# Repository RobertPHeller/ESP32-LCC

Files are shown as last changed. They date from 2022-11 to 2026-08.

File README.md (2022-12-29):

# ESP32-LCC

This is a collection of Model Railroad open hardware and open source projects,
using LCC /  OpenMRNIDF, for the ESP32 family of MCUs

These projects were created using Kicad 2013.06.11
(https://launchpad.net/kicad) under CentOS 6 and Kicad 4.0.7 under Ubuntu
18.04. Each subdirectory is one project, and contains a schematic and PCB
design or contains a program for one (or more) projects. There is also
software for the boards using OpenMRNIDF (C++ library for OpenLCB/LCC) for these
projects.

There is a README in each project dir.

1. [ESP32-16LedDriver](https://github.com/RobertPHeller/RPi-RRCircuits/tree/master/ESP32-16LedDriver)

    > 16 on/off LED Driver board using a MCP23017.

1. [ESP32-16PWMLedDriver](https://github.com/RobertPHeller/RPi-RRCircuits/tree/master/ESP32-16PWMLedDriver)

    > 16 LED PWM driver board using a PCA9685.

1. [ESP32-16xDCCOD](https://github.com/RobertPHeller/RPi-RRCircuits/tree/master/ESP32-16xDCCOD)

    > Backplane for up to 16 DCCOD_SMD's using a ESP32 MCU.  Meant as a thought 
    > experiment to see what this would cost, etc.

1. [ESP32-D0WD-V3-MultiFunctionOpenMRNIDF](https://github.com/RobertPHeller/RPi-RRCircuits/tree/master/ESP32-D0WD-V3-MultiFunctionOpenMRNIDF)

    > 

1. [ESP32-HalfSiding](https://github.com/RobertPHeller/RPi-RRCircuits/tree/master/ESP32-HalfSiding)

    > First draft of a ESP32 HalfSiding node using a MCP23017 on/off signal lamps.

1. [ESP32-MultiFunction](https://github.com/RobertPHeller/RPi-RRCircuits/tree/master/ESP32-MultiFunction)

    > This is a circuit board that supports an ESP32 Dev Kit board or TTGO-T1 board
    > to manage a range of possible interlocking plants or other model railroad
    > situations. It contains four stall motor drivers with point sense, four CT
    > Coil type occupancy detectors, four Schmitt-Trigger inputs (for push buttons),
    > four driver outputs, and 16 PWM LED drivers.

1. [ESP32-PWMHalfSiding](https://github.com/RobertPHeller/RPi-RRCircuits/tree/master/ESP32-PWMHalfSiding)

    > This is a circuit board that supports an ESP32 Dev Kit board or TTGO-T1 board 
    > to manage one half (one end) of a siding.  This board can also be used to 
    > manage two bi-directional single track ABS blocks or one bi-directional dual 
    > track ABS block.  There are other trackwork cases this board can handle as 
    > well.  

1. [ESP32-PWMHalfSidingSMD](https://github.com/RobertPHeller/RPi-RRCircuits/tree/master/ESP32-PWMHalfSidingSMD)

    > This is a circuit board that supports an ESP32 Dev Kit board or TTGO-T1 board 
    > to manage one half (one end) of a siding.  This board can also be used to 
    > manage two bi-directional single track ABS blocks or one bi-directional dual 
    > track ABS block.  There are other trackwork cases this board can handle as 
    > well.  

1. [ESP32-S3-MultiFunction](https://github.com/RobertPHeller/RPi-RRCircuits/tree/master/ESP32-S3-MultiFunction)

    > This is a LCC node circuit board that is based around an Espressif ESP32-S3FN8
    > MCU to manage and operate a collection of model railroad sensors and
    > actuators. 

1. [ESP32-S3-MultiFunctionOpenMRNIDF](https://github.com/RobertPHeller/RPi-RRCircuits/tree/master/ESP32-S3-MultiFunctionOpenMRNIDF)

    > 

1. [ESP32_mini_KiCad_Library](https://github.com/RobertPHeller/RPi-RRCircuits/tree/master/ESP32_mini_KiCad_Library)

    > KiCad symbol and footprint for the ESP32 Mini, the ESP32 clone of the Wemos D1 mini with more pins and more power!
    > There is some info on the boards [here](https://www.reddit.com/r/esp8266/comments/a93raj/wemos_ttgo_mini_d1_esp32/). It seems to be a Wemos clone, but is def. not made by them. I really like the boards for the small size and cheap price while giving me the power of an ESP32 and much more IO compared to the Wemos D1 mini.

1. [ESP32ABSBoard](https://github.com/RobertPHeller/RPi-RRCircuits/tree/master/ESP32ABSBoard)

    > ESP32 ABS (Automatic Block Signal) board.  Very simple board: one block 
    > detector, 8 LED drivers.

1. [ESP32BaseBoard](https://github.com/RobertPHeller/RPi-RRCircuits/tree/master/ESP32BaseBoard)

    > ESP32 Base board.  Base starting point for a ESP32 node.

1. [ESP32MRNSketches](https://github.com/RobertPHeller/RPi-RRCircuits/tree/master/ESP32MRNSketches)

    > ESP32 Arduino / OpenMRNLite sketches for the ESP32 boards.

1. [ESP32QuadOCDect](https://github.com/RobertPHeller/RPi-RRCircuits/tree/master/ESP32QuadOCDect)

    > ESP32 Quad Occupancy Detector node.

1. [ESP32QuadSMCSense](https://github.com/RobertPHeller/RPi-RRCircuits/tree/master/ESP32QuadSMCSense)

    > ESP32 Quad Stall Motor w/ sense node.

1. [OpenMRNIDF](https://github.com/RobertPHeller/RPi-RRCircuits/tree/master/OpenMRNIDF)

    > This is an exported version of the OpenMRN library for the ESP32 which is
    > usable as an ESP-IDF component.

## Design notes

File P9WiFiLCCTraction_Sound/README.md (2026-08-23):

# JST 9-Pin WiFi LCC Traction Node 

This is a WiFi LCC Traction Node that has a DCC standard JST 9-pin connecter.

It has support for 4 function outputs.

Schematic

Board 3D View

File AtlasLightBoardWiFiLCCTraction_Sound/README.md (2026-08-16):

# Atlas Light Board WiFi LCC Traction Node

This is a WiFi LCC Traction Node that is a drop in replacement for any HO 
diesel loco that has mounting for a DCC decoder like the NCE DA-SR or TCS A4X,
that is the Atlas Light Board DCC decoders.

It has support for 6 function outputs.

Schematic

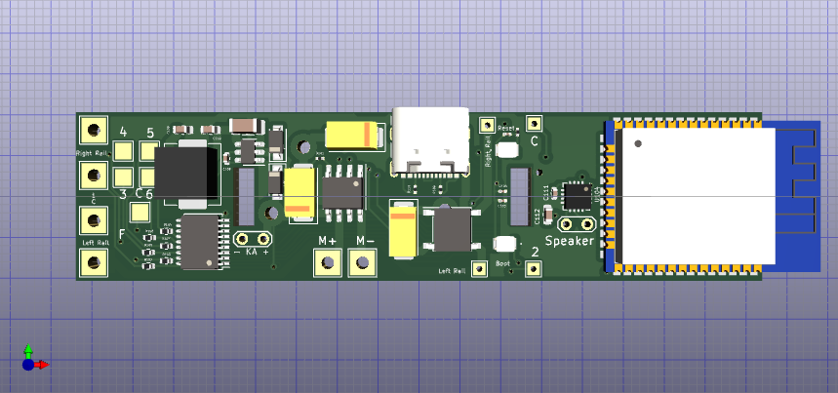
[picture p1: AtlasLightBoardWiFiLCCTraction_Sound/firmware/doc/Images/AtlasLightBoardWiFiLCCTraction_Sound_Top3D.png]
Board 3D View


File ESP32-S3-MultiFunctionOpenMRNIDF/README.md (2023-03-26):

# ESP32-S3-MultiFunctionOpenMRNIDF

This is the firmware for various ESP32S3-based "MultiFunction" LCC Node 
boards.
Boards this software will work for include:

- [ESP32-S3-MultiFunction](https://github.com/RobertPHeller/ESP32-LCC/tree/master/ESP32-S3-MultiFunction) The original S3-MultiFunction board using a "bare"
  ESP32-S3FN8 chip.
- [ESP32-T7S3-MultiFunction](https://github.com/RobertPHeller/ESP32-LCC/tree/master/ESP32-T7S3-MultiFunction) A version of the original S3-MultiFunction board
  using a TTGO-T7S3 module.
- [ESP32-T7S3-MultiFunctionUniversalTurnout](https://github.com/RobertPHeller/ESP32-LCC/tree/master/ESP32-T7S3-MultiFunctionUniversalTurnout) A version of the 
  T7S3-MultiFunction board using a daughter board for the turnout driver
  allowing four different turnout types (Stall Motor, Single Coil, 
  Twin Coil, and Servo).
- This code will also work on a breadboard version using a ESP32S3 DevKit 
  board.

There are configuration options to adjust how the code is compiled for 
different hardware options.

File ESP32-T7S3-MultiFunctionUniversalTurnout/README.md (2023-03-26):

# ESP32-T7S3-MultiFunctionUniversalTurnout

This is a LCC node circuit board that is based around an Lily Go TTGO-T7S3
(Mini32) board to manage and operate a collection of model railroad sensors and
actuators. 

The board contains these I/O sections:

- Four occupancy detectors. CT Coil type sensors, so they won't work with DC
systems without an AC bias.
- Four turnout drivers with point sense.  These are on a daughter board.  There
are four daughter board types: one for stall motors (Tortoise and the like),
one for single-coil motors (Kato), one for twin-coil motors (Atlas, Peco), and
one for servos.
- Four Schmitt Trigger inputs, meant for push buttons.
- Four Buffered outputs, by default for Panel LEDS, but with drop in
resistors, can also drive relays or other loads.
- Sixteen PWM Led drivers. These are meant to light (LED) lamps in signal
heads.

The board connects to a LCC network and utilizes the Event Transport Protocol
in its operation. It also uses a CDI to describe its configuration. It can be
configured with JMRI or other available LCC configuration tools.

The board draws about 100ma, plus load. There are 16 signal lamp outputs that
have 1.5K Ohm load resistors, this means about 8ma per LED. If all lamps are
on at full brightness, this comes to 128ma, although turning all 16 signal
lamps on full at a time is not likely to be prototypical, since most signal
aspects only light one lamp per head. There is a terminal block to optionally
supply external power for the signal lamps, as a way to reduce the load on the
LCC power bus. The buffered output section uses an external power source, so
does not add any load to the LCC power bus.

This board is a multi-purpose board that can be used in a number of
situations, including (but not limited to): one end of a siding, a yard or
terminal throat, ABS, and interlocking plants.</p>

## Firmware

The firmware for this board is [ESP32-S3-MultiFunctionOpenMRNIDF](https://github.com/RobertPHeller/ESP32-LCC/tree/master/ESP32-S3-MultiFunctionOpenMRNIDF).

## Kit booket

There is LaTeX source for the kit booklet in [KitBooklet](https://github.com/RobertPHeller/ESP32-LCC/tree/master/ESP32-T7S3-MultiFunctionUniversalTurnout/KitBooklet).

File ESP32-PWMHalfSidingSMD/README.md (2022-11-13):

# ESP32-PWMHalfSidingSMD

This is a circuit board that supports an ESP32 Dev Kit board or TTGO-T1 board 
to manage one half (one end) of a siding.  This board can also be used to 
manage two bi-directional single track ABS blocks or one bi-directional dual 
track ABS block.  There are other trackwork cases this board can handle as 
well.  

[Order this board as a kit from The Country Robot](https://www.thecountryrobot.com/product/esp32-pwm-half-siding-node-kit/)

The board contains these I/O sections:

- Two occupancy detectors.  These are optoisolator based, so they will 
  work for both DC and DCC systems.
- Two stall-motor with point sense.
- Sixteen PWM Led drivers.  These are meant to light lamps in signal 
  heads.

This board uses six GPIO pins and one I2C channel:

- **GPIO0** Motor Select 1: select the position of stall motor 1.
- **GPIO12** Motor Select 2: select the position of stall motor 2.
- **GPIO34** Point Sense 1: return the state of the points for 
  stall motor 1. 
- **GPIO35** Point Sense 2: return the state of the points for 
  stall motor 2. 
- **GPIO26** Occupancy Detector 1.
- **GPIO27** Occupancy Detector 2.
- **GPIO16** (Optional) Output enable for the PWM LED Controller.
- **I2C Address 0x40** A PCA9685 16-channel, 12-bit PWM LED Controller.

Each of the motor drive circuits is through a TC4428, which can drive up to
1.5A, which is way more needed to drive a typical stall motor. It is enough to
drive a pair of stall motors, wired in parallel as would be the case for a
cross over. 

## Circuit Description

[ESP32-PWMHalfSidingSMD.pdf](https://github.com/RobertPHeller/RPi-RRCircuits/blob/master/ESP32-PWMHalfSidingSMD/ESP32-PWMHalfSidingSMD.pdf
)

### Turnout Control

The turnout control has two parts. There is an output section that contains
two TC4428 chips. Each chip has a non-inverting and an inverting driver. The
inputs of both drivers are connected to one of the motor GPIO pins. The output
are wired to the terminal block for a one of the motors. For any given logic
state of the motor control output, one of the drivers is ``on'' and the other
is ``off'', thus one motor terminal is ground and one is raised to the 12V
supply. This means alternative states of the logic line will drive the stall
motor in alternative directions. 

The other section is a pair of flip-flop debounce circuits, one for each of
two SPDT switch contacts that report the position of the turnout points. The
output of these flip-flops goes to a pair of GPIO input pins.

### CAN Transceiver

This section contains the CAN Transceiver, along with a termination jumper 
block. Power insertion and pick off and the RJ45 Jacks.

### Power Supply

This section contains a 5V power supply that takes the nominal 12V on the CAN 
power bus and regulates it down to 5V to supply the ESP32 MCU board.

### Occupancy Detectors

The occupancy detectors use optoisolators in series with the track power 
supply.  There is a heavy duty bridge rectifier in parallel with the 
optoisolators to carry the bulk of the current to the track.  They will work 
with either DC or DCC track power.

### PWM LED Driver

The PWM LED Driver uses a PCA9685 which is a 16 channel, 12 bit PWD LED 
driver.  A pair of octal MOSFET drivers and series load resistors are also 
included on the board.  The MOSFET drivers come in both inverting (low-side 
drive) and non-inverting (high-side drive), so it is possible to support both 
common anode and common cathode LED signals.  

## User Installed Parts

|Index|Qty|Refs|Mouser Part Number|Description| 
|---|----|---|---|---|
1|2|J1, J2|710-615008144221|RJ45 Jacks|
2|1|JP1|649-67997-404HLF|Termination Jumper|
3|2|P601, P602|651-1725724|Signal Lamp Terminals|
4|3|T1, T2, T601|651-1725656|LCC and Signal power|
5|2|T3, T6|490-TB007-508-02BE|Occupancy Terminals|
6|2|T4, T5|651-1725685|Turnout terminals|
7|2|U0|517-929974-01-19-RK|MCU Headers|
8|1|U0|517-929850-01-18-10|MCU Headers|

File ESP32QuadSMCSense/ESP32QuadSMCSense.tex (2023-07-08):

%%%%%%%%%%%%%%%%%%%%%%%%%%%%%%%%%%%%%%%%%%%%%%%%%%%%%%%%%%%%%%%%%%%%%%%%%%%%%
%
%  System        : 
%  Module        : 
%  Object Name   : $RCSfile$
%  Revision      : $Revision$
%  Date          : $Date$
%  Author        : $Author$
%  Created By    : Robert Heller
%  Created       : Mon Nov 25 10:02:10 2019
%  Last Modified : <230701.1407>
%
%  Description 
%
%  Notes
%
%  History
% 
%%%%%%%%%%%%%%%%%%%%%%%%%%%%%%%%%%%%%%%%%%%%%%%%%%%%%%%%%%%%%%%%%%%%%%%%%%%%%
%
%    Copyright (C) 2019  Robert Heller D/B/A Deepwoods Software
%			51 Locke Hill Road
%			Wendell, MA 01379-9728
%
%    This program is free software; you can redistribute it and/or modify
%    it under the terms of the GNU General Public License as published by
%    the Free Software Foundation; either version 2 of the License, or
%    (at your option) any later version.
%
%    This program is distributed in the hope that it will be useful,
%    but WITHOUT ANY WARRANTY; without even the implied warranty of
%    MERCHANTABILITY or FITNESS FOR A PARTICULAR PURPOSE.  See the
%    GNU General Public License for more details.
%
%    You should have received a copy of the GNU General Public License
%    along with this program; if not, write to the Free Software
%    Foundation, Inc., 675 Mass Ave, Cambridge, MA 02139, USA.
%
% 
%
%%%%%%%%%%%%%%%%%%%%%%%%%%%%%%%%%%%%%%%%%%%%%%%%%%%%%%%%%%%%%%%%%%%%%%%%%%%%%

\chapter{ESP32QuadSMCSense: Quad Motor Control and Sense base board for an ESP32 Dev Kit MCU board}

This is a circuit board that supports an ESP32 Dev Kit board or TTGO-T1 board
controlling four stall-motor turnout motors for a model railroad. It also has
sense logic to return the state of the turnouts, using one pole of the DPDT
contacts in the stall-motor (typical of Tortoise stall-motors). This circuit
board provides connections to a LCC CAN network via RJ45 connectors, the
ability to inject and extract 12V power from the LCC CAN network, and a 5V
power supply from the LCC CAN network 12V power bus.

\section{GPIO Pins Used.}

This board uses eight GPIO pins:

\begin{description}
\item[GPIO0] Motor Select 1: select the position of stall motor 
1. 
\item[GPIO12] Motor Select 2: select the position of stall motor 
2. 
\item[GPIO34] Point Sense 1: return the state of the points for 
stall motor 1. 
\item[GPIO35] Point Sense 2: return the state of the points for 
stall motor 2. 
\item[GPIO15] Motor Select 3: select the position of stall motor 
3. 
\item[GPIO25] Motor Select 4: select the position of stall motor 
4. 
\item[GPIO32] Point Sense 3: return the state of the points for 
stall motor 3. 
\item[GPIO33] Point Sense 4: return the state of the points for 
stall motor 4. 
\end{description}

Each of the motor drive circuits is through a TC4428, which can drive up to
1.5A, which is way more needed to drive typical stall motor. It is enough to
drive a pair of stall motors, wired in parallel as would be the case for a
cross over. 

\section{Circuit Description}

\begin{figure}[hbpt]\begin{centering}%

\caption{Circuit Diagram of the ESP32QuadSMCSense, page 1 (ESP32 MCU and Driver and Sense)}
\end{centering}\end{figure}
\begin{figure}[hbpt]\begin{centering}%

\caption{Circuit Diagram of the ESP32QuadSMCSense, page 2 (CAN Transceiver)}
\end{centering}\end{figure}
\begin{figure}[hbpt]\begin{centering}%

\caption{Circuit Diagram of the ESP32QuadSMCSense, page 3 (Power Supply)}
\end{centering}\end{figure}
This circuit contains two sections.  There is an output section that contains 
four TC4428 chips.  Each chip has a non-inverting and an inverting driver. The 
inputs of both drivers are connected to one of the motor GPIO pins.  The 
output are wired to the terminal block for a one of the motors. For any given 
logic state of the motor control output, one of the drivers is ``on'' and the 
other is ``off'', thus one motor terminal is ground and one is raised to the 
12V supply.  This means alternative states of the logic line will drive the 
stall motor in alternative directions.

The other section is a quartet of flip-flop debounce circuits, one for each
of two SPDT switch contacts that report the position of the turnout points.
The output of these flip-flops goes to a quartet of GPIO input pins.

Also on the board is a CAN Transceiver and power supply for the Pocket Beagle.

\section{Parts List}

\begin{table}[htp]
\begin{centering}\begin{tabular}{|l|l|p{1in}|l|p{.5in}|}
\hline
Value&Quantity&References&Mouser Part Number \\
\hline
.1 uf&2&C1 C2&581-SR201C104KARTR1 \\
\hline
10 uf 35V&1&C3&667-ECA-1HM100I \\
\hline
RPi\_GPIO&1&J0&855-M20-6102045 \\
\hline
10K Ohms&1&RR1&652-4609X-1LF-10K \\
\hline
Motor 1;Motor 2;Motor 3;Motor 4&4&T1 T2 T3 T4&651-1725685 \\
\hline
+ 12V -&1&T5&651-1725656 \\
\hline
TC4428&4&U1 U2 U3 U4&579-TC4428VPA \\
\hline
74HCT00&2&U5 U6&595-SN74AHC00N \\
\hline
.1 uf&1&C1&21RZ310-RC\\
\hline
15 uf 63V&1&C2&710-860080773002\\
\hline
47 nf&1&C3&75-1C10Z5U473M050B\\
\hline
SB240E&2&D1 D2&625-SB240-E3\\
\hline
RJ45&2&J1 J2&710-615008144221\\
\hline
Termination&1&JP1&649-67997-404HLF\\
\hline
60 Ohms&2&R1 R2&71-RN60C60R0B/R\\
\hline
+ 15 in -;+ 15 out -&2&T1 T2&651-1725656\\
\hline
TCAN332DR&1&U1&595-TCAN332DR\\
\hline
SN65HVD233-HT&1&U2&595-SN65HVD233SJD\\
\hline
220 uf 25V&1&C4&140-REA221M1EBK0811P\\
\hline
22 uf 100V&1&C5&140-REA220M2ABK0811P\\
\hline
SB160-E3/54&1&D3&625-SB160-E3\\
\hline
330 uh&1&L1&PE-52627NL\\
\hline
LM2574N-5.0&1&U3&926-LM2574N-5.0/NOPB\\
\hline
\end{tabular}
\caption{Parts list for ESP32QuadSMCSense board.}
\end{centering}\end{table}\footnote{Mouser Project link: 
\url{http://www.mouser.com/ProjectManager/ProjectDetail.aspx?AccessID=330542c522},
\url{http://www.mouser.com/ProjectManager/ProjectDetail.aspx?AccessID=82b1e6b259}, and
\url{http://www.mouser.com/ProjectManager/ProjectDetail.aspx?AccessID=ae58a2d985}.}

The only parts that might be substituted are T1 though T4 (the Motor
terminals) and T5 (the 12 to 16 Volts terminals). The parts listed are for
screw terminals for the Motor terminals and the motor power terminals. Feel
free to select either pin arrays or spring terminals for the T1, T2, T3, T4
and T5. You only need one CAN transciever. One of the parts is a through hole
version (which is much more expensive) and the other is SMD. The SMD part can
be hand soldered. The board supports using either a pair a 18-pin headers for
a TTGO-T1 MCU board or a pair a 19-pin headers for a ESP32 Dev Kit Board.

\section{Circuit Board Layout}

\begin{figure}[hbpt]\begin{centering}%

\caption{3D rendering of the ESP32QuadSMCSense board}
\end{centering}\end{figure}
\begin{figure}[hbpt]\begin{centering}%

\caption{Fabrication image of the ESP32QuadSMCSense board}
\end{centering}\end{figure}
Board assembly is straight forward. You need to be careful orienting the ICs
and the electrolytic capacitor.

Bare circuit boards can be ordered from PCBWay here: 
\url{https://www.pcbway.com/project/shareproject/ESP32QuadSMCSense.html}.

\section{Downloadables and Software Support}

Full design information is available on GitHub here:
\url{https://github.com/RobertPHeller/RPi-ESP32-LCC/tree/master/ESP32QuadSMCSense}.

An OpenMRN Lite program that supports this board is available here:
\url{https://github.com/RobertPHeller/RPi-ESP32-LCC/tree/master/ESP32MRNSketches/ESP32QuadSMCSense}
\footnote{Building OpenMRN Lite programs with the Arduino IDE is presently 
broken, but the source code could be ported to build with Mike Dunston's 
OpenMRNIDF and Esspressif's IDF.}.

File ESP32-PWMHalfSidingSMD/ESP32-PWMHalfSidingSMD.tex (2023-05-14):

%%%%%%%%%%%%%%%%%%%%%%%%%%%%%%%%%%%%%%%%%%%%%%%%%%%%%%%%%%%%%%%%%%%%%%%%%%%%%
%
%  System        : 
%  Module        : 
%  Object Name   : $RCSfile$
%  Revision      : $Revision$
%  Date          : $Date$
%  Author        : $Author$
%  Created By    : Robert Heller
%  Created       : Thu May 20 07:35:55 2021
%  Last Modified : <230514.0938>
%
%  Description 
%
%  Notes
%
%  History
% 
%%%%%%%%%%%%%%%%%%%%%%%%%%%%%%%%%%%%%%%%%%%%%%%%%%%%%%%%%%%%%%%%%%%%%%%%%%%%%
%
%    Copyright (C) 2021  Robert Heller D/B/A Deepwoods Software
%			51 Locke Hill Road
%			Wendell, MA 01379-9728
%
%    This program is free software; you can redistribute it and/or modify
%    it under the terms of the GNU General Public License as published by
%    the Free Software Foundation; either version 2 of the License, or
%    (at your option) any later version.
%
%    This program is distributed in the hope that it will be useful,
%    but WITHOUT ANY WARRANTY; without even the implied warranty of
%    MERCHANTABILITY or FITNESS FOR A PARTICULAR PURPOSE.  See the
%    GNU General Public License for more details.
%
%    You should have received a copy of the GNU General Public License
%    along with this program; if not, write to the Free Software
%    Foundation, Inc., 675 Mass Ave, Cambridge, MA 02139, USA.
%
% 
%
%%%%%%%%%%%%%%%%%%%%%%%%%%%%%%%%%%%%%%%%%%%%%%%%%%%%%%%%%%%%%%%%%%%%%%%%%%%%%

\chapter{ESP32-PWMHalfSidingSMD: Half Siding board base board for an ESP32 Dev Kit MCU board}

This is a circuit board that supports an ESP32 Dev Kit board or TTGO-T1 board 
to manage one half (one end) of a siding.  This board can also be used to 
manage two bi-directional single track ABS blocks or one bi-directional dual 
track ABS block.  There are other trackwork cases this board can handle as 
well.  The board contains these I/O sections:

\begin{itemize}
\item Two occupancy detectors.  These are opto-isolator based, so they will 
work for both DC and DCC systems.
\item Two stall-motor with point sense.
\item Sixteen PWM Led drivers.  These are meant to light lamps in signal 
heads.
\end{itemize}

This board uses six GPIO pins and one I2C channel:

\begin{description}
\item[GPIO0] Motor Select 1: select the position of stall motor 1.
\item[GPIO12] Motor Select 2: select the position of stall motor 2.
\item[GPIO34] Point Sense 1: return the state of the points for 
stall motor 1. 
\item[GPIO35] Point Sense 2: return the state of the points for 
stall motor 2. 
\item[GPIO26] Occupancy Detector 1.
\item[GPIO27] Occupancy Detector 2.
\item[GPIO16] (Optional) Output enable for the PWM LED Controller.
\item[I2C Address 0x40] A PCA9685 16-channel, 12-bit PWM LED Controller.
\end{description}

Each of the motor drive circuits is through a TC4428, which can drive up to
1.5A, which is way more needed to drive a typical stall motor. It is enough to
drive a pair of stall motors, wired in parallel as would be the case for a
cross over. 

\section{Circuit Description}

\subsection{Turnout Control}
\begin{figure}[hbpt]\begin{centering}%

\caption{Circuit Diagram of the ESP32-PWMHalfSidingSMD, page 1 (ESP32 MCU and 
Turnout Driver and Sense)}
\end{centering}\end{figure}

The turnout control has two parts. There is an output section that contains
two TC4428 chips. Each chip has a non-inverting and an inverting driver. The
inputs of both drivers are connected to one of the motor GPIO pins. The output
are wired to the terminal block for a one of the motors. For any given logic
state of the motor control output, one of the drivers is ``on'' and the other
is ``off'', thus one motor terminal is ground and one is raised to the 12V
supply. This means alternative states of the logic line will drive the stall
motor in alternative directions. 

The other section is a pair of flip-flop debounce circuits, one for each of
two SPDT switch contacts that report the position of the turnout points. The
output of these flip-flops goes to a pair of GPIO input pins.

\clearpage
\subsection{CAN Transceiver}
\begin{figure}[hbpt]\begin{centering}%

\caption{Circuit Diagram of the ESP32-PWMHalfSidingSMD, page 2 (CAN Transceiver)}
\end{centering}\end{figure}

This section contains the CAN Transceiver, along with a termination jumper 
block. Power insertion and pick off and the RJ45 Jacks.

\clearpage
\subsection{Power Supply}
\begin{figure}[hbpt]\begin{centering}%

\caption{Circuit Diagram of the ESP32-PWMHalfSidingSMD, page 3 (Power Supply)}
\end{centering}\end{figure}

This section contains a 5V power supply that takes the nominal 12V on the CAN 
power bus and regulates it down to 5V to supply the ESP32 MCU board.

\clearpage
\subsection{Occupancy Detectors}
\begin{figure}[hbpt]\begin{centering}%

\caption{Circuit Diagram of the ESP32-PWMHalfSidingSMD, page 4 (Occupancy 
Detector 1)}
\end{centering}\end{figure}
\begin{figure}[hbpt]\begin{centering}%

\caption{Circuit Diagram of the ESP32-PWMHalfSidingSMD, page 5 (Occupancy 
Detector 2)}
\end{centering}\end{figure}

The occupancy detectors use optoisolators in series with the track power 
supply.  There is a heavy duty bridge rectifier in parallel with the 
optoisolators to carry the bulk of the current to the track.  They will work 
with either DC or DCC track power.

\clearpage
\subsection{PWM LED Driver}
\begin{figure}[hbpt]\begin{centering}%

\caption{Circuit Diagram of the ESP32-PWMHalfSidingSMD, page 6 (PWM LED Driver)}
\end{centering}\end{figure}

The PWM LED Driver uses a PCA9685 which is a 16 channel, 12 bit PWD LED 
driver.  A pair of octal MOSFET drivers and series load resistors are also 
included on the board.  The MOSFET drivers come in both inverting (low-side 
drive) and non-inverting (high-side drive), so it is possible to support both 
common anode and common cathode LED signals.

\clearpage
\section{User Installed Parts}

\begin{centering}\begin{tabular}{|r|l|l|p{1.5in}|p{1.5in}|}
\hline
Index&Qty&Refs&Mouser Part Number&Description\\   
\hline
1&2&J1, J2&710-615008144221&RJ45 Jacks\\
\hline
2&1&JP1&649-67997-404HLF&Termination Jumper -- 2x2 pin header\\
\hline
3&1&J3&649-1012937890304BLF&I2C SCL Select Jumper -- 3-pos 2.54 pitch pin header\\
\hline
4&2&P601, P602&651-1725724&Signal Lamp Terminals -- 9-pos 2.54 pitch screw terminals\\
\hline
5&3&T1, T2, T601&651-1725656&LCC and Signal power -- 2-pos 2.54 pitch screw terminals\\
\hline
6&2&T3, T6&490-TB007-508-02BE&Occupancy Terminals -- 2-pos 5.08 pitch screw terminals\\
\hline
7&2&T4, T5&651-1725685&Turnout terminals -- 5-pos 2.54 pitch screw terminals\\
\hline
8&2&U0&517-929974-01-19-RK&MCU Headers -- 19x1 pin socket headers\\
\hline
9&1&U0&517-929850-01-18-10&MCU Headers -- 18x1 pin socket headers\\
\hline
\end{tabular}\end{centering}

\section{Circuit Board Layout}
\begin{figure}[hbpt]\begin{centering}%

\caption{Fabrication image of the ESP32-PWMHalfSiding board}
\end{centering}\end{figure}
\begin{figure}[hbpt]\begin{centering}%

\caption{3D image of the ESP32-PWMHalfSiding board}
\end{centering}\end{figure}

\subsection{Notes on Building the board}
\begin{figure}[hbpt]\begin{centering}%

\caption{Placement of terminal blocks, connectors, and jumper blocks.}
\end{centering}\end{figure}

The board comes with all the surface mount devices soldered to the board.  All 
you need to do is solder the through-hole parts, which consists of:

\begin{description}
\item[Screw Terminals] 3 2-position 2.54 pitch terminals (LCC power in and
out, lamp power in), 2 5-position 2.54 pitch terminals (motor 1 and motor
2), 2 9-position 2.54 pitch terminals (signal lamp outputs), and 2 2-position
5.08 pitch terminals (Occ. Det. 1 and Occ. Det. 2). 
\item[Pin Headers] 1 2x2 pin header (termination jumpers) and 1 1x3 pin header
(I2C SCL GPIO selection).
\item[Connectors] 2 RJ45 connectors (LCC Network).
\item[Pin Socket Headers] 2 19x1 and 1 18x1, for the MCU module.
\end{description}

For most of these parts you should solder one pin and then while pressing the
part against the board, reflow the solder to make sure the part is tight and
square to the board before letting the solder cool while holding the part
tight to the board. Before soldering the rest of the pins, check that the part
is fully tight and flush to the board. Also for the screw terminals, make sure
the wire openings are facing out from the board. The install ordering is from
shortest to tallest parts.

\clearpage
\section{Downloadables and Software Support}

As shipped, the TTGO-T1 has already had the ESP32-PWMHalfSiding firmware
installed, but if you want to rebuild the code (possibly with customizations)
the code is on GitHub in my ESP32-LCC repo:
\url{https://github.com/RobertPHeller/ESP32-LCC}, in the
ESP32-PWMHalfSidingOpenMRNIDF sub-folder. You will need the Espressif's IoT
Development Framework, version 5.0.1 or later, available from
\url{https://github.com/espressif/esp-idf}. The ESP32-PWMHalfSidingOpenMRNIDF
also uses Mike Dunston's OpenMRNIDF module.

\subsection{Building and installing the software}

Once you have installed Espressif's IoT Development Framework and cloned the 
ESP32-LCC repo, you can build the software by cd'ing to the 
ESP32-PWMHalfSidingOpenMRNIDF and in bash running these commands:

\begin{verbatim}
. path-to-Espressifs-IDF/export.sh
idf.py build
\end{verbatim}

You can then use the idf.py's flash command to flash the TTGO-T1.

\subsubsection{WiFi notes}

The default configuration is with WiFi disabled. Using both the CAN interface
\textbf{and} WiFi at the same time on the ESP32 is not recomended. The
processor cannot handle both well. 

\subsection{Program Description}

The program consists of a main sketch file, and several support files and
``components'' (libraries).

\subsection{Program Startup notes}

While most of the common node configuration is accessable using the available
CDI configuruation tools (JMRI's PanelPro program or MRR SYS OpenLCB program), 
some of the node's configuration is in separate non-volitle (flash) memory.  
This includes the node's ID number and some boot options.  As installed the 
node ID is initialized to 05:01:01:01:22:00.  \textbf{You don't really want to 
leave this as the node id!}  There are two ways to set the node id.  One way 
is to use a CDI configuruation tool -- the node ID is exposed as a 
configuration option.  Changing the node id forces a ``factory reset'' on the 
next boot (and when you update the configuration with a CDI configuruation 
tool, the node will reboot).  The other way is during the boot up process.  
When the node boots, it waits on the USB serial connection for 10 seconds for 
any ``keyboard'' response and if it gets a ``keyboard'' response, it enters a 
simple command line loop accepting simple commands (mostly single letters). 
To use this feature you need to connect a a USB cable between the TTGO-T1 and 
a computer (eg a PC or Mac) and then connect to the USB Com port with a 
terminal program (the Arduino IDE Serial Monitor should work).  The commands 
that the boot startup command line loop supports are:

\begin{itemize}
\item \textbf{N} Set the node id.  Follow the ``N'' with a 12 digit hex 
number, with optional periods or colons.  Causes a Factory Reset.
\item \textbf{E} Reset events on boot up.
\item \textbf{F} Force a Factory Reset.
\item \textbf{S} WiFi ssid\footnote{Only useful if WiFi is 
enabled.\label{fn:wifi}}. Enter the ssid after the ``S'', leading and trailing 
spaces are stripped off.
\item \textbf{P} WiFi password\footref{fn:wifi}. Enter the password after the 
``P'', leading and trailing spaces are stripped off.
\item \textbf{H} Hostname prefix\footref{fn:wifi}. Enter the hostname prefix 
after the ``H'', leading and trailing spaces are stripped off. The NODE ID in 
hex is appended.  Hostnames are limited to 32 characters.
\item \textbf{W} Enable WiFi\footref{fn:wifi}. Enter ``YES'', ``NO'', 
``ON'', or ``OFF'' after the ``W''.
\item \textbf{T} Test signal lamps\footnote{Each of the signal lamps is 
flashed for 1 second during boot up.}.
\item \textbf{R} Resume.
\end{itemize}

\section{General Wiring Notes}

There are various terminal blocks, connectors, and jumper blocks on this
board. At the top right corner of the board are a pair of two position
terminal blocks, one for injecting power into the LCC bus and one for
extracting power from the LCC bus. Between these terminal blocks is the
termination jumper block for the LCC bus. Below the LCC power terminal blocks
is a pair of RJ45 connectors. These are for connecting the board to the LCC
bus. These connectors are wired in parallel. Down along the left side are the
two stall motor terminal blocks (small 5 position terminal blocks) and the
occupancy detector terminal blocks (large 2 position terminal blocks). On the
right side are two 9 position terminal blocks for the signal lamp LEDs.
Finally, between the terminal blocks for the signal lamp LEDs is a two
position terminal block to (optionally) provide power for the signal lamp
LEDs.

\subsection{LCC Power}

Power can be optionally injected into the LCC bus or extracted from the LCC 
bus. Power can be injected to into the LCC bus to power this and other boards. 
Power can also be extracted to power local devices.

\subsection{I2C SCL GPIO Selection}

\begin{figure}[hbpt]\begin{centering}%

\caption{I2C SCL Jumper Options}
\label{fig:ESP32-PWMHalfSidingI2CSCLJumper}
\end{centering}\end{figure}
There is a jumper to selecting the GPIO pin to use for I2C SCL line.  If you 
are using an ESP32 DevKit you would use GPIO 22.  If you are using a Lily Go 
TTGO-T1, you might want to use GPIO 23 since GPIO 22 on the TTGO-T1 is wired 
to its on-board LED and this has been known to cause issues with the I2C 
interface.  If you select Arduino IDE's board type ``TTGO-T1'', SCL is mapped 
to GPIO 23 -- it is possible to select the generic ESP32 DevKit as the board 
type to compile for the ``TTGO-T1'', in which case SCL is mapped to GPIO 22.  
You should install a shunt jumper that matches how you compiled the firmware.

\subsection{LCC Bus connections and termination}

\begin{figure}[hbpt]\begin{centering}%

\caption{Termination Jumper Options}
\label{fig:ESP32-PWMHalfSidingTermination}
\end{centering}\end{figure}
The two RJ45 connections connect to the LCC bus.  If this board is at the end 
of bus, you will need to terminate the bus.  There are two possible 
termination options as shown in 
Figure~\ref{fig:ESP32-PWMHalfSidingTermination}.

\subsection{Stall Motor connections}

\begin{figure}[hbpt]\begin{centering}%

\caption{Stall Motor terminal block connections}
\label{fig:ESP32-PWMHalfSidingTurnoutMotorsFig}
\end{centering}\end{figure}
\begin{figure}[hbpt]\begin{centering}%

\caption{Wiring a Tortoise to the ESP32-PWMHalfSiding Turnout Motors terminals}
\label{fig:ESP32-PWMHalfSidingTotoiseWiring}
\end{centering}\end{figure}
The five position Stall Motor terminal blocks, shown in 
Figure~\ref{fig:ESP32-PWMHalfSidingTurnoutMotorsFig}, connect to the turnout 
stall motors, the Motor A and Motor B connections go to the motor (pins 1 and 
8 of a tortoise), the other three connections go to a single pole double 
through switch contacts to sense the position of the stall motor / points. 
There are contacts available on tortoise stall motor that can be used for this 
purpose, as shown in Figure~\ref{fig:ESP32-PWMHalfSidingTotoiseWiring}.

\clearpage
\subsection{Occupancy Detector connections}

\begin{figure}[hbpt]\begin{centering}%

\caption{Occupancy Detector Wiring}
\label{fig:ESP32-PWMHalfSidingOccupancyDetectors}
\end{centering}\end{figure}
The larger two position Occupancy Detector terminal blocks are connected to 
the track power feeds as shown in 
Figure~\ref{fig:ESP32-PWMHalfSidingOccupancyDetectors}.

\clearpage
\subsection{Signal Lamp (LED) connections}

\begin{figure}[hbpt]\begin{centering}%

\caption{Typical Signal Lamp Diver Wiring}
\label{fig:ESP32-PWMHalfSidingLampDivers}
\end{centering}\end{figure}
Signal lamp diver wiring assumes common cathode or common anode signals as 
shown Figure~\ref{fig:ESP32-PWMHalfSidingLampDivers}.  

\clearpage
\section{Application Notes}

Two applications will presented, a typical siding using two boards and an
implementation of a section of Automatic Block Signals. Other trackwork
arrangements are possible as well.

\subsection{Typical Siding}

\begin{figure}[hbpt]\begin{centering}%

\caption{A Typical Siding}
\label{fig:ExampleSiding}
\end{centering}\end{figure}
\begin{figure}[hbpt]\begin{centering}%

\caption{Wiring the ESP32HalfSiding board to the control elements of CP1 (West 
end of the siding)}
\label{fig:ESP32HalfSiding-CP1Wiring}
\end{centering}\end{figure}
A typical siding is shown in Figure~\ref{fig:ExampleSiding}. And the wiring of 
the west end, CP1, is shown in Figure~\ref{fig:ESP32HalfSiding-CP1Wiring}. The 
other end is wired similarly (except that the second occupancy detector is 
wired to the main line block between the turnouts).

\subsubsection{Configuring the CP1 node (west end)}

\paragraph{Node identification configuration}
\begin{figure}[hbpt]\begin{centering}%

\caption{CP1 Node ID configuration}
\label{fig:CP1-ID-Config}
\end{centering}\end{figure}
First the node's user name and description is configured.  This makes it easier 
to find the node in the node listing.

\clearpage
\paragraph{Occupancy Detector configuration}
\begin{figure}[hbpt]\begin{centering}%

\caption{CP1 Occupancy Detectors configuration}
\label{fig:CP1-OC-Config}
\end{centering}\end{figure}
Next we configure the Occupancy Detectors.  All we do at this point is fill in 
the names of the blocks.  This helps us when we grab the event ids later.
 
\clearpage
\paragraph{Turnout and Points configuration}
\begin{figure}[hbpt]\begin{centering}%

\caption{CP1 Turnout and Points configuration}
\label{fig:CP1-Turnout-Config}
\end{centering}\end{figure}
Next we configure the Turnout and Points.  All we do at this point is fill in 
the name of the turnout.  We fill in the name for both the turnout and the 
points.  Only turnout 1 and points 1 are configured, since we are only using 
motor 1.

\clearpage
\paragraph{Signal mast configuration}
\begin{figure}[hbpt]\begin{centering}%

\caption{CP1, Mast1 configuration}
\label{fig:CP1-Mast1-Config}
\end{centering}\end{figure}
Now we skip down to the masts. Mast 1 is the two head signal at the points
entrance, named CP1ME (Control Point 1, main, eastbound). We set its Mast ID
and copy and past its Track Circuit Link Address to Circuit 1. This is a 3
(green-yellow-red) over 2 (yellow-red) signal. It has 4 rules:
\begin{table}[htbp]\begin{centering}\begin{tabular}{|l|l|l|l|}
\hline
Tab&Rule Name&Track Speed&Appearance\\
\hline
Rule 1&0-Stop&Stop&Red over Red\\
Rule 2&21-Approach&Approach&Yellow over Red\\
Rule 3&29-Clear&Clear/Proceed&Green over Red\\
Rule 4&1-Take Siding&Slow&Red over Yellow\\
\hline
\end{tabular}
\caption{CP1ME's Rules}
\label{tab:CP1MERules}
\end{centering}\end{table}
The LEDs are wired to lamp group A as follows (see Figure~\ref{fig:ESP32HalfSiding-CP1Wiring}: 
\begin{description}
\item[A0] Upper Green
\item[A1] Upper Yellow
\item[A2] Upper Red
\item[A3] Lower Yellow
\item[A4] Lower Red
\end{description}
Lamp 1 will be the upper head and Lamp 2 will be for the lower head:
\begin{description}
\item[Rule 1: 0-Stop] Red over Red -- Lamp 1 will be A2 (upper red) and Lamp 2 
will be A4 (lower red).
\item[Rule 2: 21-Approach] Yellow over Red -- Lamp 1 will be A1 (upper yellow) 
and Lamp 2 will be A4 (lower red).
\item[Rule 3: 29-Clear] Green over Red -- Lamp 1 will be A0 (upper green) and 
Lamp 2 will be A4 (lower red).
\item[Rule 4: 1-Take Siding] Red over Yellow -- Lamp 1 will be A2 (upper red) 
and Lamp 2 will be A3 (lower yellow).
\end{description}

\clearpage
\paragraph{Logic block configuration}

\subparagraph{Logic for interlocking}
\begin{figure}[hbpt]\begin{centering}%                                         

\caption{CP1 OS Veto, part 1 (description, group function, variable 1)}
\label{fig:CP1-OSVeto-Normal1}
\end{centering}\end{figure}                                                    
\begin{figure}[hbpt]\begin{centering}%                                         

\caption{CP1 OS Veto, part 2 (variable 2)}
\label{fig:CP1-OSVeto-Normal2}
\end{centering}\end{figure}                                                    
\begin{figure}[hbpt]\begin{centering}%                                         

\caption{CP1 OS Veto, part 3 (Action 1)}
\label{fig:CP1-OSVeto-Normal3}
\end{centering}\end{figure}                                                    
Next we use the CP1 OS occupancy detector as a veto to prevent moving the 
points while a train is occupying the turnout.  This is done with two logic 
elements.  One logic handles the normal request and the other handles the 
reverse request.  The second variable consumer events for these logics become 
the external events consumed for throwing the turnout and the variable 2 
events for the first logic are cross copied to the second logic.

\clearpage
\subparagraph{Logic for signal CP1ME}
This signal uses a chain of four logic blocks to implement this logic:
\begin{verbatim}
if OS is occupied then
    show Stop
else if CP1 points aligned for the siding then
    show Take Siding
else if Main line beyond the turnout is occupied then
    show Approach
else
    show Clear
\end{verbatim}

\begin{figure}[hbpt]\begin{centering}%

\caption{Configuring the logic element for CP1ME Stop aspect, part 1}
\label{fig:CP1ME-Stop-Logic-Config1}
\end{centering}\end{figure}
\begin{figure}[hbpt]\begin{centering}%

\caption{Configuring the logic element for CP1ME Stop aspect, part 2}
\label{fig:CP1ME-Stop-Logic-Config2}
\end{centering}\end{figure}
\begin{figure}[hbpt]\begin{centering}%

\caption{Configuring the logic element for CP1ME Stop aspect, part 3}
\label{fig:CP1ME-Stop-Logic-Config3}
\end{centering}\end{figure}
First we configure the logic element for the Stop aspect (the most restrictive 
aspect) of signal CP1ME, as shown in Figures 
\ref{fig:CP1ME-Stop-Logic-Config1}, \ref{fig:CP1ME-Stop-Logic-Config2}, and 
\ref{fig:CP1ME-Stop-Logic-Config3}.

\clearpage
\begin{figure}[hbpt]\begin{centering}%

\caption{Configuring the logic element for CP1ME Take Siding aspect, part 1}
\label{fig:CP1ME-TakeSiding-Logic-Config1}
\end{centering}\end{figure}
\begin{figure}[hbpt]\begin{centering}%

\caption{Configuring the logic element for CP1ME Take Siding aspect, part 2}
\label{fig:CP1ME-TakeSiding-Logic-Config2}
\end{centering}\end{figure}
Next we configure the logic element for the Take Siding aspect (the next 
restrictive aspect) of signal CP1ME, as shown in Figures 
\ref{fig:CP1ME-TakeSiding-Logic-Config1} and 
\ref{fig:CP1ME-TakeSiding-Logic-Config2}.
 
\clearpage
\begin{figure}[hbpt]\begin{centering}%

\caption{Configuring the logic element for CP1ME Approach aspect, part 1}
\label{fig:CP1ME-Approach-Logic-Config1}
\end{centering}\end{figure}
\begin{figure}[hbpt]\begin{centering}%

\caption{Configuring the logic element for CP1ME Approach aspect, part 2}
\label{fig:CP1ME-Approach-Logic-Config2}
\end{centering}\end{figure}
Next we configure the logic element for the Approach aspect (the next 
restrictive aspect) of signal CP1ME, as shown in Figures 
\ref{fig:CP1ME-Approach-Logic-Config1} and 
\ref{fig:CP1ME-Approach-Logic-Config2}. We have not set up the events for the 
variable yet, since these events will come from the other ESP32-PWMHalfSiding 
board's second occupancy detector, which is for the main line between the 
sidings.

\clearpage
\begin{figure}[hbpt]\begin{centering}%

\caption{Configuring the logic element for CP1ME Clear aspect, part 1}
\label{fig:CP1ME-Clear-Logic-Config1}
\end{centering}\end{figure}
\begin{figure}[hbpt]\begin{centering}%

\caption{Configuring the logic element for CP1ME Clear aspect, part 2}
\label{fig:CP1ME-Clear-Logic-Config2}
\end{centering}\end{figure}
Lastly we configure the logic element for the Clear aspect (the least 
restrictive aspect) of signal CP1ME, as shown in Figures 
\ref{fig:CP1ME-Clear-Logic-Config1} and 
\ref{fig:CP1ME-Clear-Logic-Config2}. This is an unconditional logic and is the 
last in this chain.

The other two signal masts are similarly configured.  There are three rules 
(stop, approach, and clear) and three logic cells for each mast.  The logic 
cell for stop is the OR of the OS section (variable 1) being occupied and the 
point state (variable 2).  The approach logic depends on the track circuit for 
the block in front of the points (a dummy mast can be set up for this, using 
an off node occupancy detector).

\clearpage
\subsection{Implementing Automatic Block Signals}

\begin{figure}[hbpt]\begin{centering}%

\caption{A Bi-directional track with ABS}
\label{fig:ABSTrack}
\end{centering}\end{figure}
\begin{figure}[hbpt]\begin{centering}%

\caption{Wiring two Bi-directional ABS blocks}
\label{fig:ABSTrack_Wiring}
\end{centering}\end{figure}
A stretch of Bi-directional track with ABS is shown in 
Figure~\ref{fig:ABSTrack} and Figure~\ref{fig:ABSTrack_Wiring} shows how two 
of the blocks would be wired to a ESP32 HalfSiding board. Additional boards 
would be used for additional pairs of blocks.

Configuring the masts and logic cells is similar to the masts and logic cells: 
the stop logic uses the occupancy detector, the approach logic uses the track 
circuit for the block beyond the current, and the clear logic is the null/true 
logic mode.

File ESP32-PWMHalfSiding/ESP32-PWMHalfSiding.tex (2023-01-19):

%%%%%%%%%%%%%%%%%%%%%%%%%%%%%%%%%%%%%%%%%%%%%%%%%%%%%%%%%%%%%%%%%%%%%%%%%%%%%
%
%  System        : 
%  Module        : 
%  Object Name   : $RCSfile$
%  Revision      : $Revision$
%  Date          : $Date$
%  Author        : $Author$
%  Created By    : Robert Heller
%  Created       : Mon Feb 10 14:21:24 2020
%  Last Modified : <230119.1546>
%
%  Description 
%
%  Notes
%
%  History
% 
%%%%%%%%%%%%%%%%%%%%%%%%%%%%%%%%%%%%%%%%%%%%%%%%%%%%%%%%%%%%%%%%%%%%%%%%%%%%%
%
%    Copyright (C) 2020  Robert Heller D/B/A Deepwoods Software
%			51 Locke Hill Road
%			Wendell, MA 01379-9728
%
%    This program is free software; you can redistribute it and/or modify
%    it under the terms of the GNU General Public License as published by
%    the Free Software Foundation; either version 2 of the License, or
%    (at your option) any later version.
%
%    This program is distributed in the hope that it will be useful,
%    but WITHOUT ANY WARRANTY; without even the implied warranty of
%    MERCHANTABILITY or FITNESS FOR A PARTICULAR PURPOSE.  See the
%    GNU General Public License for more details.
%
%    You should have received a copy of the GNU General Public License
%    along with this program; if not, write to the Free Software
%    Foundation, Inc., 675 Mass Ave, Cambridge, MA 02139, USA.
%
% 
%
%%%%%%%%%%%%%%%%%%%%%%%%%%%%%%%%%%%%%%%%%%%%%%%%%%%%%%%%%%%%%%%%%%%%%%%%%%%%%

\chapter{ESP32-PWMHalfSiding: Half Siding board base board for an ESP32 Dev Kit MCU board}

This is a circuit board that supports an ESP32 Dev Kit board or TTGO-T1 board 
to manage one half (one end) of a siding.  This board can also be used to 
manage two bi-directional single track ABS blocks or one bi-directional dual 
track ABS block.  There are other trackwork cases this board can handle as 
well.  The board contains these I/O sections:

\begin{itemize}
\item Two occupancy detectors.  These are optoisolator based, so they will 
work for both DC and DCC systems.
\item Two stall-motor with point sense.
\item Sixteen PWM Led drivers.  These are meant to light lamps in signal 
heads.
\end{itemize}

This board uses six GPIO pins and one I2C channel:

\begin{description}
\item[GPIO0] Motor Select 1: select the position of stall motor 1.
\item[GPIO12] Motor Select 2: select the position of stall motor 2.
\item[GPIO34] Point Sense 1: return the state of the points for 
stall motor 1. 
\item[GPIO35] Point Sense 2: return the state of the points for 
stall motor 2. 
\item[GPIO26] Occupancy Detector 1.
\item[GPIO27] Occupancy Detector 2.
\item[GPIO16] (Optional) Output enable for the PWM LED Controller.
\item[I2C Address 0x40] A PCA9685 16-channel, 12-bit PWM LED Controller.
\end{description}

Each of the motor drive circuits is through a TC4428, which can drive up to
1.5A, which is way more needed to drive a typical stall motor. It is enough to
drive a pair of stall motors, wired in parallel as would be the case for a
cross over. 

\section{Circuit Description}

\subsection{Turnout Control}
\begin{figure}[hbpt]\begin{centering}%

\caption{Circuit Diagram of the ESP32-PWMHalfSiding, page 1 (ESP32 MCU and 
Turnout Driver and Sense)}
\end{centering}\end{figure}

The turnout control has two parts. There is an output section that contains
two TC4428 chips. Each chip has a non-inverting and an inverting driver. The
inputs of both drivers are connected to one of the motor GPIO pins. The output
are wired to the terminal block for a one of the motors. For any given logic
state of the motor control output, one of the drivers is ``on'' and the other
is ``off'', thus one motor terminal is ground and one is raised to the 12V
supply. This means alternative states of the logic line will drive the stall
motor in alternative directions. 

The other section is a pair of flip-flop debounce circuits, one for each of
two SPDT switch contacts that report the position of the turnout points. The
output of these flip-flops goes to a pair of GPIO input pins.

\clearpage
\subsection{CAN Transceiver}
\begin{figure}[hbpt]\begin{centering}%

\caption{Circuit Diagram of the ESP32-PWMHalfSiding, page 2 (CAN Transceiver)}
\end{centering}\end{figure}

This section contains the CAN Transceiver, along with a termination jumper 
block. Power insertion and pick off and the RJ45 Jacks.

\clearpage
\subsection{Power Supply}
\begin{figure}[hbpt]\begin{centering}%

\caption{Circuit Diagram of the ESP32-PWMHalfSiding, page 3 (Power Supply)}
\end{centering}\end{figure}

This section contains a 5V power supply that takes the nominal 12V on the CAN 
power bus and regulates it down to 5V to supply the ESP32 MCU board.

\clearpage
\subsection{Occupancy Detectors}
\begin{figure}[hbpt]\begin{centering}%

\caption{Circuit Diagram of the ESP32-PWMHalfSiding, page 4 (Occupancy 
Detector 1)}
\end{centering}\end{figure}
\begin{figure}[hbpt]\begin{centering}%

\caption{Circuit Diagram of the ESP32-PWMHalfSiding, page 5 (Occupancy 
Detector 2)}
\end{centering}\end{figure}

The occupancy detectors use optoisolators in series with the track power 
supply.  There is a heavy duty bridge rectifier in parallel with the 
optoisolators to carry the bulk of the current to the track.  They will work 
with either DC or DCC track power.

\clearpage
\subsection{PWM LED Driver}
\begin{figure}[hbpt]\begin{centering}%

\caption{Circuit Diagram of the ESP32-PWMHalfSiding, page 6 (PWM LED Driver)}
\end{centering}\end{figure}

The PWM LED Driver uses a PCA9685 which is a 16 channel, 12 bit PWD LED 
driver.  A pair of octal MOSFET drivers and series load resistors are also 
included on the board.  The MOSFET drivers come in both inverting (low-side 
drive) and non-inverting (high-side drive), so it is possible to support both 
common anode and common cathode LED signals.  There are also (solder) jumpers 
on the board to support selecting the proper common wiring.

\clearpage
\section{Parts List}

%\begin{table}[htp]
\begin{centering}\begin{tabular}{|p{1.75in}|l|l|p{2.75in}|}
\hline  
Value&Qty&Refs&Mouser Part Number\\
\hline  
.1 uf&3&C1 C7 C601&21RZ310-RC\\
\hline  
15 uf 15V&1&C2&710-860080773002\\
\hline  
47 nf&1&C3&75-1C10Z5U473M050B\\
\hline  
220 uf 25V&1&C4&140-REA221M1EBK0811P\\
\hline  
22 uf 100V&1&C5&140-REA220M2ABK0811P\\
\hline  
SB240E&3&D1 D2 D601&625-SB240-E3\\
\hline  
SB160-E3/54&1&D3&625-SB160-E3\\
\hline  
BRIDGEX&2&D4 D5&750-KBL401-G\\
\hline  
MCT6H&2&IC1 IC2&782-MCT6H\\
\hline  
RJ45&2&J1 J2&710-615008144221\\
\hline  
Termination&1&JP1&649-67997-404HLF\\
\hline  
330 uh&1&L1&673-PE-52627NL\\
\hline  
Signal Terminals&2&P601 P602&651-1725724\\
\hline  
60 Ohms&2&R1 R2&71-RN60C60R0B/R\\
\hline  
10 Ohms&2&R3 R5&603-CFR-25JR-5210R\\
\hline  
10K Ohms&2&R4 R6&603-CFR25SJT-52-10K\\
\hline  
1.5K Ohms&2&RP601 RP602&652-4116R-1LF-1.5K\\
\hline  
10K Ohms&1&RR2&652-4605X-AP1-103LF\\
\hline  
Power Terminals&3&T1 T2 T601&651-1725656\\
\hline  
Track Terminals&2&T3 T6&490-TB007-508-02BE\\
\hline  
Turnout Terminals&2&T4 T5&651-1725685\\
\hline  
ESP32\_DEVKIT\_C or TTGO-T1&1&U0&2x517-929974-01-19-RK (ESP32\_DEVKIT\_C) or 2x517-929850-01-18-10 (TTGO-T1)\\
\hline  
TCAN332DR&1&U1&595-TCAN332DR\\
\hline  
LM2574N-5.0&1&U3&926-LM2574N-5.0/NOPB\\
\hline  
PCA9685&1&U601&771-PCA9685PW\\
\hline  
TBD62X83A&2&U602 U603&757-TBD62083APG or 757-TBD62783APG\\
\hline  
TC4428&2&U7 U8&579-TC4428VPA\\
\hline  
74HCT00&1&U9&595-SN74AHC00N\\
\hline  
\end{tabular}
%\caption{Parts list for ESP32-PWMHalfSiding board.}
\end{centering}
%\end{table}

%\clearpage
\section{Circuit Board Layout}

\begin{figure}[hbpt]\begin{centering}%

\caption{3D rendering of the ESP32-PWMHalfSiding board}
\end{centering}\end{figure}
\begin{figure}[hbpt]\begin{centering}%

\caption{Fabrication image of the ESP32-PWMHalfSiding board}
\end{centering}\end{figure}

\subsection{Notes on Building the board}

\begin{figure}[hbpt]\begin{centering}%

\caption{OE Jumper modifications.}
\label{fig:ESP32-PWMHalfSidingOEEnableMods}
\end{centering}\end{figure}
\begin{figure}[hbpt]\begin{centering}%

\caption{Building for Common Anode Signals}
\label{fig:ESP32-PWMHalfSidingCommonAnodeLamps}
\end{centering}\end{figure} 
\begin{figure}[hbpt]\begin{centering}%

\caption{Building for Common Cathode Signals}
\label{fig:ESP32-PWMHalfSidingCommonCathodeLamps}
\end{centering}\end{figure} 
Board assembly is straight forward. You need to be careful orienting the ICs
and the electrolytic capacitor. You should start with the parts lowest to the
board (the SMD chips). Hand soldering SMD is not terribly hard. There is are
excellent videos on YouTube, particularly this one
\url{https://www.youtube.com/watch?v=QzoPxvIM2qE} from Collin's lab which can
be very helpful. Once you have soldered the SMD chips, proceed with
successively taller components. You have some choices to make about some
components. For the MCU board you can use just two 19 pin headers if you will
be using a ESP32\_DEVKIT\_C MCU board or two 18 pin headers if you will be
using a TTGO-T1 or two 19 pin headers and one 18 pin header, if you want to
use either MCU board\footnote{The kit includes two 19 pin headers and one 18
pin header.}. Then for the LED output drivers you can chose 757-TBD62083APGs
for common cathode or 757-TBD62783APGs for common anode signals. Don't forget
to insert and solder jumpers for the commons.\footnote{The kit comes with
pairs of both driver chips.}  See Figures 
\ref{fig:ESP32-PWMHalfSidingCommonAnodeLamps} and 
\ref{fig:ESP32-PWMHalfSidingCommonCathodeLamps}. Also, the software at present does not use the 
output enable, so the trace at OE GPIO needs to be cut and the contacts at OE 
Bypass need to be bridged, as shown in 
Figure~\ref{fig:ESP32-PWMHalfSidingOEEnableMods}.

\clearpage
\section{Downloadables and Software Support}

As shipped, the TTGO-T1 has already had the ESP32-PWMHalfSiding firmware
installed, but if you want to rebuild the code (possibly with customizations)
the code is on GitHub in my ESP32-LCC repo:
\url{https://github.com/RobertPHeller/ESP32-LCC}, in the
ESP32-PWMHalfSidingOpenMRNIDF sub-folder. You will need the Espressif's IoT
Development Framework, version 4.2 or later, available from
\url{https://github.com/espressif/esp-idf}. The ESP32-PWMHalfSidingOpenMRNIDF
also uses Mike Dunston's OpenMRNID module -- be sure to do ``git submodule
update --init'' after cloning https://github.com/RobertPHeller/ESP32-LCC.

\subsection{Building and installing the software}

Once you have installed Espressif's IoT Development Framework and cloned the 
ESP32-LCC repo, you can build the software by cd'ing to the 
ESP32-PWMHalfSidingOpenMRNIDF and in bash running these commands:

\begin{verbatim}
. path-to-Espressifs-IDF/export.sh
idf.py build
\end{verbatim}

You can then use the idf.py's flash command to flash the TTGO-T1.

\subsubsection{WiFi notes}

The default configuration is with WiFi disabled. Using both the CAN interface
\textbf{and} WiFi at the same time on the ESP32 is not recomended. The
processor cannot handle both well. 

\subsection{Program Description}

The program consists of a main sketch file, and several support files and
``components'' (libraries).

\subsection{Program Startup notes}

While most of the common node configuration is accessable using the available
CDI configuruation tools (JMRI's PanelPro program or MRR SYS OpenLCB program), 
some of the nodes configuration is in separate non-volitle (flash) memory.  
This includes the node's ID number and some boot options.  As installed the 
node ID is initialized to 05:01:01:01:22:00.  \textbf{You don't really want to 
leave this as the node id!}  There are two ways to set the node id.  One way 
is to use a CDI configuruation tool -- the node ID is exposed as a 
configuration option.  Changes the node id forces a ``factory reset'' on the 
next boot (and when you update the configuration with a CDI configuruation 
tool, the node will reboot).  The other way is during the boot up process.  
When the node boots, it waits on the USB serial connection for 10 seconds for 
any ``keyboard'' response and if it gets a ``keyboard'' response, it enters a 
simple command line loop accepting simple commands (mostly single letters). 
To use this feature you need to connect a a USB cable between the TTGO-T1 and 
a computer (eg a PC or Mac) and then connect to the USB Com port with a 
terminal program (the Arduino IDE Serial Monitor should work).  The commands 
that the boot startup command line loop supports are:

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

\section{General Wiring Notes}

\begin{figure}[hbpt]\begin{centering}%

\caption{Placement of terminal blocks, connectors, and jumper blocks.}
\end{centering}\end{figure}
There are various terminal blocks, connectors, and jumper blocks on this
board. At the top end of the board are a pair of two position terminal blocks, 
one for injecting power into the LCC bus and one for extracting power from the 
LCC bus.  Between these terminal blocks is the termination jumper block for 
the LCC bus.  Below the LCC  power terminal blocks is a pair of RJ45 
connectors. These are for connecting the board to the LCC bus.  These 
connectors are wired in parallel.  Down along the left side are the two stall 
motor terminal blocks (small 5 position terminal blocks) and the occupancy 
detector terminal blocks (large 2 position terminal blocks).  On the right 
side are two 9 position terminal blocks for the signal lamp LEDs.  Finally, at 
the bottom right is a two position terminal block to (optionally) provide 
power for the signal lamp LEDs.

\subsection{LCC Power}

Power can be optionally injected into the LCC bus or extracted from the LCC 
bus. Power can be injected to into the LCC bus to power this and other boards. 
Power can also be extracted to power local devices.

\subsection{LCC Bus connections and termination}

\begin{figure}[hbpt]\begin{centering}%

\caption{Termination Jumper Options}
\label{fig:ESP32-PWMHalfSidingTermination}
\end{centering}\end{figure}
The two RJ45 connections connect to the LCC bus.  If this board is at the end 
of bus, you will need to terminate the bus.  There are two possible 
termination options as shown in 
Figure~\ref{fig:ESP32-PWMHalfSidingTermination}.

\subsection{Stall Motor connections}

\begin{figure}[hbpt]\begin{centering}%

\caption{Stall Motor terminal block connections}
\label{fig:ESP32-PWMHalfSidingTurnoutMotorsFig}
\end{centering}\end{figure}
\begin{figure}[hbpt]\begin{centering}%

\caption{Wiring a Tortoise to the ESP32-PWMHalfSiding Turnout Motors terminals}
\label{fig:ESP32-PWMHalfSidingTotoiseWiring}
\end{centering}\end{figure}
The five position Stall Motor terminal blocks, shown in 
Figure~\ref{fig:ESP32-PWMHalfSidingTurnoutMotorsFig}, connect to the turnout 
stall motors, the Motor A and Motor B connections go to the motor (pins 1 and 
8 of a tortoise), the other three connections go to a single pole double 
through switch contacts to sense the position of the stall motor / points. 
There are contacts available on tortoise stall motor that can be used for this 
purpose, as shown in Figure~\ref{fig:ESP32-PWMHalfSidingTotoiseWiring}.

\clearpage
\subsection{Occupancy Detector connections}

\begin{figure}[hbpt]\begin{centering}%

\caption{Occupancy Detector Wiring}
\label{fig:ESP32-PWMHalfSidingOccupancyDetectors}
\end{centering}\end{figure}
The larger two position Occupancy Detector terminal blocks are connected to 
the track power feeds as shown in 
Figure~\ref{fig:ESP32-PWMHalfSidingOccupancyDetectors}.

\clearpage
\subsection{Signal Lamp (LED) connections}

\begin{figure}[hbpt]\begin{centering}%

\caption{Typical Signal Lamp Diver Wiring}
\label{fig:ESP32-PWMHalfSidingLampDivers}
\end{centering}\end{figure}
Signal lamp diver wiring assumes common cathode or common anode signals as 
shown Figure~\ref{fig:ESP32-PWMHalfSidingLampDivers}.  

\clearpage
\section{Application Notes}

Three applications will presented, a typical siding using two boards, an 
implementation of a section of Automatic Block Signals, and Crossing with 
Interchange.  Other trackwork arrangements are possible as well.

\subsection{Typical Siding}

\begin{figure}[hbpt]\begin{centering}%

\caption{A Typical Siding}
\label{fig:ExampleSiding}
\end{centering}\end{figure}
\begin{figure}[hbpt]\begin{centering}%

\caption{Wiring the ESP32HalfSiding board to the control elements of CP1 (West 
end of the siding)}
\label{fig:ESP32HalfSiding-CP1Wiring}
\end{centering}\end{figure}
A typical siding is shown in Figure~\ref{fig:ExampleSiding}. And the wiring of 
the west end, CP1, is shown in Figure~\ref{fig:ESP32HalfSiding-CP1Wiring}. The 
other end is wired similarly (except that the second occupancy detector is 
wired to the main line block between the turnouts).

\subsubsection{Configuring the CP1 node (west end)}

\paragraph{Node identification configuration}
\begin{figure}[hbpt]\begin{centering}%

\caption{CP1 Node ID configuration}
\label{fig:CP1-ID-Config}
\end{centering}\end{figure}
First the node's user name and description is configured.  This makes it easier 
to find the node in the node listing.

\clearpage
\paragraph{Occupancy Detector configuration}
\begin{figure}[hbpt]\begin{centering}%

\caption{CP1 Occupancy Detectors configuration}
\label{fig:CP1-OC-Config}
\end{centering}\end{figure}
Next we configure the Occupancy Detectors.  All we do at this point is fill in 
the names of the blocks.  This helps us when we grab the event ids later.
 
\clearpage
\paragraph{Turnout and Points configuration}
\begin{figure}[hbpt]\begin{centering}%

\caption{CP1 Turnout and Points configuration}
\label{fig:CP1-Turnout-Config}
\end{centering}\end{figure}
Next we configure the Turnout and Points.  All we do at this point is fill in 
the name of the turnout.  We fill in the name for both the turnout and the 
points.  Only turnout 1 and points 1 are configured, since we are only using 
motor 1.

\clearpage
\paragraph{Signal mast configuration}
\begin{figure}[hbpt]\begin{centering}%

\caption{CP1, Mast1 configuration}
\label{fig:CP1-Mast1-Config}
\end{centering}\end{figure}
Now we skip down to the masts. Mast 1 is the two head signal at the points
entrance, named CP1ME (Control Point 1, main, eastbound). We set its Mast ID
and copy and past its Track Circuit Link Address to Circuit 1. This is a 3
(green-yellow-red) over 2 (yellow-red) signal. It has 4 rules:
\begin{table}[htp]\begin{centering}\begin{tabular}{|l|l|l|l|}
\hline
Tab&Rule Name&Track Speed&Appearance\\
\hline
Rule 1&0-Stop&Stop&Red over Red\\
Rule 2&21-Approach&Approach&Yellow over Red\\
Rule 3&29-Clear&Clear/Proceed&Green over Red\\
Rule 4&1-Take Siding&Slow&Red over Yellow\\
\hline
\end{tabular}
\caption{CP1ME's Rules}
\label{tab:CP1MERules}
\end{centering}\end{table}
The LEDs are wired to lamp group A as follows (see Figure~\ref{fig:ESP32HalfSiding-CP1Wiring}: 
\begin{description}
\item[A0] Upper Green
\item[A1] Upper Yellow
\item[A2] Upper Red
\item[A3] Lower Yellow
\item[A4] Lower Red
\end{description}
Lamp 1 will be the upper head and Lamp 2 will be for the lower head:
\begin{description}
\item[Rule 1: 0-Stop] Red over Red -- Lamp 1 will be A2 (upper red) and Lamp 2 
will be A4 (lower red).
\item[Rule 2: 21-Approach] Yellow over Red -- Lamp 1 will be A1 (upper yellow) 
and Lamp 2 will be A4 (lower red).
\item[Rule 3: 29-Clear] Green over Red -- Lamp 1 will be A0 (upper green) and 
Lamp 2 will be A4 (lower red).
\item[Rule 4: 1-Take Siding] Red over Yellow -- Lamp 1 will be A2 (upper red) 
and Lamp 2 will be A3 (lower yellow).
\end{description}

\clearpage
\paragraph{Logic block configuration}

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

\clearpage
\subparagraph{Logic for signal CP1ME}
This signal uses a chain of four logic blocks to implement this logic:
\begin{verbatim}
if OS is occupied then
    show Stop
else if CP1 points aligned for the siding then
    show Take Siding
else if Main line beyond the turnout is occupied then
    show Approach
else
    show Clear
\end{verbatim}

\begin{figure}[hbpt]\begin{centering}%

\caption{Configuring the logic element for CP1ME Stop aspect, part 1}
\label{fig:CP1ME-Stop-Logic-Config1}
\end{centering}\end{figure}
\begin{figure}[hbpt]\begin{centering}%

\caption{Configuring the logic element for CP1ME Stop aspect, part 2}
\label{fig:CP1ME-Stop-Logic-Config2}
\end{centering}\end{figure}
\begin{figure}[hbpt]\begin{centering}%

\caption{Configuring the logic element for CP1ME Stop aspect, part 3}
\label{fig:CP1ME-Stop-Logic-Config3}
\end{centering}\end{figure}
First we configure the logic element for the Stop aspect (the most restrictive 
aspect) of signal CP1ME, as shown in Figures 
\ref{fig:CP1ME-Stop-Logic-Config1}, \ref{fig:CP1ME-Stop-Logic-Config2}, and 
\ref{fig:CP1ME-Stop-Logic-Config3}.

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

\clearpage
\begin{figure}[hbpt]\begin{centering}%

\caption{Configuring the logic element for CP1ME Clear aspect, part 1}
\label{fig:CP1ME-Clear-Logic-Config1}
\end{centering}\end{figure}
\begin{figure}[hbpt]\begin{centering}%

\caption{Configuring the logic element for CP1ME Clear aspect, part 2}
\label{fig:CP1ME-Clear-Logic-Config2}
\end{centering}\end{figure}
Lastly we configure the logic element for the Clear aspect (the least 
restrictive aspect) of signal CP1ME, as shown in Figures 
\ref{fig:CP1ME-Clear-Logic-Config1} and 
\ref{fig:CP1ME-Clear-Logic-Config2}. This is an unconditional logic and is the 
last in this chain.

\clearpage
\subsection{Implementing Automatic Block Signals}

\begin{figure}[hbpt]\begin{centering}%

\caption{A Bi-directional track with ABS}
\label{fig:ABSTrack}
\end{centering}\end{figure}
\begin{figure}[hbpt]\begin{centering}%

\caption{Wiring two Bi-directional ABS blocks}
\label{fig:ABSTrack_Wiring}
\end{centering}\end{figure}
A stretch of Bi-directional track with ABS is shown in 
Figure~\ref{fig:ABSTrack} and Figure~\ref{fig:ABSTrack_Wiring} shows how two 
of the blocks would be wired to a ESP32 HalfSiding board. Additional boards 
would be used for additional pairs of blocks.

\clearpage
\subsection{Crossing with Interchange}

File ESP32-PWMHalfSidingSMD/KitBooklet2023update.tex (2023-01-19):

%%%%%%%%%%%%%%%%%%%%%%%%%%%%%%%%%%%%%%%%%%%%%%%%%%%%%%%%%%%%%%%%%%%%%%%%%%%%%
%
%  System        : 
%  Module        : 
%  Object Name   : $RCSfile$
%  Revision      : $Revision$
%  Date          : $Date$
%  Author        : $Author$
%  Created By    : Robert Heller
%  Created       : Sun Jan 1 13:48:18 2023
%  Last Modified : <230119.1551>
%
%  Description 
%
%  Notes
%
%  History
% 
%%%%%%%%%%%%%%%%%%%%%%%%%%%%%%%%%%%%%%%%%%%%%%%%%%%%%%%%%%%%%%%%%%%%%%%%%%%%%
%
%    Copyright (C) 2023  Robert Heller D/B/A Deepwoods Software
%			51 Locke Hill Road
%			Wendell, MA 01379-9728
%
%    This program is free software; you can redistribute it and/or modify
%    it under the terms of the GNU General Public License as published by
%    the Free Software Foundation; either version 2 of the License, or
%    (at your option) any later version.
%
%    This program is distributed in the hope that it will be useful,
%    but WITHOUT ANY WARRANTY; without even the implied warranty of
%    MERCHANTABILITY or FITNESS FOR A PARTICULAR PURPOSE.  See the
%    GNU General Public License for more details.
%
%    You should have received a copy of the GNU General Public License
%    along with this program; if not, write to the Free Software
%    Foundation, Inc., 675 Mass Ave, Cambridge, MA 02139, USA.
%
% 
%
%%%%%%%%%%%%%%%%%%%%%%%%%%%%%%%%%%%%%%%%%%%%%%%%%%%%%%%%%%%%%%%%%%%%%%%%%%%%%

\documentclass[12pt,twoside]{article}
\usepackage{graphicx}
\usepackage{mathptm}
\usepackage{times}
\usepackage{makeidx}
\usepackage{ifpdf}
\usepackage{footmisc}
\ifpdf
\usepackage[pdftex,
            pagebackref=true,
            colorlinks=true,
            linkcolor=blue,
            unicode
           ]{hyperref}
\else
\usepackage[ps2pdf,
            pagebackref=true,
            colorlinks=true,
            linkcolor=blue,
            unicode
           ]{hyperref}
\usepackage{pspicture}
\fi
\usepackage{url}
\pagestyle{headings}
\makeindex
\emergencystretch=50pt
\setcounter{tocdepth}{3}
\setcounter{secnumdepth}{3}
\title{ESP32 PWM Half Siding Kit 2023 Updates}
\author{Robert Heller \\ The Country Robot \\ Wendell, MA, USA}
\date{\today}
\begin{document}
\maketitle

This is the replacement section for ``Downloadables and Software Support''.

\setcounter{section}{3}

\section{Downloadables and Software Support}

As shipped, the TTGO-T1 has already had the ESP32-PWMHalfSiding firmware
installed, but if you want to rebuild the code (possibly with customizations)
the code is on GitHub in my ESP32-LCC repo:
\url{https://github.com/RobertPHeller/ESP32-LCC}, in the
ESP32-PWMHalfSidingOpenMRNIDF sub-folder. You will need the Espressif's IoT
Development Framework, version 4.2 or later, available from
\url{https://github.com/espressif/esp-idf}. The ESP32-PWMHalfSidingOpenMRNIDF
also uses Mike Dunston's OpenMRNID module -- be sure to do ``git submodule
update --init'' after cloning https://github.com/RobertPHeller/ESP32-LCC.

\subsection{Building and installing the software}

Once you have installed Espressif's IoT Development Framework and cloned the 
ESP32-LCC repo, you can build the software by cd'ing to the 
ESP32-PWMHalfSidingOpenMRNIDF and in bash running these commands:

\begin{verbatim}
. path-to-Espressifs-IDF/export.sh
idf.py build
\end{verbatim}

You can then use the idf.py's flash command to flash the TTGO-T1.

\subsubsection{WiFi notes}

The default configuration is with WiFi disabled. Using both the CAN interface
\textbf{and} WiFi at the same time on the ESP32 is not recomended. The
processor cannot handle both well.

\subsection{Program Description}

The program consists of a main sketch file, and several support files and
``components'' (libraries).

\subsection{Program Startup notes}

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

\end{document}

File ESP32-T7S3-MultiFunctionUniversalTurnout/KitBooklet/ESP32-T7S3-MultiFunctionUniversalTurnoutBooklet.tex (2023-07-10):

%%%%%%%%%%%%%%%%%%%%%%%%%%%%%%%%%%%%%%%%%%%%%%%%%%%%%%%%%%%%%%%%%%%%%%%%%%%%%
%
%  System        : 
%  Module        : 
%  Object Name   : $RCSfile$
%  Revision      : $Revision$
%  Date          : $Date$
%  Author        : $Author$
%  Created By    : Robert Heller
%  Created       : Sat Mar 4 08:39:57 2023
%  Last Modified : <230710.1224>
%
%  Description 
%
%  Notes
%
%  History
% 
%%%%%%%%%%%%%%%%%%%%%%%%%%%%%%%%%%%%%%%%%%%%%%%%%%%%%%%%%%%%%%%%%%%%%%%%%%%%%
%
%    Copyright (C) 2023  Robert Heller D/B/A Deepwoods Software
%			51 Locke Hill Road
%			Wendell, MA 01379-9728
%
%    This program is free software; you can redistribute it and/or modify
%    it under the terms of the GNU General Public License as published by
%    the Free Software Foundation; either version 2 of the License, or
%    (at your option) any later version.
%
%    This program is distributed in the hope that it will be useful,
%    but WITHOUT ANY WARRANTY; without even the implied warranty of
%    MERCHANTABILITY or FITNESS FOR A PARTICULAR PURPOSE.  See the
%    GNU General Public License for more details.
%
%    You should have received a copy of the GNU General Public License
%    along with this program; if not, write to the Free Software
%    Foundation, Inc., 675 Mass Ave, Cambridge, MA 02139, USA.
%
% 
%
%%%%%%%%%%%%%%%%%%%%%%%%%%%%%%%%%%%%%%%%%%%%%%%%%%%%%%%%%%%%%%%%%%%%%%%%%%%%%

\documentclass[12pt,twoside,letterpaper]{article}
\usepackage{graphicx}
\usepackage{mathptm}
\usepackage{times}
\usepackage{makeidx}
\usepackage{ifpdf}
\usepackage{footmisc}
\ifpdf
\usepackage[pdftex,
            pagebackref=true,
            colorlinks=true,
            linkcolor=blue,
            unicode
           ]{hyperref}
\else
\usepackage[ps2pdf,
            pagebackref=true,
            colorlinks=true,
            linkcolor=blue,
            unicode
           ]{hyperref}
\usepackage{pspicture}
\fi
\usepackage{url}
\pagestyle{headings}
\makeindex
\emergencystretch=50pt
\setcounter{tocdepth}{3}
\setcounter{secnumdepth}{3}
\title{ESP32 T7S3 MultiFunctionUniversalTurnout Kit Instructions}
\author{Robert Heller \\ The Country Robot \\ Wendell, MA, USA}
\date{\today}
\begin{document}
\maketitle

This is a circuit board that supports a Lily Go T7 S3 (mini32) board to manage
multiple model railroad functions as a LCC\footnote{Layout Command Control --
see NMRA's 9.7.x standards, available on the NMRA website
\url{https://www.nmra.org/lcc}.} node. This board provides the following 
functions:

\begin{itemize}
\item Four turnout motors with point sense.  This board uses one of four 
turnout driver daughter boards:
\begin{enumerate}
\item Stall-motor drivers, suitable for Circuitron Tortoise and similar slow 
motion, stall motor switch machines.
\item Twin-coil drivers, suitable for Atlas or Peco snap action switch 
machines.
\item Single-coil drivers, suitable for Kato snap action switch machines.
\item Servo drivers, suitable for using RC control servos to operate turnouts.
\end{enumerate}
\item Four CT coil occupancy detectors.
\item Four driver circuits, suitable for indicator LEDs, decoupling 
electromagnets, solenoids, relays, etc.
\item Four Schmitt-trigger button inputs.
\item Sixteen signal lamp drivers.
\end{itemize}

\clearpage
\input{Assembly.tex}
\input{Downloadables.tex}
\input{GeneralWiring.tex}
\section{Application Notes}

In this section I will present four applications:

\begin{enumerate}
\item One end of a siding with local (facia panel) and remote (eg dispatcher
or CTC) control in Section~\ref{sect-appl:siding}.
\item A Yard Throat with track selection in 
Section~\ref{sect-appl:yardthroat}. 
\item A crossing with an interchange track in 
Section~\ref{sect-appl:crossinginterchange}.
\item Automatic Block Signals in Section~\ref{sect-appl:ABS}.
\end{enumerate}

\input{ApplNote_Siding.tex}
\input{ApplNote_YardThroat.tex}
\input{ApplNote_Crossing.tex}
\input{ApplNote_ABS.tex}

\end{document}

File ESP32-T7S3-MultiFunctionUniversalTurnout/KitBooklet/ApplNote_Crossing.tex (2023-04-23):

%%%%%%%%%%%%%%%%%%%%%%%%%%%%%%%%%%%%%%%%%%%%%%%%%%%%%%%%%%%%%%%%%%%%%%%%%%%%%
%
%  System        : 
%  Module        : 
%  Object Name   : $RCSfile$
%  Revision      : $Revision$
%  Date          : $Date$
%  Author        : $Author$
%  Created By    : Robert Heller
%  Created       : Sat Apr 15 10:38:17 2023
%  Last Modified : <230423.1218>
%
%  Description 
%
%  Notes
%
%  History
% 
%%%%%%%%%%%%%%%%%%%%%%%%%%%%%%%%%%%%%%%%%%%%%%%%%%%%%%%%%%%%%%%%%%%%%%%%%%%%%
%
%    Copyright (C) 2023  Robert Heller D/B/A Deepwoods Software
%			51 Locke Hill Road
%			Wendell, MA 01379-9728
%
%    This program is free software; you can redistribute it and/or modify
%    it under the terms of the GNU General Public License as published by
%    the Free Software Foundation; either version 2 of the License, or
%    (at your option) any later version.
%
%    This program is distributed in the hope that it will be useful,
%    but WITHOUT ANY WARRANTY; without even the implied warranty of
%    MERCHANTABILITY or FITNESS FOR A PARTICULAR PURPOSE.  See the
%    GNU General Public License for more details.
%
%    You should have received a copy of the GNU General Public License
%    along with this program; if not, write to the Free Software
%    Foundation, Inc., 675 Mass Ave, Cambridge, MA 02139, USA.
%
% 
%
%%%%%%%%%%%%%%%%%%%%%%%%%%%%%%%%%%%%%%%%%%%%%%%%%%%%%%%%%%%%%%%%%%%%%%%%%%%%%

\subsection{Crossing with interchange}
\label{sect-appl:crossinginterchange}

\begin{figure}[hbpt]\begin{centering}%
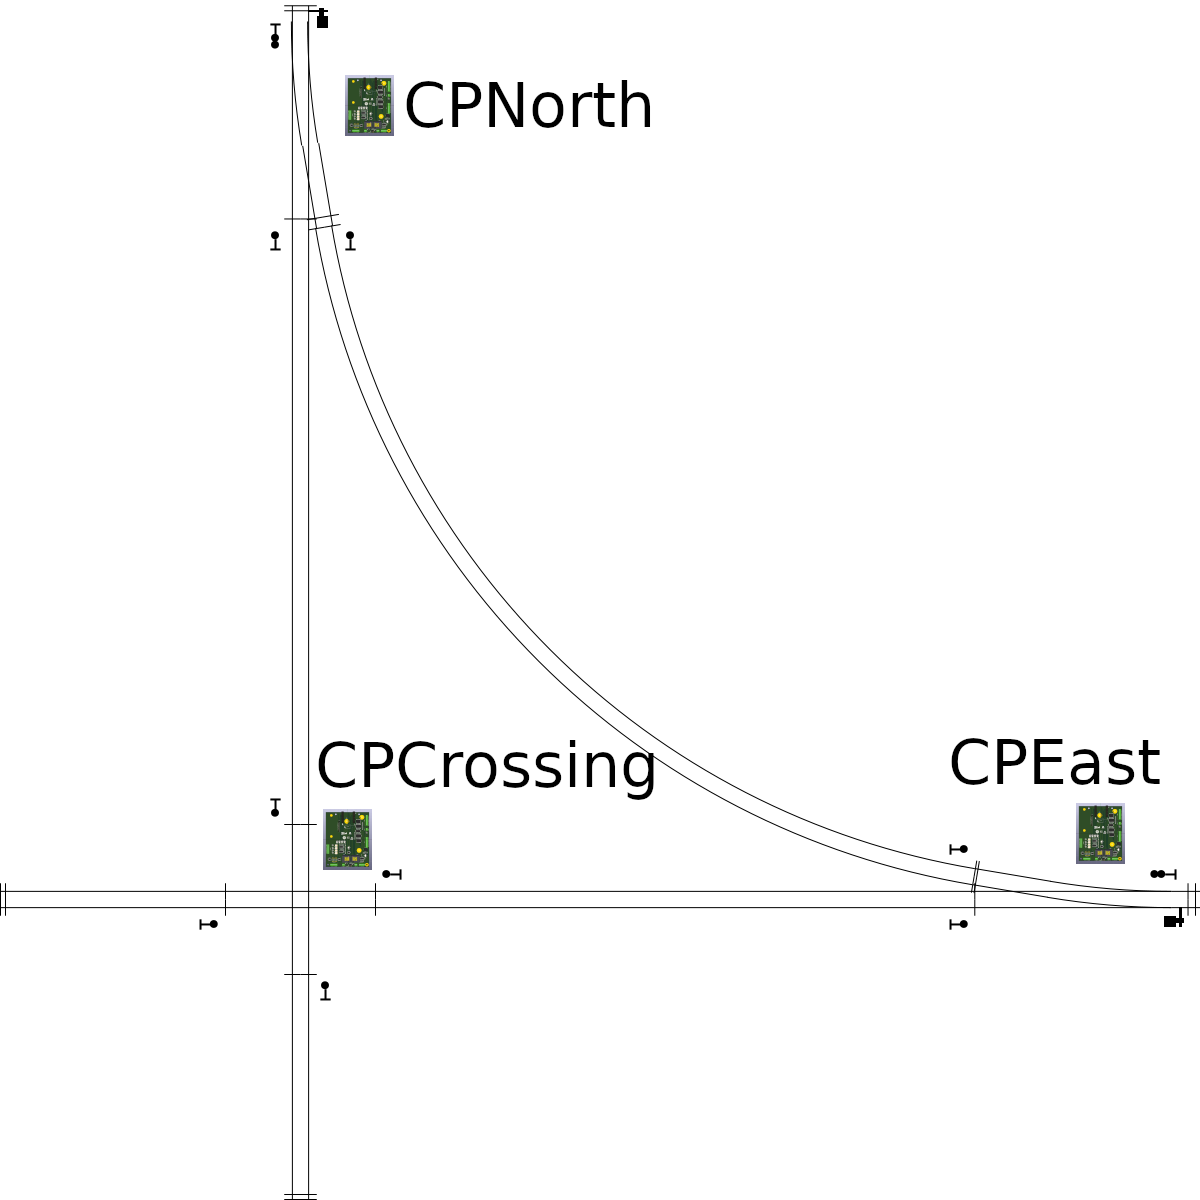
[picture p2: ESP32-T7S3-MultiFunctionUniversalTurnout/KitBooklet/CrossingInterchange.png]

\caption{Crossing with Interchange.}
\label{fig:CrossingInterchange}
\end{centering}\end{figure}

This is a level crossing with an interchange track.  We will control and 
manage this crossing and interchange with three ESP32 T7S3 MultiFunction 
Universal Turnout nodes, as shown in Figure~\ref{fig:CrossingInterchange}. The 
three nodes will implement these functions:

\begin{description}
\item [CPNorth] This node will manage the north turnout and the signals around 
it.  It will also provide occupancy detection for the turnout OS section and 
the north-south track segment. It will be wired as following:
\begin{description}
\item [OC 1] The turnout OS section.
\item [OC 2] The north-south track segment.
\item [Turnout 1] The north turnout motor.
\item [Points 1] The north turnout points.
\item [A0(UR), A1(UY), A2(UG), A3(LR), A4(LY), A5(LG)] The signal at the north 
(points) end of the turnout.
\item [B0(R), B1(Y), B2(G)] The interchange segment (divergent frog) 
end of the turnout.
\item [B3(R), B4(Y), B5(G)] The north-south track segment 
(non-divergent frog) end of the turnout.
\end{description} 
\item [CPEast] This node will manage the east turnout and the signals 
around it.  It will also provide occupancy detection for the turnout OS 
section, the east-west track segment, and the interchange track segment.  It 
will be wired as following: 
\begin{description}
\item [OC 1] The turnout OS section.
\item [OC 2] The east-west track segment.
\item [OC 3] The interchange track segment
\item [Turnout 1] The west turnout motor.
\item [Points 1] The west turnout points.
\item [A0(UR), A1(UY), A2(UG), A3(LR), A4(LY), A5(LG)] The signal at the west 
(points) end of the turnout.
\item [B0(R), B1(Y), B2(G)] The interchange segment (divergent frog) 
end of the turnout.
\item [B3(R), B4(Y), B5(G)] The east-west track segment 
(non-divergent frog) end of the turnout.
\end{description} 
\item [CPCrossing] This node will manage the crossing diamond, including the 
signals around it along with occupancy detection of the diamond itself.  It 
will be wired as following: 
\begin{description}
\item [OC 1] The east-west part of the crossing.
\item [OC 2] The north-south part of the crossing.
\item [A0(R), A1(Y), A2(G)] The signal at the west end of the crossing.
\item [A3(R), A4(Y), A5(G)] The signal at the east end of the crossing.
\item [B0(R), B1(Y), B2(G)] The signal at the north end of the crossing.
\item [B3(R), B4(Y), B5(G)] The signal at the south end of the crossing.
\end{description}
\end{description}

The CPNorth and CPEast will actually be configured following the much the same 
methods as an end of a siding, as describe in 
Section~\ref{sect-appl:siding}\footnote{The local control buttons and LEDs are
not shown here - they could be added or left out as desired.} Since we are 
using 3 over 3 signals at the points ends of the turnouts, it is possible to 
add additional aspects. 

\begin{figure}[hbpt]\begin{centering}%

\caption{CPNorth  Event Id graph.}
\label{fig:CrossingCPNorthEventFlow}
\end{centering}\end{figure}
\begin{figure}[hbpt]\begin{centering}%

\caption{CPEast  Event Id graph.}
\label{fig:CrossingCPEastEventFlow}
\end{centering}\end{figure}
\begin{figure}[hbpt]\begin{centering}%

\caption{CPCrossing Event Id graph.}
\label{fig:CrossingCPCrossing}
\end{centering}\end{figure}
\clearpage
\begin{table}[hbpt]\begin{centering}%
\begin{tabular}{|l|l|p{2in}|}
\hline
Color&Object&What it is\\
\hline
Orange&Node&Occupancy Detectors\\
\hline
Green&Node&Siding normal button and LED\\
\hline
Red&Node&Siding reversed button and LED\\
\hline
Cyan&Node&Logic Elements\\
\hline
Blue&Node&Turnout Outputs\\
\hline
LightSeaGreen&Node&Point Sense Inputs\\
\hline
RoyalBlue&Node&Masts\\
\hline 
Green&Edge&Button and LED normal Events\\
\hline
Red&Edge&Button and LED reverse Events\\
\hline
Brown&Edge&Button Release Events\\
\hline
Green&Edge&Turnout Operating Events\\
\hline
Black&Edge&Logic Fall Throughs (Elses)\\
\hline
Orange&Edge&Odd Yard Tracks (1 and 3)\\
\hline
Violet&Edge&Even Yard Tracks (2 and 4)\\
\hline
Cyan&Edge&Mast Rule Selection\\
\hline
LightSeaGreen&Edge&Point Sense events\\
\hline
\end{tabular}
\caption{Graph color key}
\label{tab:CrossingGraphKey}
\end{centering}\end{table}

\clearpage

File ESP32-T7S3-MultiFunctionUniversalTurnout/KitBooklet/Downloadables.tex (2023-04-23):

%%%%%%%%%%%%%%%%%%%%%%%%%%%%%%%%%%%%%%%%%%%%%%%%%%%%%%%%%%%%%%%%%%%%%%%%%%%%%
%
%  System        : 
%  Module        : 
%  Object Name   : $RCSfile$
%  Revision      : $Revision$
%  Date          : $Date$
%  Author        : $Author$
%  Created By    : Robert Heller
%  Created       : Sat Apr 15 10:31:27 2023
%  Last Modified : <230423.1209>
%
%  Description 
%
%  Notes
%
%  History
% 
%%%%%%%%%%%%%%%%%%%%%%%%%%%%%%%%%%%%%%%%%%%%%%%%%%%%%%%%%%%%%%%%%%%%%%%%%%%%%
%
%    Copyright (C) 2023  Robert Heller D/B/A Deepwoods Software
%			51 Locke Hill Road
%			Wendell, MA 01379-9728
%
%    This program is free software; you can redistribute it and/or modify
%    it under the terms of the GNU General Public License as published by
%    the Free Software Foundation; either version 2 of the License, or
%    (at your option) any later version.
%
%    This program is distributed in the hope that it will be useful,
%    but WITHOUT ANY WARRANTY; without even the implied warranty of
%    MERCHANTABILITY or FITNESS FOR A PARTICULAR PURPOSE.  See the
%    GNU General Public License for more details.
%
%    You should have received a copy of the GNU General Public License
%    along with this program; if not, write to the Free Software
%    Foundation, Inc., 675 Mass Ave, Cambridge, MA 02139, USA.
%
% 
%
%%%%%%%%%%%%%%%%%%%%%%%%%%%%%%%%%%%%%%%%%%%%%%%%%%%%%%%%%%%%%%%%%%%%%%%%%%%%%

\section{Downloadables and Software Support}

As shipped, the TTGO-T7S3 has already had the ESP32-S3-MultiFunctionOpenMRNIDF
firmware installed, but if you want to rebuild the code (possibly with
customizations) the code is on GitHub in my ESP32-LCC repository:
\url{https://github.com/RobertPHeller/ESP32-LCC}, in the
ESP32-S3-MultiFunctionOpenMRNIDFOpenMRNIDF sub-folder. You will need the
Espressif's IoT Development Framework, version 5.0.1 or later, available from
\url{https://github.com/espressif/esp-idf}. The
ESP32-S3-MultiFunctionOpenMRNIDFOpenMRNIDF also uses Mike Dunston's OpenMRNIDF
module. Also available in the 
ESP32-T7S3-MultiFunctionUniversalTurnout/KitBooklet sub-folder are pdfs of the 
circuit diagrams.

\subsection{Building and installing the software}

Once you have installed Espressif's IoT Development Framework and cloned the
ESP32-LCC repository, you can build the software by cd'ing to the
ESP32-S3-MultiFunctionOpenMRNIDF and in bash running these commands in a bash
shell:

\begin{verbatim}
. path-to-Espressifs-IDF/export.sh
idf.py set-target esp32s3
idf.py menuconfig
idf.py build
\end{verbatim}

Things to check in the menuconfig (under ``Advanced Configuration''):

\begin{itemize}
\item{Using TTGO-T7S3} Turn this option on.
\item{Using the servo turnout daughter board} If you are using the TS (turnout 
servo) daughter board, turn this on.  If using any of the other turnout 
daughter boards turn this off.
\end{itemize}

You can then use the idf.py's flash command to flash the TTGO-T7S3.

\subsection{Program Description}

The program consists of a main sketch file, and several support files and
``components'' (libraries).

\subsection{Program Startup notes}

While most of the common node configuration is accessible using the available
CDI configuration tools (JMRI's PanelPro program or MRR SYS OpenLCB program),
some of the node's configuration is in separate non-volatile (flash) memory.
This includes the node's ID number and some boot options. As installed the
node ID is initialized to 05:01:01:01:22:00. \textbf{You don't really want to
leave this as the node id!} There are two ways to set the node id. One way is
to use a CDI configuration tool -- the node ID is exposed as a configuration
option. Changing the node id forces a ``factory reset'' on the next boot (and
when you update the configuration with a CDI configuration tool, the node
will reboot). The other way is during the boot up process. When the node
boots, it waits on the USB serial connection for 10 seconds for any
``keyboard'' response and if it gets a ``keyboard'' response, it enters a
simple command line loop accepting simple commands (mostly single letters). To
use this feature you need to connect a a USB cable between the TTGO-T7S3 and a
computer (eg a PC or Mac) and then connect to the USB Com port with a terminal
program (the Arduino IDE Serial Monitor should work). The commands that the
boot startup command line loop supports are:

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

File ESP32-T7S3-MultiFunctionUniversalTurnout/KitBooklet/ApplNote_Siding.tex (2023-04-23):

%%%%%%%%%%%%%%%%%%%%%%%%%%%%%%%%%%%%%%%%%%%%%%%%%%%%%%%%%%%%%%%%%%%%%%%%%%%%%
%
%  System        : 
%  Module        : 
%  Object Name   : $RCSfile$
%  Revision      : $Revision$
%  Date          : $Date$
%  Author        : $Author$
%  Created By    : Robert Heller
%  Created       : Sat Apr 15 10:33:56 2023
%  Last Modified : <230419.1529>
%
%  Description 
%
%  Notes
%
%  History
% 
%%%%%%%%%%%%%%%%%%%%%%%%%%%%%%%%%%%%%%%%%%%%%%%%%%%%%%%%%%%%%%%%%%%%%%%%%%%%%
%
%    Copyright (C) 2023  Robert Heller D/B/A Deepwoods Software
%			51 Locke Hill Road
%			Wendell, MA 01379-9728
%
%    This program is free software; you can redistribute it and/or modify
%    it under the terms of the GNU General Public License as published by
%    the Free Software Foundation; either version 2 of the License, or
%    (at your option) any later version.
%
%    This program is distributed in the hope that it will be useful,
%    but WITHOUT ANY WARRANTY; without even the implied warranty of
%    MERCHANTABILITY or FITNESS FOR A PARTICULAR PURPOSE.  See the
%    GNU General Public License for more details.
%
%    You should have received a copy of the GNU General Public License
%    along with this program; if not, write to the Free Software
%    Foundation, Inc., 675 Mass Ave, Cambridge, MA 02139, USA.
%
% 
%
%%%%%%%%%%%%%%%%%%%%%%%%%%%%%%%%%%%%%%%%%%%%%%%%%%%%%%%%%%%%%%%%%%%%%%%%%%%%%

\subsection{Siding with local control panel}
\label{sect-appl:siding}
\begin{figure}[hbpt]\begin{centering}%
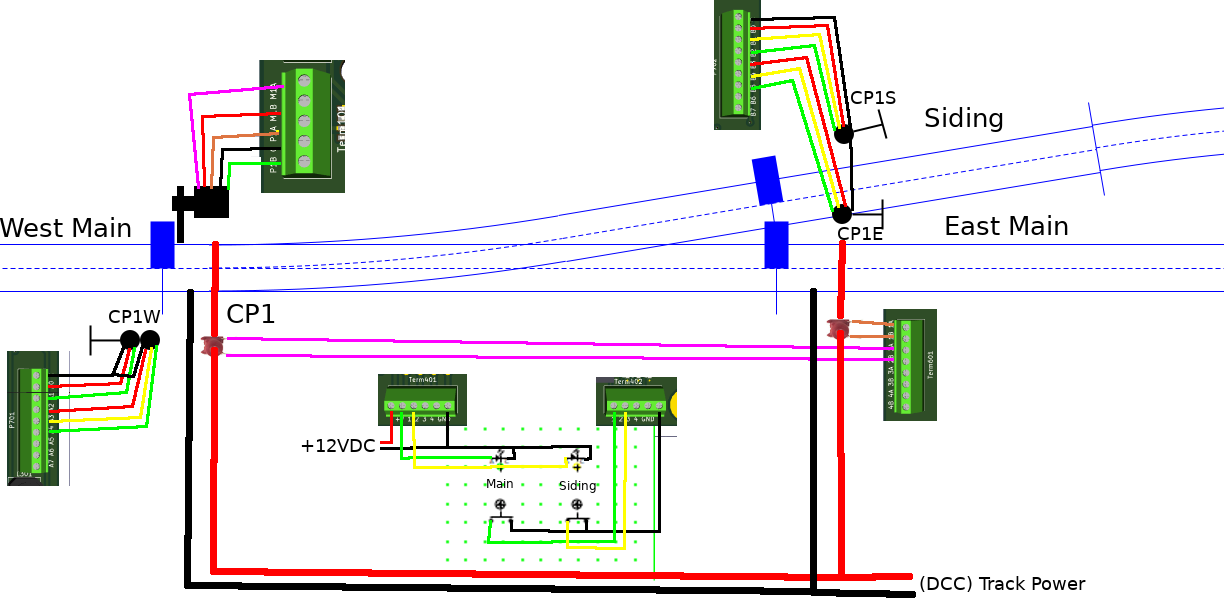
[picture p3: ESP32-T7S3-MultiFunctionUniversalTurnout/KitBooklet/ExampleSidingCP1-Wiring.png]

\caption{One end of a siding (CP1) with local and remote control, with 
signals.}
\label{fig:ExampleSidingCP1-Wiring}
\end{centering}\end{figure}

This is a basic single turnout with a facia panel with two LEDs indicating the
turnout points' position and two push buttons to select the desired turnout
position. There also is a two headed (3 over 2) interlocking signal at the
turnout's points, and a pair of single head (3 color) signals at the frog
ends. The turnout's wiring is shown in 
Figure~\ref{fig:ExampleSidingCP1-Wiring}. We will use one of the turnout 
drivers (the Stall Motor daughter board is shown, but any of the daughter 
boards could be used), two of the occupancy detectors, two of the LED drivers, 
two of button inputs, and 11 of signal lamp driver outputs.

We will start by configuring the user name and description of the node in User 
Info tab.  When we have done this will will be able to find the node by 
looking for the name.  

Next, we will move onto the Board Configuration tab and then the Occupancy
Detectors, specificly OC1. Right now, we will just fill in the name (East
Main) and create a Block layout control. Similarly for OC2 (CP1 OS).

Similarly we configure the Turnout and Points, filling their names and
creating layout control elements for them, along with the veto control
element. The layout control elements (or various JMRI table elements). 

Next we set up the logic for the Veto. We want to enable the turnout veto in
two cases: dispatcher locking or OS occupancy, so we need one logic element
for this. We name the Logic ``Veto On'', copy the OS Occupancy detector events
to Variable 2 (Variable 1 will be used by the dispatcher to lock the turnout),
set the Logic to V1 OR V2. The actions for both true and false will be send
and exit. Action event 1 will be Send Immediately on True and the Turnout Veto
On event will be copied to the action event. Action event 2 will be Send
Immediately on False and the the Turnout Veto Off event will be copied to the
action event.

Next we set up the LED drivers and the button inputs. We copy the turnout's
Normal and Reverse motor events to the two button ON events and label the
buttons Normal and Reverse. Similarly we copy the Point sensor events to the
LEDs' events. For the Normal labeled LED, copy the Point sensor Normal event
to the on event, and the Point sensor Reverse event to the off event. Then for
the Reverse labeled LED, copy the Point sensor Reverse event to the on event, 
and the Point sensor Normal event to the off event.

For the signals, we will use additional Logics and three Masts.  For each 
signal will will construct an sequence of logic elements, one for each aspect, 
starting with the most restrictive and ending with the least restrictive.  
Each logic element will test one or two conditions and be true for one aspect.

For the signal at the point entry of the turnout we are using a two headed
signal, a 3 over 2 (3 lamps (GYR) on the top head, 2 lamps (GR or YR) on the
bottom head). This signal will display 4 aspects: Stop (red over red),
Approach Limited (red over green or yellow), Approach (yellow over red), and 
Clear (green over red).  These aspects mean: 

\begin{itemize}
\item Stop (red over red) Absolute stop.  Typically because the turnout is 
currently occupied or the dispatcher forbids traversal.
\item Approach Limited (red over green or yellow) Slow speed, taking the 
siding.  This is when the turnout is thrown.
\item Approach (yellow over red) Reduced speed continuing on the main.  This 
is when there is a Stop indication at the next signal.
\item  Clear (green over red) Normal speed continuing on the main.  This is 
when no other cases prevail.
\end{itemize}

Select the Mast 1 tab under the Rule to aspect tab under Board Configuration. 
Select Normal under Mast Processing and enter a Mast ID of CP1W for the Mast 
ID.  Then copy the Track Circuit Link Address to Circuit 1 under TRACK 
CIRCUITS and set the Remote Mast Description  to CP1W.

Back at Rule to aspect / Mast 1 scroll down to the Rules. Under Rule 1's
Appearance, set Lamp 1 to A0, and Lamp 2 to A2. These are the two red lamps.
Now select tab Rule 2.  Set Name to 27-Approach-Limited and Track Speed to 
Limited.  Then for its Appearance, set Lamp 1 to A1 and Lamp 2 to A2. Moving 
on to Rule 3: Set Name to 21-Approach and Track Speed to Approach.  Then Lamp 
1 to A0, and Lamp 2 A3.  Finally for Rule 4: Set Name to 29-Clear and Track 
Speed to Clear/Procede and Lamp 1 to A0, and Lamp 2 to A4. This completes 
setting up the mast.

The logic for this mast is:

\begin{verbatim}
if (TurnoutOS is occupied) then
    send Stop
else if (Turnout is Reversed) then
    send Approach Limited
else if (track circuit(next block) is Stop) then
    send Approach
else
    send Clear
\end{verbatim}

We will need 4 successive Logic elements for this mast, but first we need to 
create a virtual mast for the block identified as East Main.  We will use Mast 
8 and Circuit 8 for this mast.  Select Mast 8, set its Mast Processing to 
Normal, its Mast ID to CP1ME, and copy its Link Address to Circuit 8.  Now 
right click on the East Main OC in the Layout DB window, and copy its Occupied 
event to the event to set aspect for Rule 1 (Rule one is already set to Stop 
speed).  Then copy East Main's Clear event to the event to set aspect for Rule 
2, then change Rule 2's name to 29-Clear and Track Speed to Clear/Procede.  We 
won't be setting anything for this mast's Lamps, since it is not a ``visible'' 
signal.  We are just using it to general track circuit signals.

Now we can start to set up the Logic elements. We will start with Logic 4. Set
its description to ``CP1W Stop'', its Group Function to Group, copy CP1 OS OC
detector's events to Variable \#1's events: true from Occupied, false from
Clear. Set the Logic function to V1 only, set Action 1 to Immediate If True
and copy the event from Mast 1, Rule 1's ``(C) Event to Set Aspect'' event to 
Action 1's event.

Next we set up Logic 5. Set its description to ``CP1W Approach Limited'', its 
Group Function to Group, copy the Points 1 sense detector's events to Variable 
\#1's events: true from Reversed, false from Normal -- we want *true* if the 
turnout is set to the siding. Set the Logic function to V1 only, set Action 1 
to Immediate If True  and copy the event from Mast 1, Rule 2's ``(C) Event to 
Set Aspect'' event to Action 1's event.

Next we set up Logic 6. Set its description to ``CP1W Approach'', its Group 
Function to Group, its variable source to Track Circuit 8.  Use the default 
speed of Stop.  Set the Logic function to V1 only, set Action 1 to Immediate 
If True  and copy the event from Mast 1, Rule 3's ``(C) Event to Set Aspect'' 
event to Action 1's event.

Finally we set up Logic 7. Set its description to ``CP1W Clear'', its Group 
Function to Last (Single), set its Logic function to null $=>$ true, set Action 
1 to Immediate If True  and copy the event from Mast 1, Rule 4's ``(C) Event 
to Set Aspect'' event to Action 1's event.

Next we need to set up the two signals at the frog end of the turnout.  They 
both the same aspects:

\begin{itemize}
\item Stop (red) Absolute stop.  Typically because the turnout is currently 
occupied, the points are aligned against travel, or the dispatcher forbids 
traversal.
\item Approach (yellow) Reduced speed continuing on the main.  This is when 
there is a Stop indication at the next signal.
\item  Clear (green) Normal speed continuing on the main.  This is when no 
other cases prevail.
\end{itemize}

We will set up these two signals on Mast 2 and Mast 3 and also set up a 
virtual mast for West Main using Mast 7.

First CP1E on Mast 2:

Set Mast Processing to Normal, Mast ID to CP1E, copy the track circuit address 
to Circuit 2, along with the Mast ID to the Remote Mast Description. Rule 1's
Name will be 0-Stop, its speed Stop, and its Appearance will be Lamp 1: B3.
Rule 2's Name will be 21-Approach, its speed Approach, and its Appearance will 
be Lamp 1: B4. Rule 3's Name will be 29-Clear, its speed Clear/Procede, and 
its Appearance will be Lamp 1: B5.

Then CP1S on Mast 3:

Set Mast Processing to Normal, Mast ID to CP1S, copy the track circuit address 
to Circuit 3, along with the Mast ID to the Remote Mast Description. Rule 1's
Name will be 0-Stop, its speed Stop, and its Appearance will be Lamp 1: B0.
Rule 2's Name will be 21-Approach, its speed Approach, and its Appearance will 
be Lamp 1: B1. Rule 3's Name will be 29-Clear, its speed Clear/Procede, and 
its Appearance will be Lamp 1: B2.

Finally, we will create a virtual mast for West Main using Mast 7.  This will 
be set up much like we did for block identified as East Main, using Mast 7 and 
Circuit 7.  We can either use one of the unused occupancy detectors for this 
block, but more likely, there will be another occupancy detector for that 
block.

Next we will set up the logic for signals CP1E (Mast 2) and CP1S (Mast 3).  
These will each use three logic elements and will be very similar to the CP1W 
signal, but only using three logics since there are only three aspects for 
these signals.  The only special issue is the logic of the point position: 
CP1S displays Stop when the points are ``normal'' and CP1E displays Stop when 
the points are ``reversed'', and the Stop logic is ORed with the OS being 
occupied. Otherwise Approach with the virtual signal at Mast 7 is Stop, and 
Clear otherwise.

\begin{figure}[hbpt]\begin{centering}%

\caption{Example Siding CP1  Event Id graph.}
\label{fig:ExampleSidingCP1EventFlow}
\end{centering}\end{figure}
\begin{table}[hbpt]\begin{centering}%
\begin{tabular}{|l|l|p{2in}|}
\hline
Color&Object&What it is\\
\hline
Orange&Node&Occupancy Detectors\\
\hline
Green&Node&Siding normal button and LED\\
\hline
Red&Node&Siding reversed button and LED\\
\hline
Cyan&Node&Logic Elements\\
\hline
Blue&Node&Turnout Outputs\\
\hline
LightSeaGreen&Node&Point Sense Inputs\\
\hline
RoyalBlue&Node&Masts\\
\hline 
Green&Edge&Button and LED normal Events\\
\hline
Red&Edge&Button and LED reverse Events\\
\hline
Brown&Edge&Button Release Events\\
\hline
Green&Edge&Turnout Operating Events\\
\hline
Black&Edge&Logic Fall Throughs (Elses)\\
\hline
Orange&Edge&Odd Yard Tracks (1 and 3)\\
\hline
Violet&Edge&Even Yard Tracks (2 and 4)\\
\hline
Cyan&Edge&Mast Rule Selection\\
\hline
LightSeaGreen&Edge&Point Sense events\\
\hline
\end{tabular}
\caption{Graph color key}
\label{tab:ExampleSidingCP1EventFlow}
\end{centering}\end{table}

A graph of the Example (CP1) siding Event Id ``flow'' is shown in 
Figure~\ref{fig:ExampleSidingCP1EventFlow}, with its color coding shown in 
Table~\ref{tab:ExampleSidingCP1EventFlow}. This may look a but intimidating, 
but each ``edge'' (line with an arrow) represents a producer / consumer. When 
multiple edges land at a given spot, the edges all represent the \textit{same} 
event id. It is easiest to copy the destination (consumer) Event ID to each of 
the various producers.

\clearpage

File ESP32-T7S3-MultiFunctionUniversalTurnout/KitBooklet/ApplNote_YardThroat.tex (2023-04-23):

%%%%%%%%%%%%%%%%%%%%%%%%%%%%%%%%%%%%%%%%%%%%%%%%%%%%%%%%%%%%%%%%%%%%%%%%%%%%%
%
%  System        : 
%  Module        : 
%  Object Name   : $RCSfile$
%  Revision      : $Revision$
%  Date          : $Date$
%  Author        : $Author$
%  Created By    : Robert Heller
%  Created       : Sat Apr 15 10:37:45 2023
%  Last Modified : <230421.1221>
%
%  Description 
%
%  Notes
%
%  History
% 
%%%%%%%%%%%%%%%%%%%%%%%%%%%%%%%%%%%%%%%%%%%%%%%%%%%%%%%%%%%%%%%%%%%%%%%%%%%%%
%
%    Copyright (C) 2023  Robert Heller D/B/A Deepwoods Software
%			51 Locke Hill Road
%			Wendell, MA 01379-9728
%
%    This program is free software; you can redistribute it and/or modify
%    it under the terms of the GNU General Public License as published by
%    the Free Software Foundation; either version 2 of the License, or
%    (at your option) any later version.
%
%    This program is distributed in the hope that it will be useful,
%    but WITHOUT ANY WARRANTY; without even the implied warranty of
%    MERCHANTABILITY or FITNESS FOR A PARTICULAR PURPOSE.  See the
%    GNU General Public License for more details.
%
%    You should have received a copy of the GNU General Public License
%    along with this program; if not, write to the Free Software
%    Foundation, Inc., 675 Mass Ave, Cambridge, MA 02139, USA.
%
% 
%
%%%%%%%%%%%%%%%%%%%%%%%%%%%%%%%%%%%%%%%%%%%%%%%%%%%%%%%%%%%%%%%%%%%%%%%%%%%%%

\subsection{Yard Throat with track selector}
\label{sect-appl:yardthroat}

\begin{figure}[hbpt]\begin{centering}%
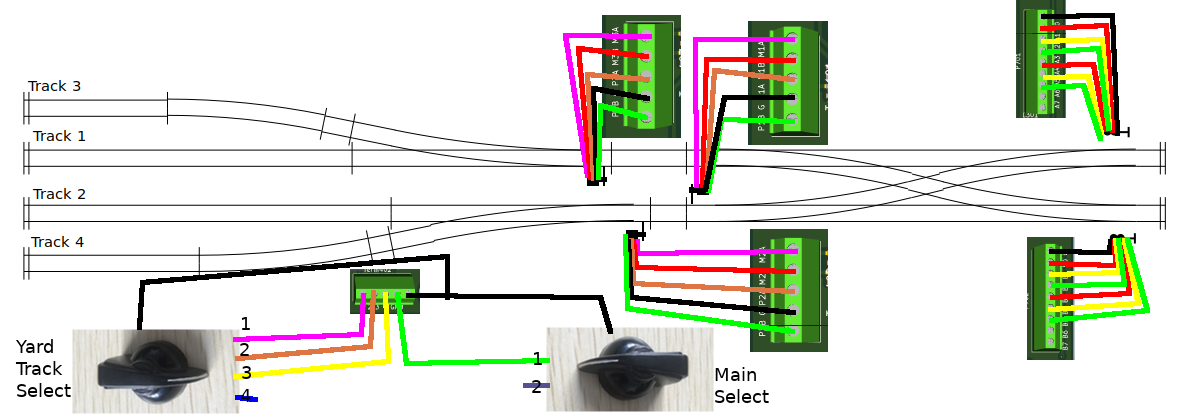
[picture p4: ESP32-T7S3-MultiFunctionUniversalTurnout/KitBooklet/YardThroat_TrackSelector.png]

\caption{Yard throat with yard ladders and selectors.}
\label{fig:YardThroatTrackSelector}
\end{centering}\end{figure}

This is the entrance to a yard from a double track main line with a scissors 
type crossover and a simple yard ladder.  There are two selector switches, one 
to select the main track and one to select the yard track.  There are a pair 
of signals at the yard entrance, one for each main line track.  These are 3 
over 3 signals.  The basic wiring is shown in 
Figure~\ref{fig:YardThroatTrackSelector}. We will use three turnout drivers 
(the Stall Motor daughter board is shown, but any of the daughter 
boards could be used), 12 of the signal lamp driver outputs, and all four of 
the button inputs.

We will start by configuring the user name and description of the node in User 
Info tab.  When we have done this will will be able to find the node by 
looking for the name.  

Next, we will move onto the Board Configuration tab and give names to the 
Turnout and Points we will be using.

Then we will move onto the button inputs.  The rotary switches total 6 
positions, but we can get by with only 4 inputs, by leaving one position of 
each switch unconnected.  This works because we get extra state information in 
the form of ``none of the above'' -- when all three of buttons 1, 2, and 3 are 
``off'', yard track 4 is selected and when button 4 is off, main track 2 is 
selected.

The logic for the yard track selection is:

\begin{verbatim}
if button1 is on then
  track 1 selected
else if button2 is on then
  track 2 selected
else if button3 is on then
  track 3 selected
else
  track 4 selected
\end{verbatim}

and the logic for the main track selection is:

\begin{verbatim}
if button4 is on then
  main track 1 selected
else
  main track 2 selected
\end{verbatim}

The logic for the scissors crossover is:

\begin{verbatim}
if ( track 1 selected OR track 3 selected) AND 
   main track 1 selected then
  NORMAL
else if ( track 1 selected OR track 3 selected) AND 
        main track 2 selected then
  REVERSE
else if ( track 2 selected OR track 4 selected) AND 
        main track 1 selected then
  REVERSE
else if ( track 2 selected OR track 4 selected) AND 
        main track 2 selected then
  NORMAL
\end{verbatim}

This may \textit{look} formidable, but we can simplify things using a
``trick'' -- a kind of ``wired or'', by using a common event id to represent a
common routing for the odd and even yard tracks. This simplifies things to

\begin{verbatim}
if common odd tracks AND main track 1 selected then
  NORMAL
else if common even tracks AND main track 2 selected then
  NORMAL
else if common even tracks AND main track 1 selected then
  REVERSE
else if common odd tracks AND main track 2 selected then
  REVERSE
\end{verbatim}

We will start by allocating four successive logic elements, setting first
three to have a Group Function of Group and the last to have a Group Function
of Last (Single). We will set the descriptions of these logic elements to
``Track 1'', ``Track 2'', ``Track 3'', and ``Track 4''. The first three will
have a Logic function of V1 only, and the last to null $=>$ true. We will copy
the button event ids from Buttons 1 through 3 to the V1 events of the first
three logic elements: the ``Button Pushed'' event ids to the ``set variable
true'' event ids and the ``Button Released`'' event ids to the ``set variable
false'' event ids.

We will set action 1 of each of these logic elements to an action of Immediate 
if True, and copy the event ids as follows:

\begin{itemize}
\item Track 1: to Turnout 3's Normal.
\item Track 2: to Turnout 2's Normal.
\item Track 3: to Turnout 3's Reverse.
\item Track 4: to Turnout 2's Reverse.
\end{itemize}

Next we will allocate four more Logic elements. Name these ``Main Track 1
Odd'', ``Main Track 2 Even'', ``Main Track 1 Even'', and ``Main Track 2 Odd''.
Set the Group Function of all of them to Last (Single). Set the Logic Function
of all four to V1 and V2. Copy Button 4's ``Button Pushed'', and ``Button
Released'' event to the V1 ``Set variable true'' of both ``Main Track 1''
logics' ``Set variable true'' (Button Pushed) and ``Set variable false''
(Button Released). Copy Button 4's ``Button Pushed'', and ``Button Released''
event to the V1 ``Set variable true'' of both ``Main Track 2'' logics' ``Set
variable true'' (Button Released) and ``Set variable false'' (Button Pushed).
For the variable V2 events we will copy their events to to the Action 2 events
of the Track 1 through Track 4 logics. The odd logics V2 true to get copied to
the odd tracks and their V2 false get copied to the even tracks. And it is
swapped for the even logics. We will end up with two event ids:

\begin{itemize}
\item Odd tracks true / Even tracks false Event: Action 2 events of Track 1 
and Track 3 and the V2 true of ``Main Track 1 Odd'' and ``Main Track 2 Odd'' 
and the V2 false of ``Main Track 1 Even'' and ``Main Track 2 Even''.
\item Even tracks true / Odd tracks false Event: Action 2 events of Track 2 
and Track 4 and the V2 true of ``Main Track 1 Even'' and ``Main Track 2 Even'' 
and the V2 false of ``Main Track 1 Odd'' and ``Main Track 2 Odd''.
\end{itemize}

Finally, we set up the signals.  Each signal is a 3 over 3 signal, with these 
aspects:
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

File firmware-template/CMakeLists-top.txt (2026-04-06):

# The following lines of boilerplate have to be in your project's
# CMakeLists in this exact order for cmake to work correctly
cmake_minimum_required(VERSION 3.5)

include($ENV{IDF_PATH}/tools/cmake/project.cmake)

if (IDF_VERSION_MAJOR LESS 4)
    message(FATAL_ERROR "ESP32IO requires IDF v4.2 (or newer)")
endif()
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

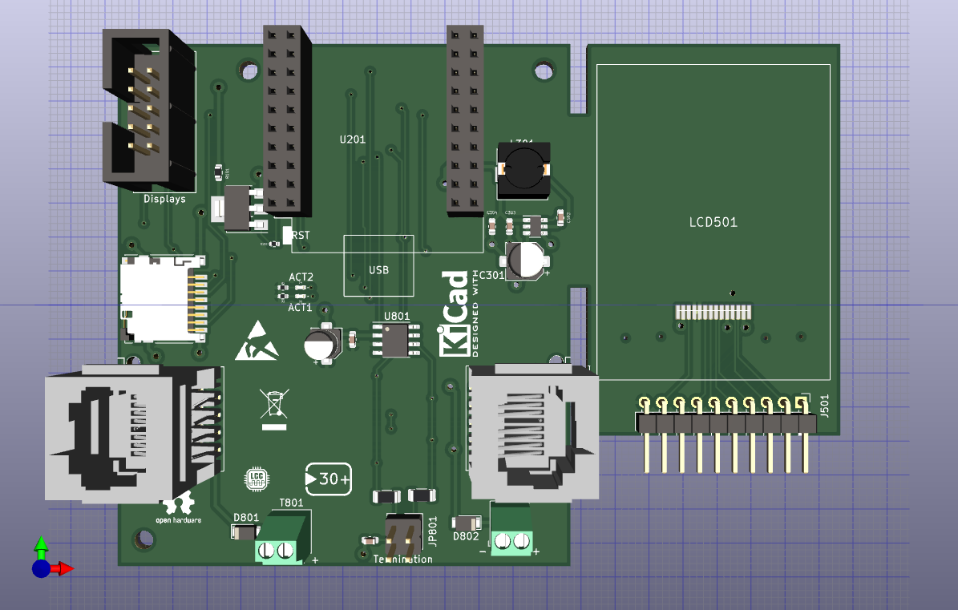
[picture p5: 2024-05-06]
ESP32-T7S3-TextDisplaySign/firmware/doc/images/ESP32-T7S3-TextDisplaySign.png

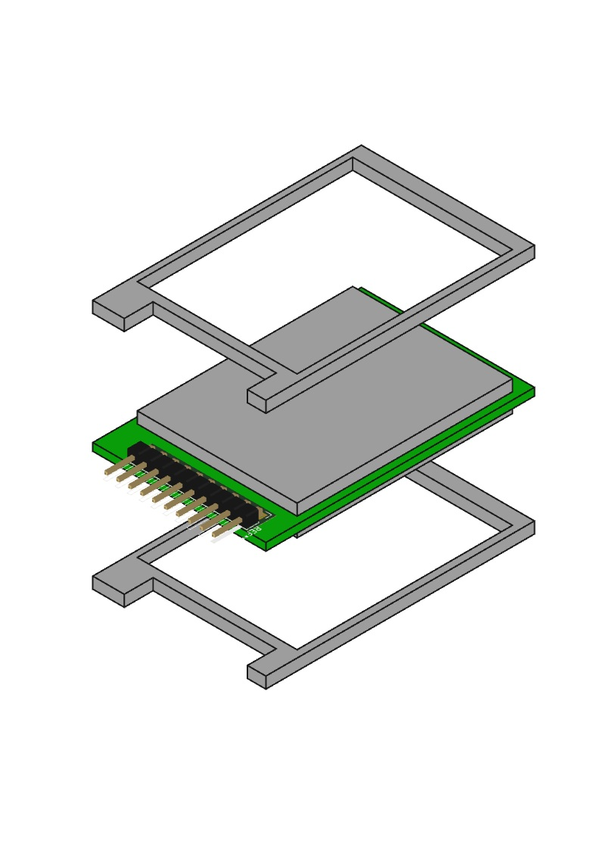
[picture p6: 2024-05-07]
ESP32-T7S3-TextDisplaySign/firmware/doc/images/DisplayBoard.png

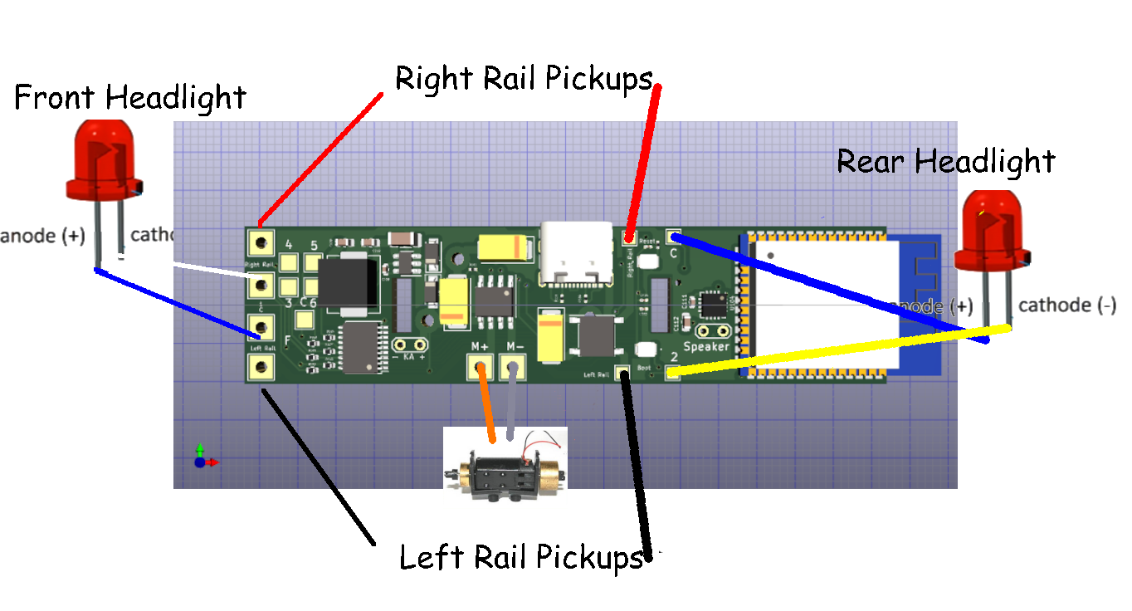
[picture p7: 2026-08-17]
AtlasLightBoardWiFiLCCTraction_Sound/firmware/doc/Images/AtlasLightBoardWiFiLCCTraction_Sound_Top3D_Annotated.png

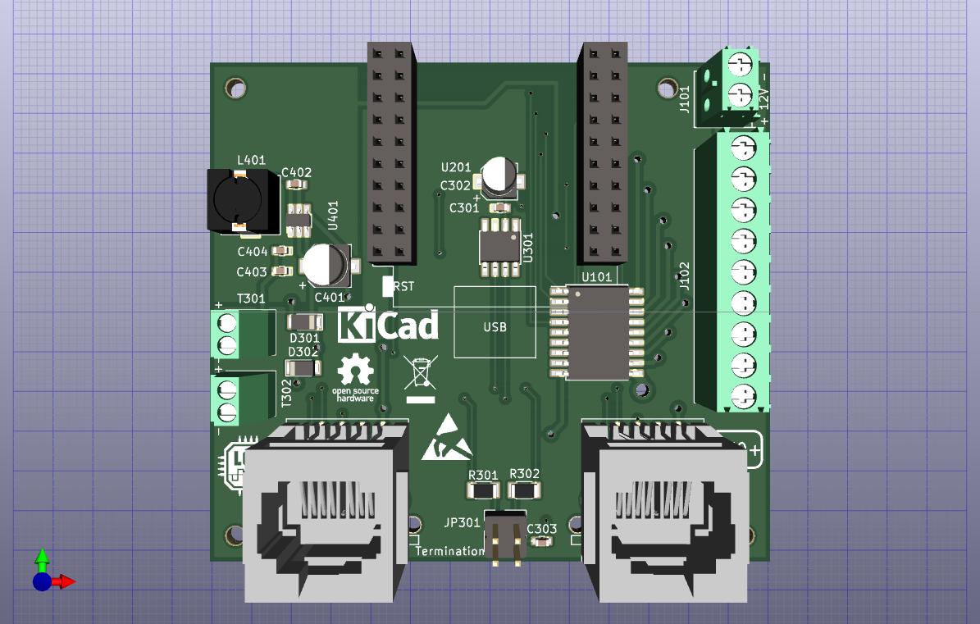
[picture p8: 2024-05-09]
ESP32-Mini32-OctalBuffer/KitBooklet/images/ESP32-Mini32-OctalBuffer.png

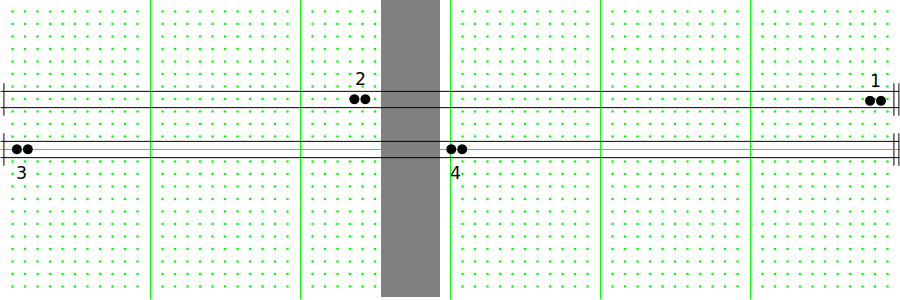
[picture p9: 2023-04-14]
ESP32-T7S3-ArduinoBase/firmware/doc/images/LowRes12Tracks.png

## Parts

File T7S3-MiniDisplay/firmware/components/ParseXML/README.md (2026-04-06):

ParseXML -- ported from ParseXML.tcl and includes TinyXML Library forked from
Adafruit's fork from Adam Rudd's (adamvr) 'arduino-sketches' repository:
https://github.com/adamvr/arduino-sketches
and updated for esp-idf (non-arduino).  I also encased it into its own 
namespace.

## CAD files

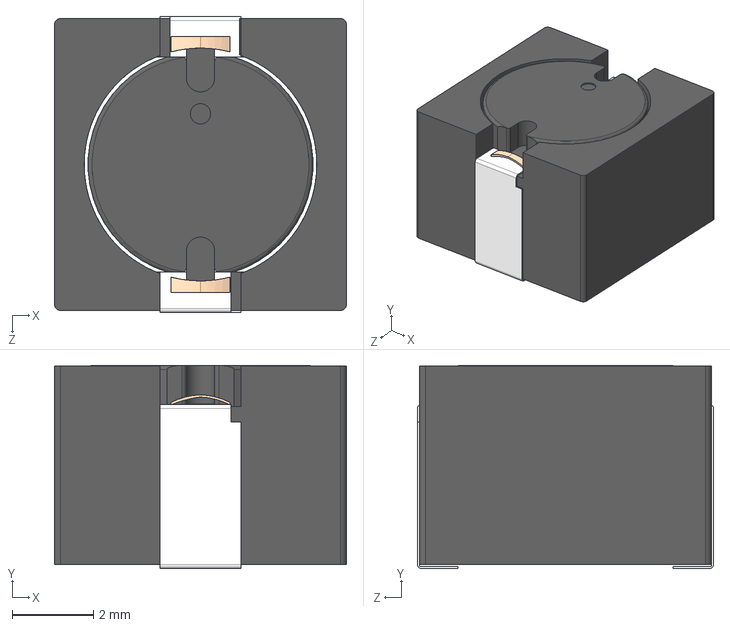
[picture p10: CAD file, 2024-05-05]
ESP32-Feather-6B6L-SMD/B1047AS-4R7N=P3.stp
7.20 x 5.01 x 7.30 mm

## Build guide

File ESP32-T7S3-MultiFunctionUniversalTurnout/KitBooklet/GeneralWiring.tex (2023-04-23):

%%%%%%%%%%%%%%%%%%%%%%%%%%%%%%%%%%%%%%%%%%%%%%%%%%%%%%%%%%%%%%%%%%%%%%%%%%%%%
%
%  System        : 
%  Module        : 
%  Object Name   : $RCSfile$
%  Revision      : $Revision$
%  Date          : $Date$
%  Author        : $Author$
%  Created By    : Robert Heller
%  Created       : Sat Apr 15 10:32:29 2023
%  Last Modified : <230423.1213>
%
%  Description 
%
%  Notes
%
%  History
% 
%%%%%%%%%%%%%%%%%%%%%%%%%%%%%%%%%%%%%%%%%%%%%%%%%%%%%%%%%%%%%%%%%%%%%%%%%%%%%
%
%    Copyright (C) 2023  Robert Heller D/B/A Deepwoods Software
%			51 Locke Hill Road
%			Wendell, MA 01379-9728
%
%    This program is free software; you can redistribute it and/or modify
%    it under the terms of the GNU General Public License as published by
%    the Free Software Foundation; either version 2 of the License, or
%    (at your option) any later version.
%
%    This program is distributed in the hope that it will be useful,
%    but WITHOUT ANY WARRANTY; without even the implied warranty of
%    MERCHANTABILITY or FITNESS FOR A PARTICULAR PURPOSE.  See the
%    GNU General Public License for more details.
%
%    You should have received a copy of the GNU General Public License
%    along with this program; if not, write to the Free Software
%    Foundation, Inc., 675 Mass Ave, Cambridge, MA 02139, USA.
%
% 
%
%%%%%%%%%%%%%%%%%%%%%%%%%%%%%%%%%%%%%%%%%%%%%%%%%%%%%%%%%%%%%%%%%%%%%%%%%%%%%

\section{General Wiring Notes}

\subsection{Main board}
\begin{figure}[hbpt]\begin{centering}%
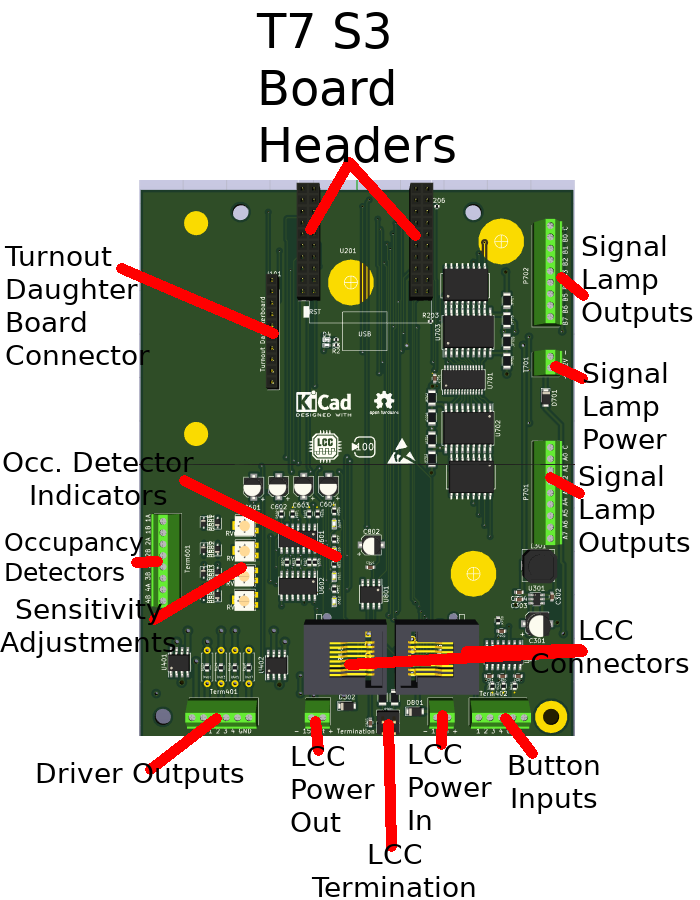
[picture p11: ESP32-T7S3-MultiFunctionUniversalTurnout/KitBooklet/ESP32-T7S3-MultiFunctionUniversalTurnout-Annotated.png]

\caption{ESP32 T7S3 MultiFunctionUniversalTurnout board, annotated}
\end{centering}\end{figure}

There are various terminal blocks, connectors, and jumper blocks on this
board.  

On the left side is a 10 position socket header for the turnout daughter board
and an 8 position terminal block for the four CT coil occupancy detectors,
Along the bottom is the 6 position terminal block for the driver outputs, then
come the terminal block to extracting power from the LCC bus. Then there is
the termination jumper block for the LCC bus. Then there is terminal block for
injecting power into the LCC bus. Above the LCC power terminal blocks are a
pair of RJ45 connectors. These are for connecting the board to the LCC bus.
These connectors are wired in parallel. On the right side of the board are two
9 position terminal blocks for the signal lamp LEDs. Finally, between the
terminal blocks for the signal lamp LEDs is a two position terminal block to
(optionally) provide power for the signal lamp LEDs.

\subsubsection{Turnout Daughter board connector}

Starting on the upper left, there is a 10 position socket header for the 
turnout daughter board.  The socket mates with the 10 position pin array on 
the underside of the Turnout Daughter board.  The Turnout Daughter boards' 
terminal blocks are described below in Sections~\ref{sect:SM-Daughter}, 
\ref{sect:TS-Daughter}, \ref{sect:SC-Daughter}, and \ref{sect:TC-Daughter}.

\clearpage
\subsubsection{Occupancy Detectors}
\begin{figure}[hbpt]\begin{centering}%
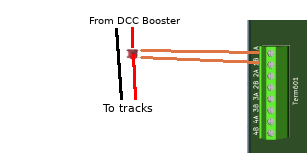
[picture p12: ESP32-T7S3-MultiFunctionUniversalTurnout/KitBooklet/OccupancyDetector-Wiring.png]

\caption{Occupancy Detector Wiring}
\end{centering}\end{figure} 

Then on the lower left side is an 8 position terminal block for the four CT 
coil occupancy detectors.  Each adjacent pair of terminals is for one twisted 
pair cable to one CT coil for one feeder wire for one block. There is a 
sensitivity adjustment trimmer and an indicator LED for each detector.

\subsubsection{Driver Outputs}

There is a 6 position terminal block for the four driver outputs. There are
1500 Ohm load resistors on board, which are suitable for driving LEDs with a
12V supply. There are places for adding through hole load resistors to allow
for increased load current. The driver outputs require an external power
source, typically 12V. The driver chips are totem pole (push-pull), so can
drive both high side and low side, up to 1.5 Amps.

\subsubsection{LCC Power}

Power can be optionally injected into the LCC bus or extracted from the LCC 
bus. Power can be injected to into the LCC bus to power this and other boards. 
Power can also be extracted to power local devices.

\subsubsection{LCC Network Connectors}

There are two RJ45 connectors for the LCC Network. Connect a CAT5 or CAT6
(Ethernet) cable of at least 1 foot in length to the next and previous node in
the network. If this is the last node, only one connector is used and
termination jumpers should be installed. See Section~\ref{sect:termination}.

\subsubsection{Button (or switch) Inputs}

There is a 5 position terminal block for button (or switch) inputs.  These are 
Schmitt-trigger inputs and are referenced to ground (supplied on the fifth 
position of the terminal block).

\subsubsection{PWM Signal Lamp drivers}

There are two 9 position terminal blocks for the sixteen PWM Signal Lamp 
outputs (two banks of 8) and there is a two position terminal block to 
provide (optional) external power for the signal lamps.  These terminal blocks 
are on the right side of the board.  The boards can be built to be either for 
common anode or common cathode.

\clearpage
\subsubsection{LCC Termination}
\label{sect:termination}
\begin{figure}[hbpt]\begin{centering}%
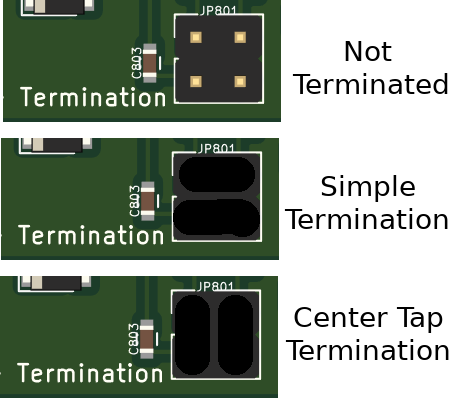
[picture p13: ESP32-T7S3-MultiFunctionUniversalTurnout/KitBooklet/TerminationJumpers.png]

\caption{Termination Options}
\label{fig:termination}
\end{centering}\end{figure}

There are three options for termination: none, simple, and center tap, as 
shown in Figure~\ref{fig:termination}.

\subsection{Stall Motor Turnout daughter board}
\label{sect:SM-Daughter}
\begin{figure}[hbpt]\begin{centering}%
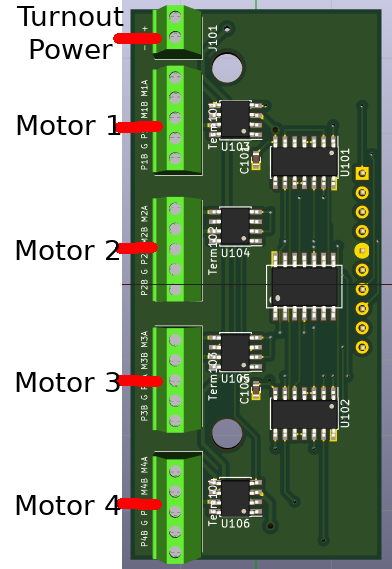
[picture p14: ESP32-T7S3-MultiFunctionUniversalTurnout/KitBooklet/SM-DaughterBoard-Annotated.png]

\caption{Stall Motor Turnout daughter board, annotated}
\end{centering}\end{figure}
\begin{figure}[hbpt]\begin{centering}%
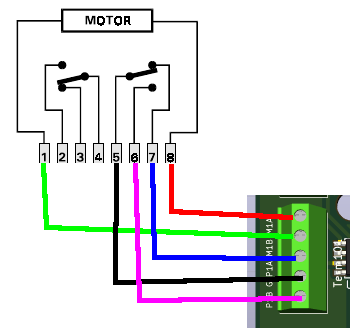
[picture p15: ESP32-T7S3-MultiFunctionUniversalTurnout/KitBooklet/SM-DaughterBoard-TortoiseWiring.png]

\caption{Stall Motor Turnout daughter board, wired to a Tortoise.}
\end{centering}\end{figure}

The Stall Motor Turnout daughter board can drive Circuitron Tortoise and
similar slow motion, stall motor switch machines. There is a 2 position
terminal block for a 12-15 volt supply to drive the stall motors and four 5
position terminal blocks, one for each motor. Each 5 position terminal block
has motor A and B connection for the motors and a point A and B and a ground
(G) connection for the point sense. The motor A and B connections go to the
Tortoises 1 and 8 pins, and the other three can be connected to one of the
poles of the internal switch contacts to report point sense -- the G to the
common.

\subsection{Servo Turnout daughter board}
\label{sect:TS-Daughter}
\begin{figure}[hbpt]\begin{centering}%
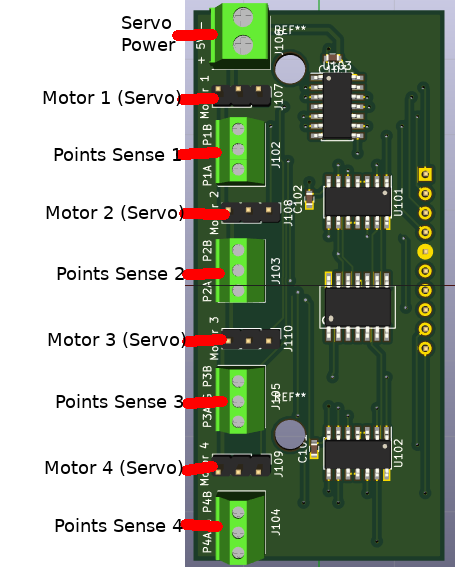
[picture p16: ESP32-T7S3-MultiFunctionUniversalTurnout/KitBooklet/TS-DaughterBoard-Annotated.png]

\caption{Servo Turnout daughter board, annotated}
\end{centering}\end{figure}

The Servo Turnout daughter board can drive standard 5V servos. There a 2
position terminal block for a 5 volt power supply to drive the servos, four
3-pin headers for standard servo connectors, along with four 3 position
terminal blocks for point sense.

\subsection{Single Coil Turnout daughter board}
\label{sect:SC-Daughter}
\begin{figure}[hbpt]\begin{centering}%
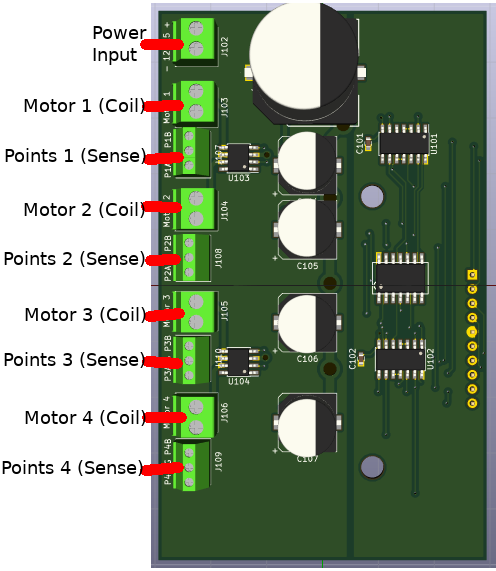
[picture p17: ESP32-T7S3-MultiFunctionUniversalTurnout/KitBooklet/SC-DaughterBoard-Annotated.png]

\caption{Single Coil Turnout daughter board, annotated}
\end{centering}\end{figure}

The Single Coil Turnout daughter board can drive single coil snap action
turnouts, typically Kato turnout motors. This a capacitive discharge type
driver circuit. There is a 2 position terminal block for a 12-15 volt power
supply to charge the capacitors.  There is a larger 2 position terminal block 
for each coil, along with a smaller 3 position terminal block point sense for 
each of four turnouts.

\subsection{Twin Coil Turnout daughter board}
\label{sect:TC-Daughter}
\begin{figure}[hbpt]\begin{centering}%
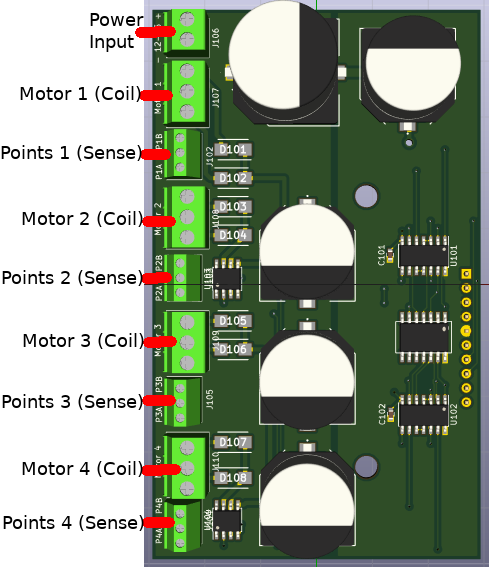
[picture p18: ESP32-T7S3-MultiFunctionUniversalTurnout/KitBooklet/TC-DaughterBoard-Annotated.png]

\caption{Twin Coil Turnout daughter board, annotated}
\end{centering}\end{figure}                                                    
 
The Twin Coil Turnout daughter board can drive twin coil snap action turnouts,
such as Atlas or Peco switch machines. This a capacitive discharge type driver
circuit. There is a 2 position terminal block for a 12-15 volt power supply to
charge the capacitors. There is a larger 3 position terminal block for each
pair of coils, along with a smaller 3 position terminal block point sense for
each of four turnouts.

\clearpage

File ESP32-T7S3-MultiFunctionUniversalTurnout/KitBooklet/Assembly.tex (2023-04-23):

%%%%%%%%%%%%%%%%%%%%%%%%%%%%%%%%%%%%%%%%%%%%%%%%%%%%%%%%%%%%%%%%%%%%%%%%%%%%%
%
%  System        : 
%  Module        : 
%  Object Name   : $RCSfile$
%  Revision      : $Revision$
%  Date          : $Date$
%  Author        : $Author$
%  Created By    : Robert Heller
%  Created       : Sat Apr 15 10:30:00 2023
%  Last Modified : <230415.1030>
%
%  Description 
%
%  Notes
%
%  History
% 
%%%%%%%%%%%%%%%%%%%%%%%%%%%%%%%%%%%%%%%%%%%%%%%%%%%%%%%%%%%%%%%%%%%%%%%%%%%%%
%
%    Copyright (C) 2023  Robert Heller D/B/A Deepwoods Software
%			51 Locke Hill Road
%			Wendell, MA 01379-9728
%
%    This program is free software; you can redistribute it and/or modify
%    it under the terms of the GNU General Public License as published by
%    the Free Software Foundation; either version 2 of the License, or
%    (at your option) any later version.
%
%    This program is distributed in the hope that it will be useful,
%    but WITHOUT ANY WARRANTY; without even the implied warranty of
%    MERCHANTABILITY or FITNESS FOR A PARTICULAR PURPOSE.  See the
%    GNU General Public License for more details.
%
%    You should have received a copy of the GNU General Public License
%    along with this program; if not, write to the Free Software
%    Foundation, Inc., 675 Mass Ave, Cambridge, MA 02139, USA.
%
% 
%
%%%%%%%%%%%%%%%%%%%%%%%%%%%%%%%%%%%%%%%%%%%%%%%%%%%%%%%%%%%%%%%%%%%%%%%%%%%%%

\section{Assembly}
\begin{figure}[hbpt]\begin{centering}%
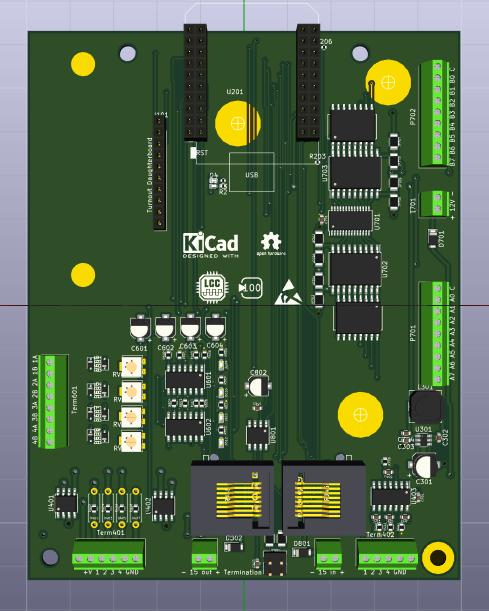
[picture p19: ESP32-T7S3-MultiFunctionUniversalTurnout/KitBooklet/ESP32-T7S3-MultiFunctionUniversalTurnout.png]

\caption{3D image of the ESP32 T7S3 MultiFunctionUniversalTurnout board}
\end{centering}\end{figure}
\begin{figure}[hbpt]\begin{centering}%
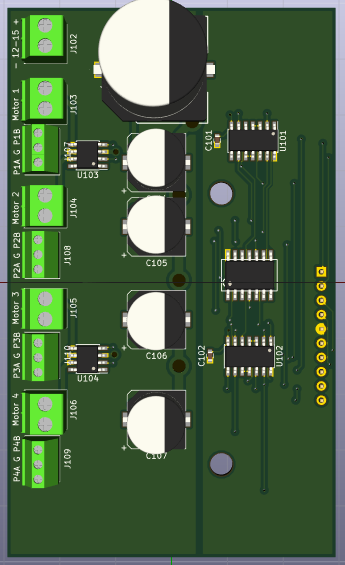
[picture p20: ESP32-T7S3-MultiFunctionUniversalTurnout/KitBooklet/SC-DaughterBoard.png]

\caption{3D image of the Single Coil Turnout driver daughter board}
\end{centering}\end{figure}
\begin{figure}[hbpt]\begin{centering}%
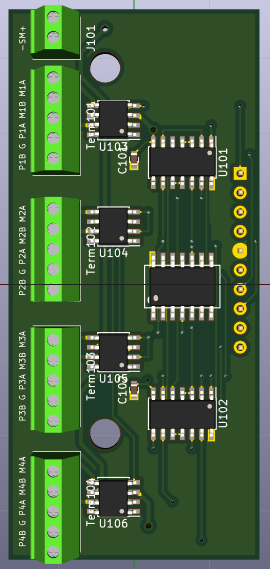
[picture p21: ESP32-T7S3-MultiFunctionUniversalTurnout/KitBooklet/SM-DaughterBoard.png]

\caption{3D image of the Stall Motor driver daughter board}
\end{centering}\end{figure}
\begin{figure}[hbpt]\begin{centering}%
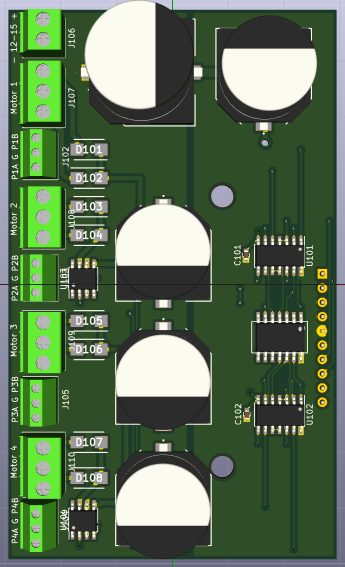
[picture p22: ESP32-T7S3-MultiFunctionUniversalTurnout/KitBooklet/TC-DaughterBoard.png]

\caption{3D image of the Twin Coil driver daughter board}
\end{centering}\end{figure}
\begin{figure}[hbpt]\begin{centering}%
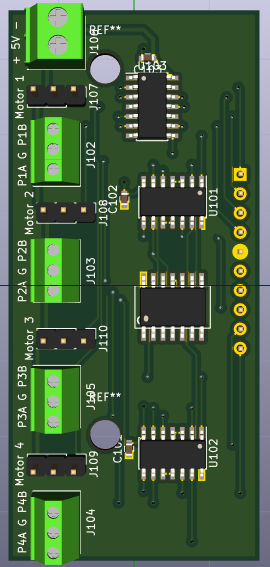
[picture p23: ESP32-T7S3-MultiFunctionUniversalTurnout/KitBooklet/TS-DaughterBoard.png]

\caption{3D image of the Servo driver daughter board}
\end{centering}\end{figure}
\clearpage

The boards have all of the SMD parts factory installed. Only the through-hole
parts are not soldered to the board. These are the RJ45 Jacks, the Termination
Jumper, the turnout daughter board header, the min32 headers, the daughter
board support standoffs, and the terminal blocks. The daughter boards also
have all of their SMD parts factory installed, and just needs their terminal
blocks and board inter-connect pin array headers installed. These are all easy
to solder parts. Make sure the headers and terminal blocks are fully seated
and square to the boards. A simple trick is to solder one pin and then while
pressing the part to the board, reheat that one pin's solder pad and snapping
the part to the board and holding it tight and square to the board as the
solder cools. Important: make sure the wire entry holes in the terminal blocks
are facing the edge of the board! The RJ45 Jacks cannot be installed wrong
(they have orientation pins). Start with the shortest parts and work up to the
tallest. Note: the pin array on the daughter board goes on the bottom of the
board and is soldered on the top side.

%% Need photo of a daughter board's pin array.

\begin{figure}[hbpt]\begin{centering}%
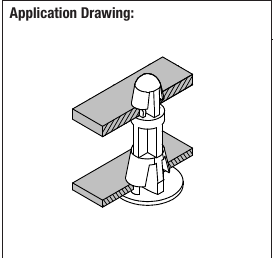
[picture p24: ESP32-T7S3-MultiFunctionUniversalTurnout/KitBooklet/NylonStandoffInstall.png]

\caption{Nylon Standoff Installation}
\end{centering}\end{figure}

The daughter boards are supported with a pair of nylon standoffs.  These are 
pushed through from the bottom of the main board.

You also need to solder the 2x10 pin headers to the bottom of the T7S3 board.

%% Add photo

Once all of the soldering is done, the T7S3 can be installed on the main board.
The WiFi antenna extends beyond the top of the board, with the T7S3's USB 
connector facing into the center of the board.  The daughter board's pin array 
goes in the socket header on the main board and there are two holes in the 
daughter board that engage the nylon standoffs.

%% Need a photo of a daughter board being installed on the main board 
%% and probably one of the T7S3 installed on the main board.

\clearpage

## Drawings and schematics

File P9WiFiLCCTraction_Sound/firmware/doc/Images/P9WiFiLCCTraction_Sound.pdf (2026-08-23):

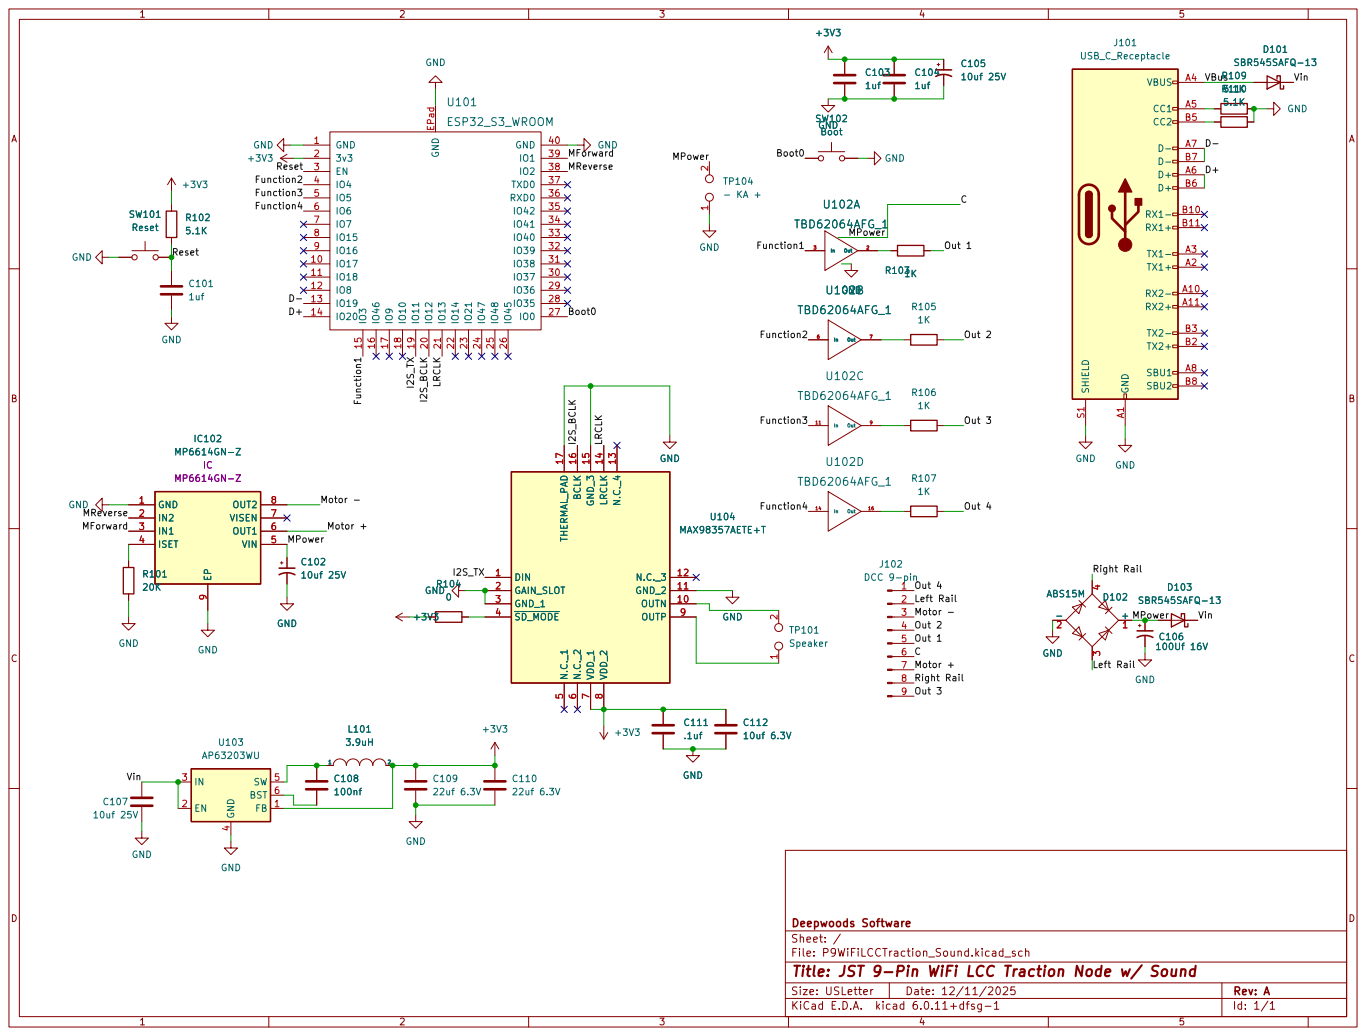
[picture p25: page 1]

File: P9WiFiLCCTraction_Sound.kicad_sch Sheet: / Deepwoods Software

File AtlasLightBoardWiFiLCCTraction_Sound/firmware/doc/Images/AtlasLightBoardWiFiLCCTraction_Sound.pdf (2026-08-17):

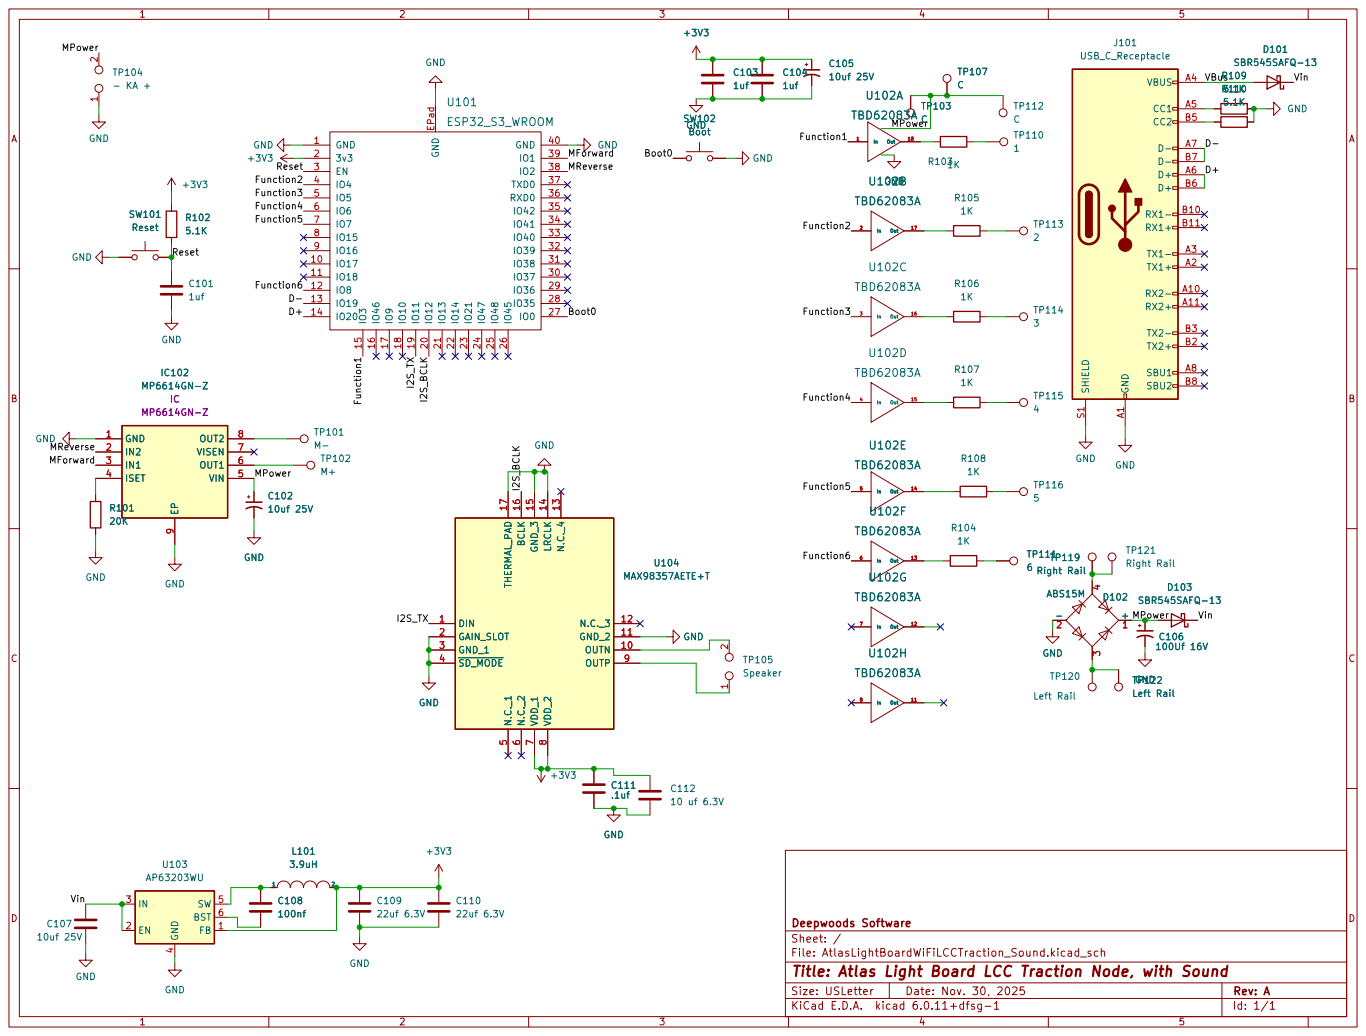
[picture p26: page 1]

File: AtlasLightBoardWiFiLCCTraction_Sound.kicad_sch Sheet: / Deepwoods Software

Id: 1/1 Title: Atlas Light Board LCC Traction Node, with Sound

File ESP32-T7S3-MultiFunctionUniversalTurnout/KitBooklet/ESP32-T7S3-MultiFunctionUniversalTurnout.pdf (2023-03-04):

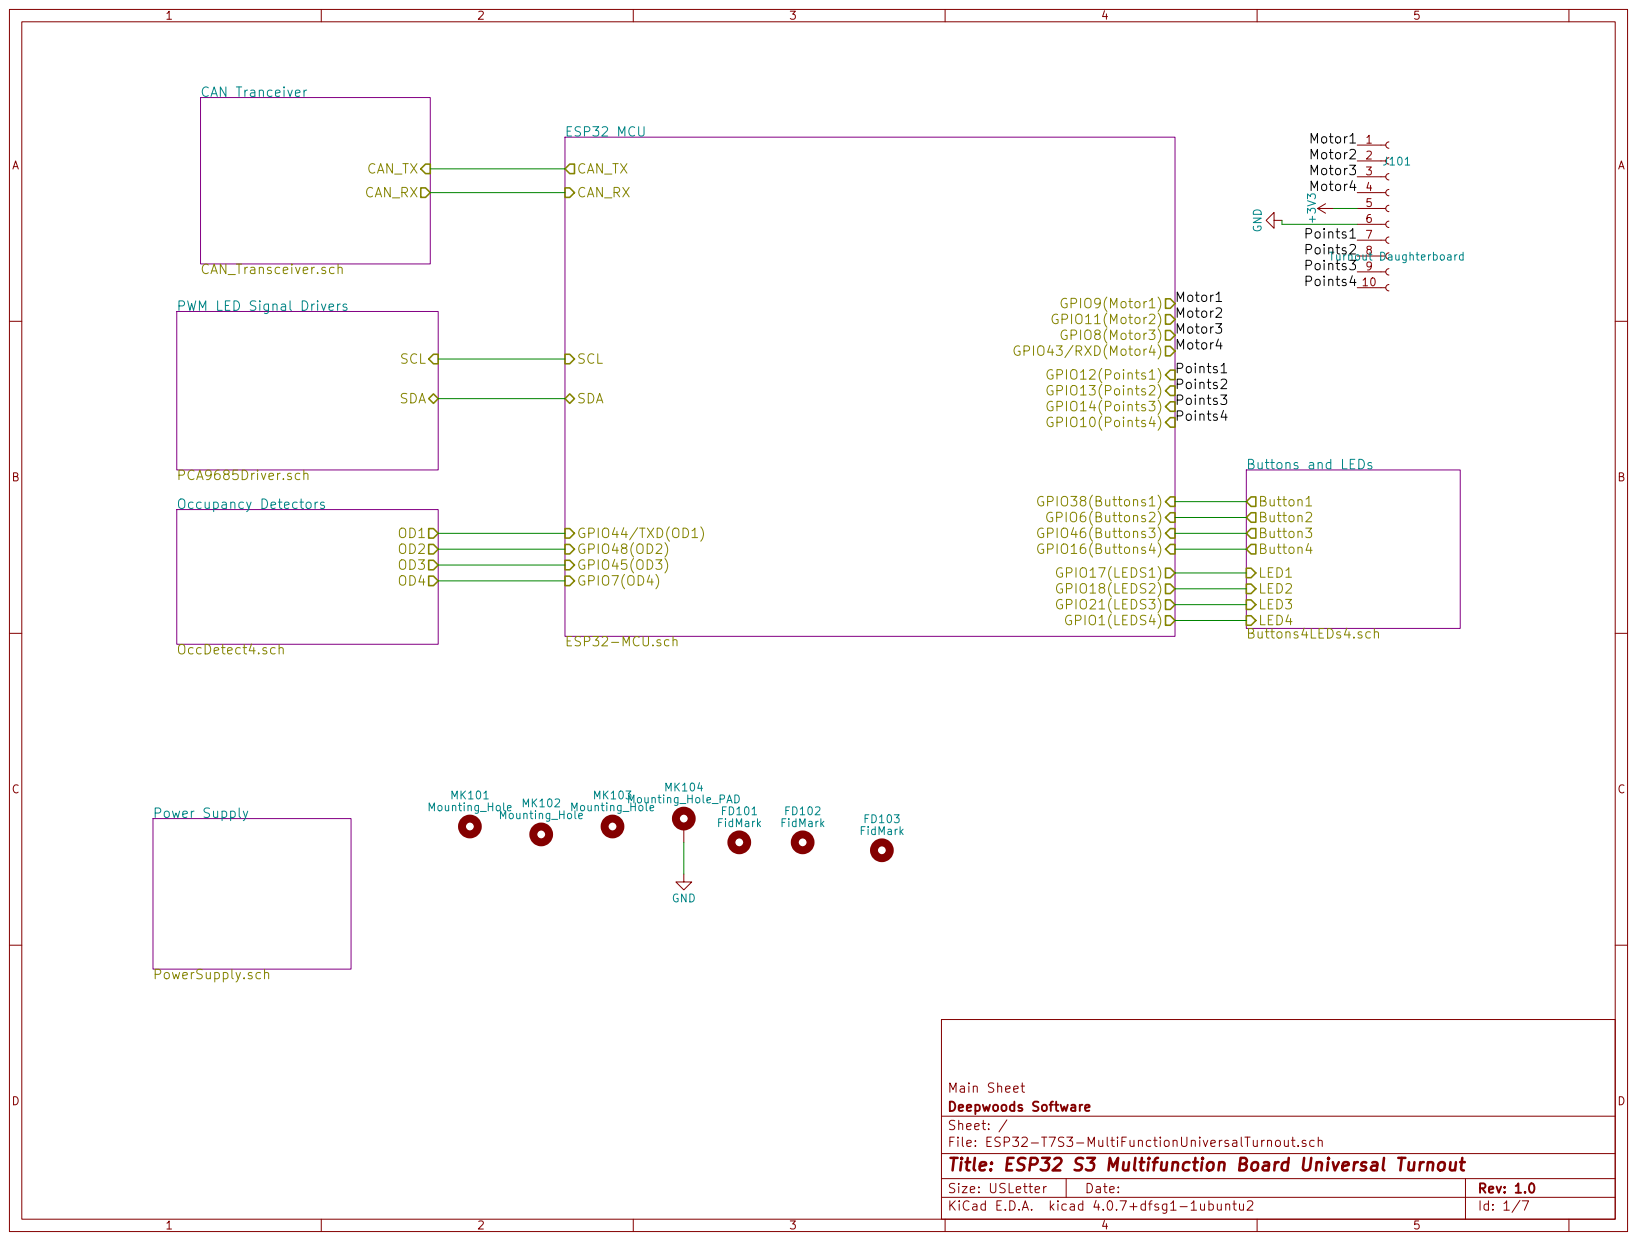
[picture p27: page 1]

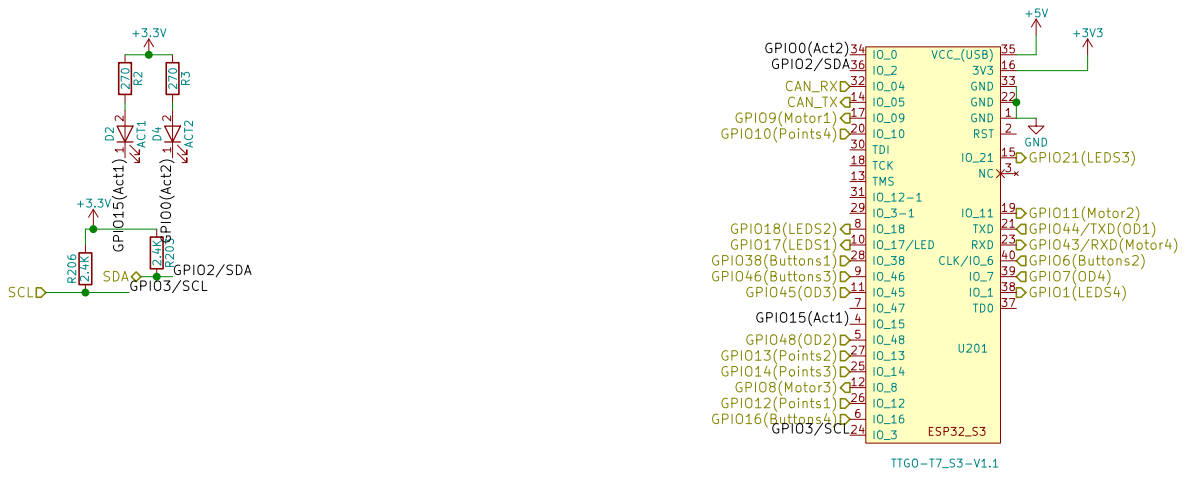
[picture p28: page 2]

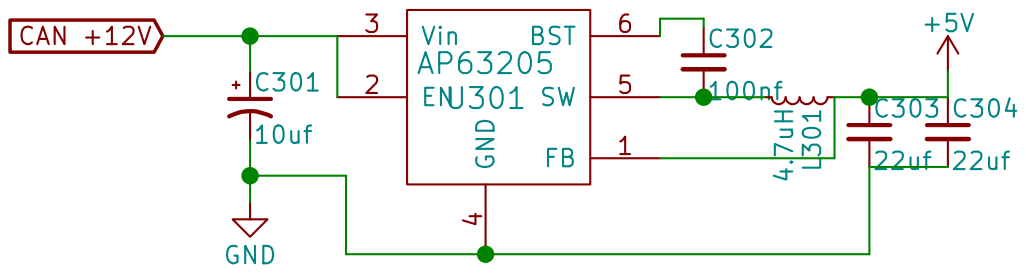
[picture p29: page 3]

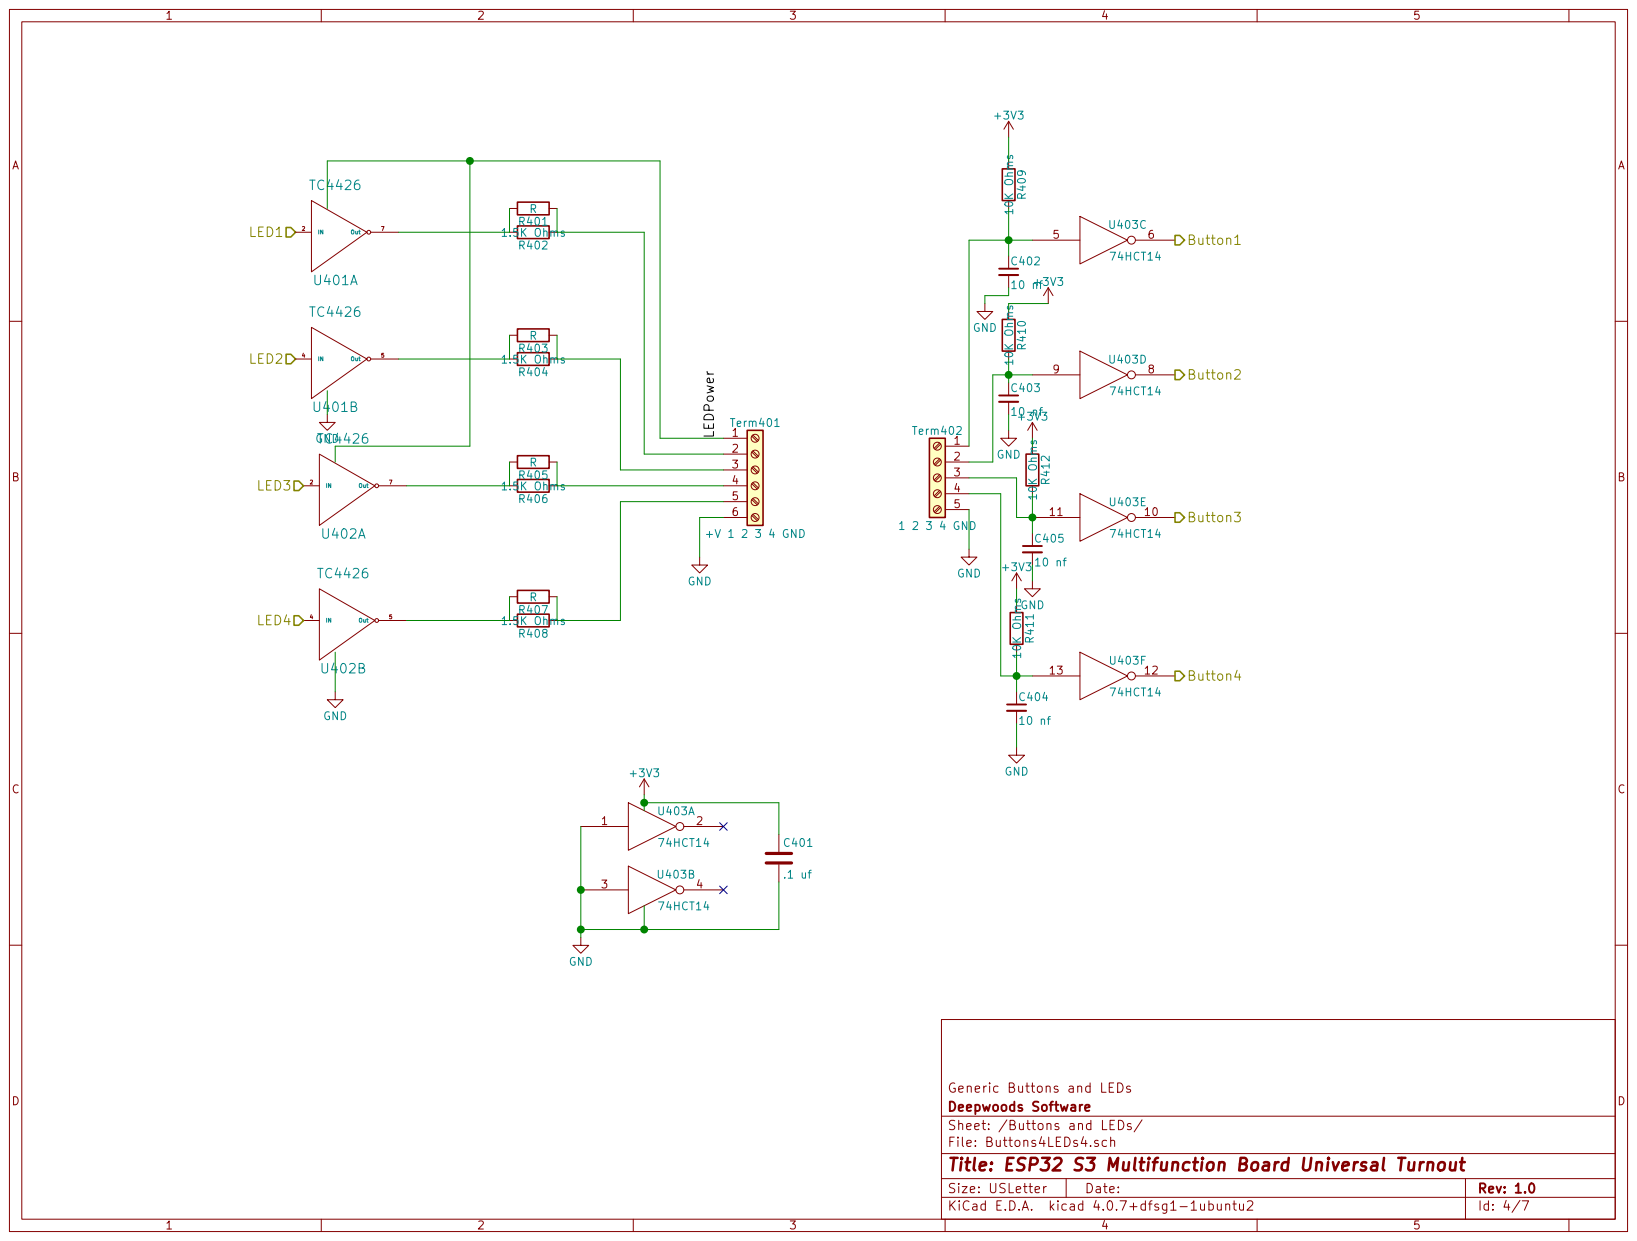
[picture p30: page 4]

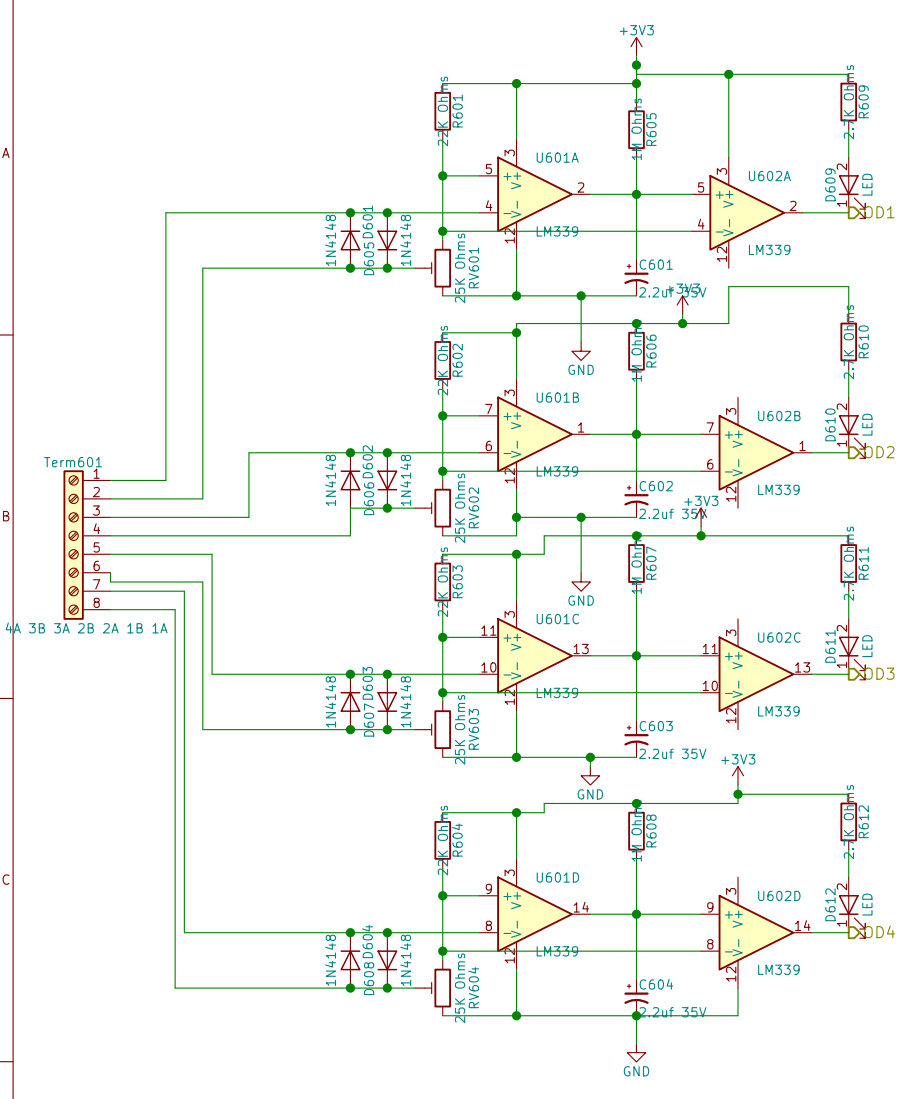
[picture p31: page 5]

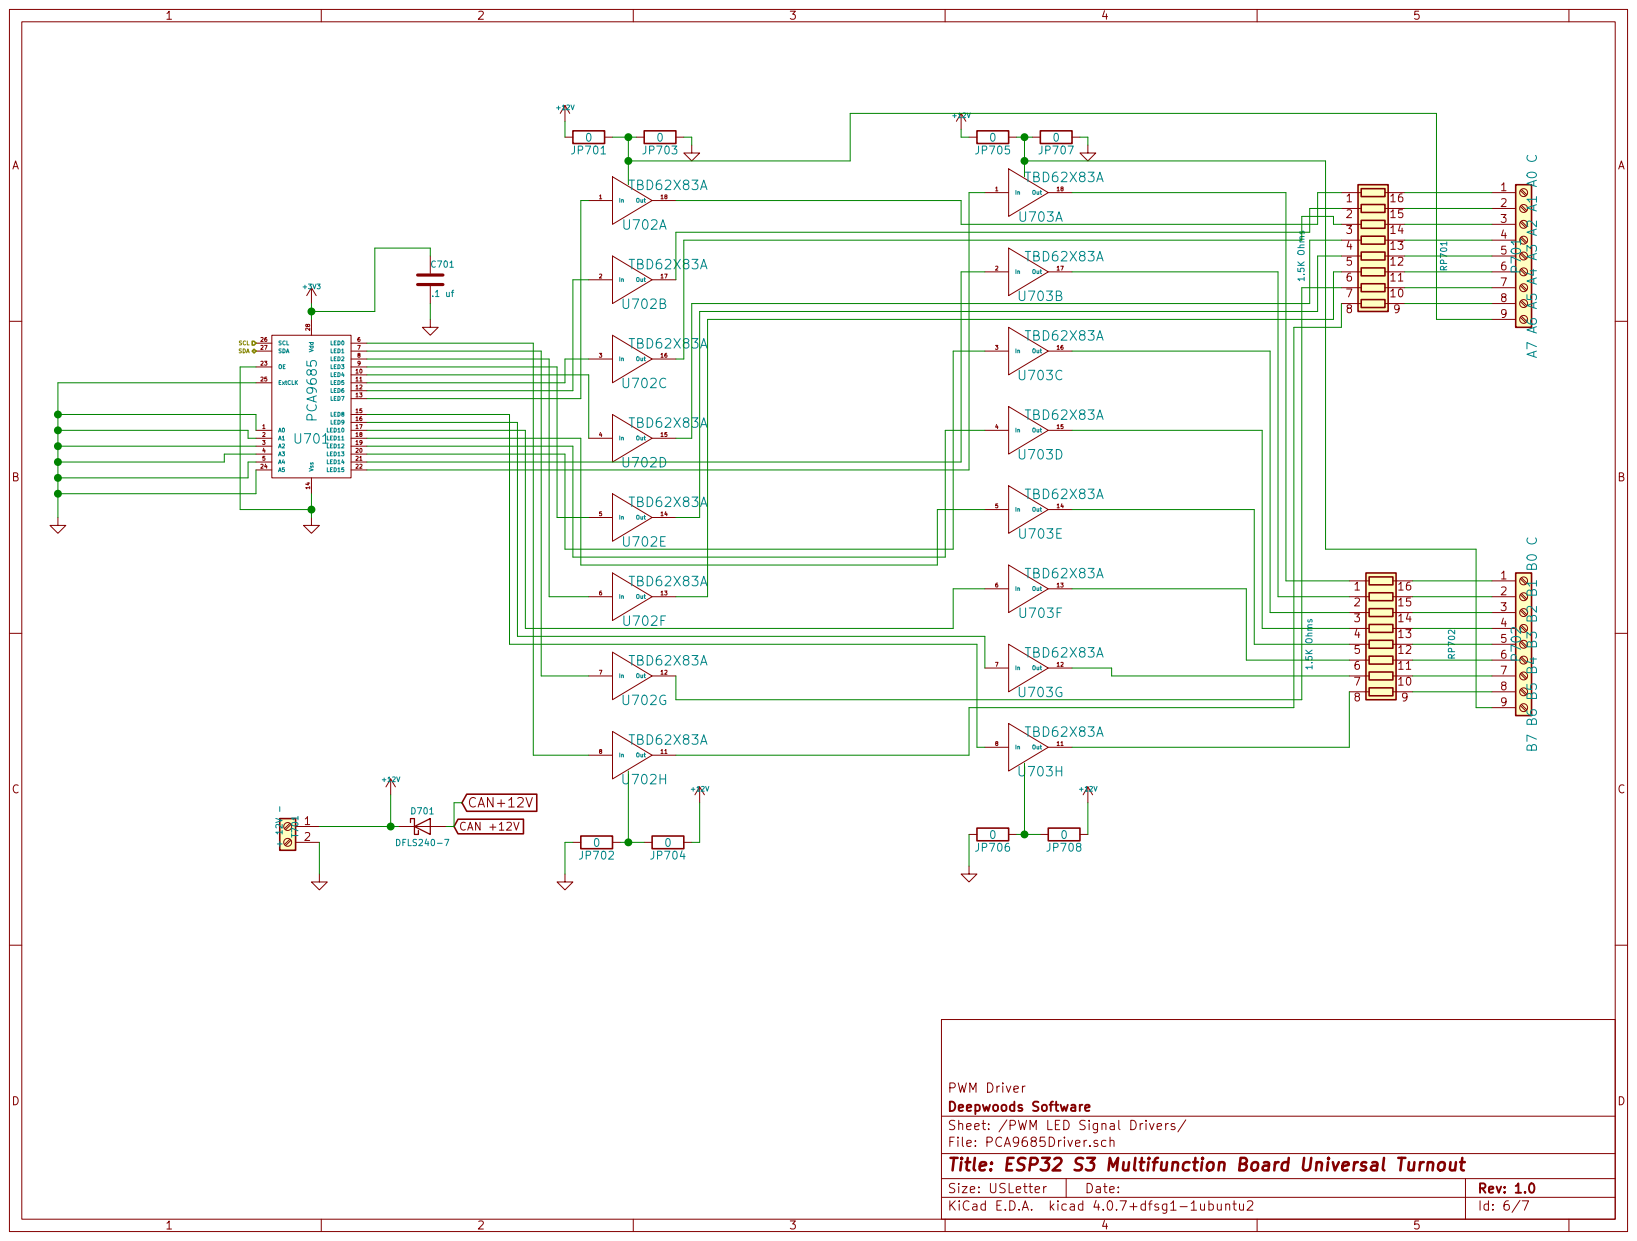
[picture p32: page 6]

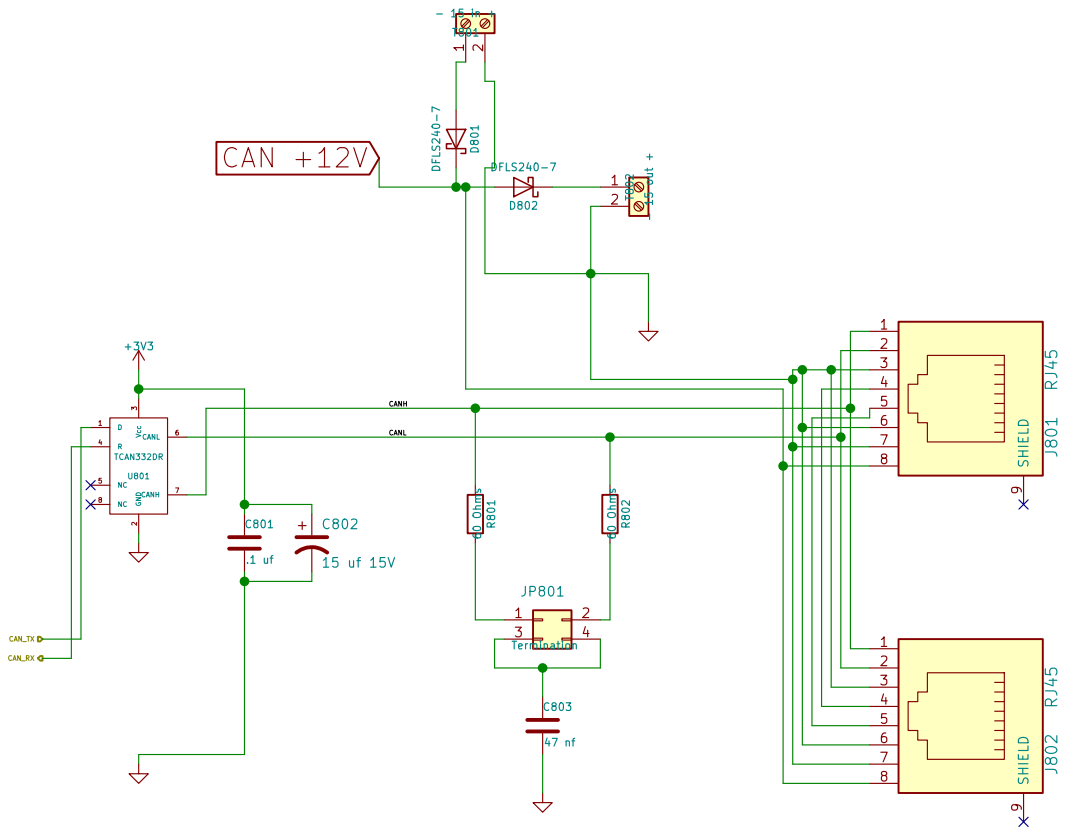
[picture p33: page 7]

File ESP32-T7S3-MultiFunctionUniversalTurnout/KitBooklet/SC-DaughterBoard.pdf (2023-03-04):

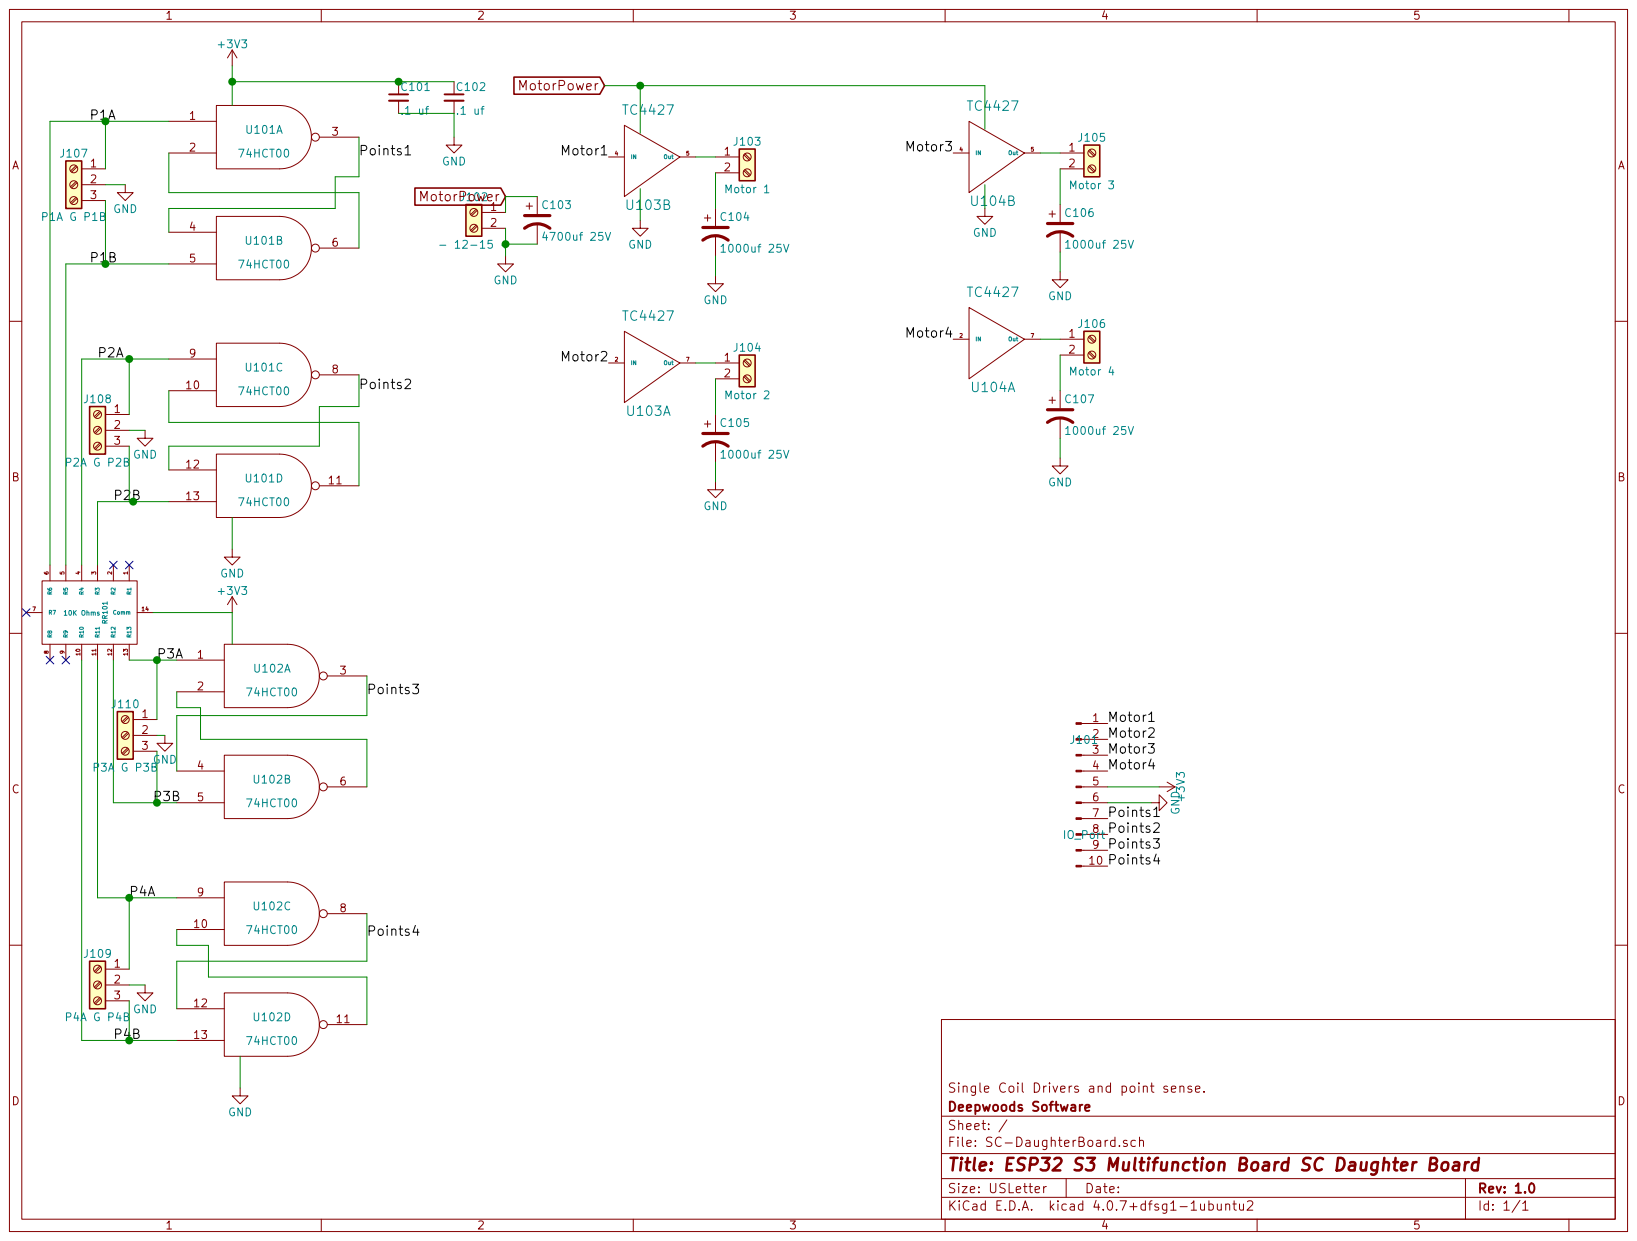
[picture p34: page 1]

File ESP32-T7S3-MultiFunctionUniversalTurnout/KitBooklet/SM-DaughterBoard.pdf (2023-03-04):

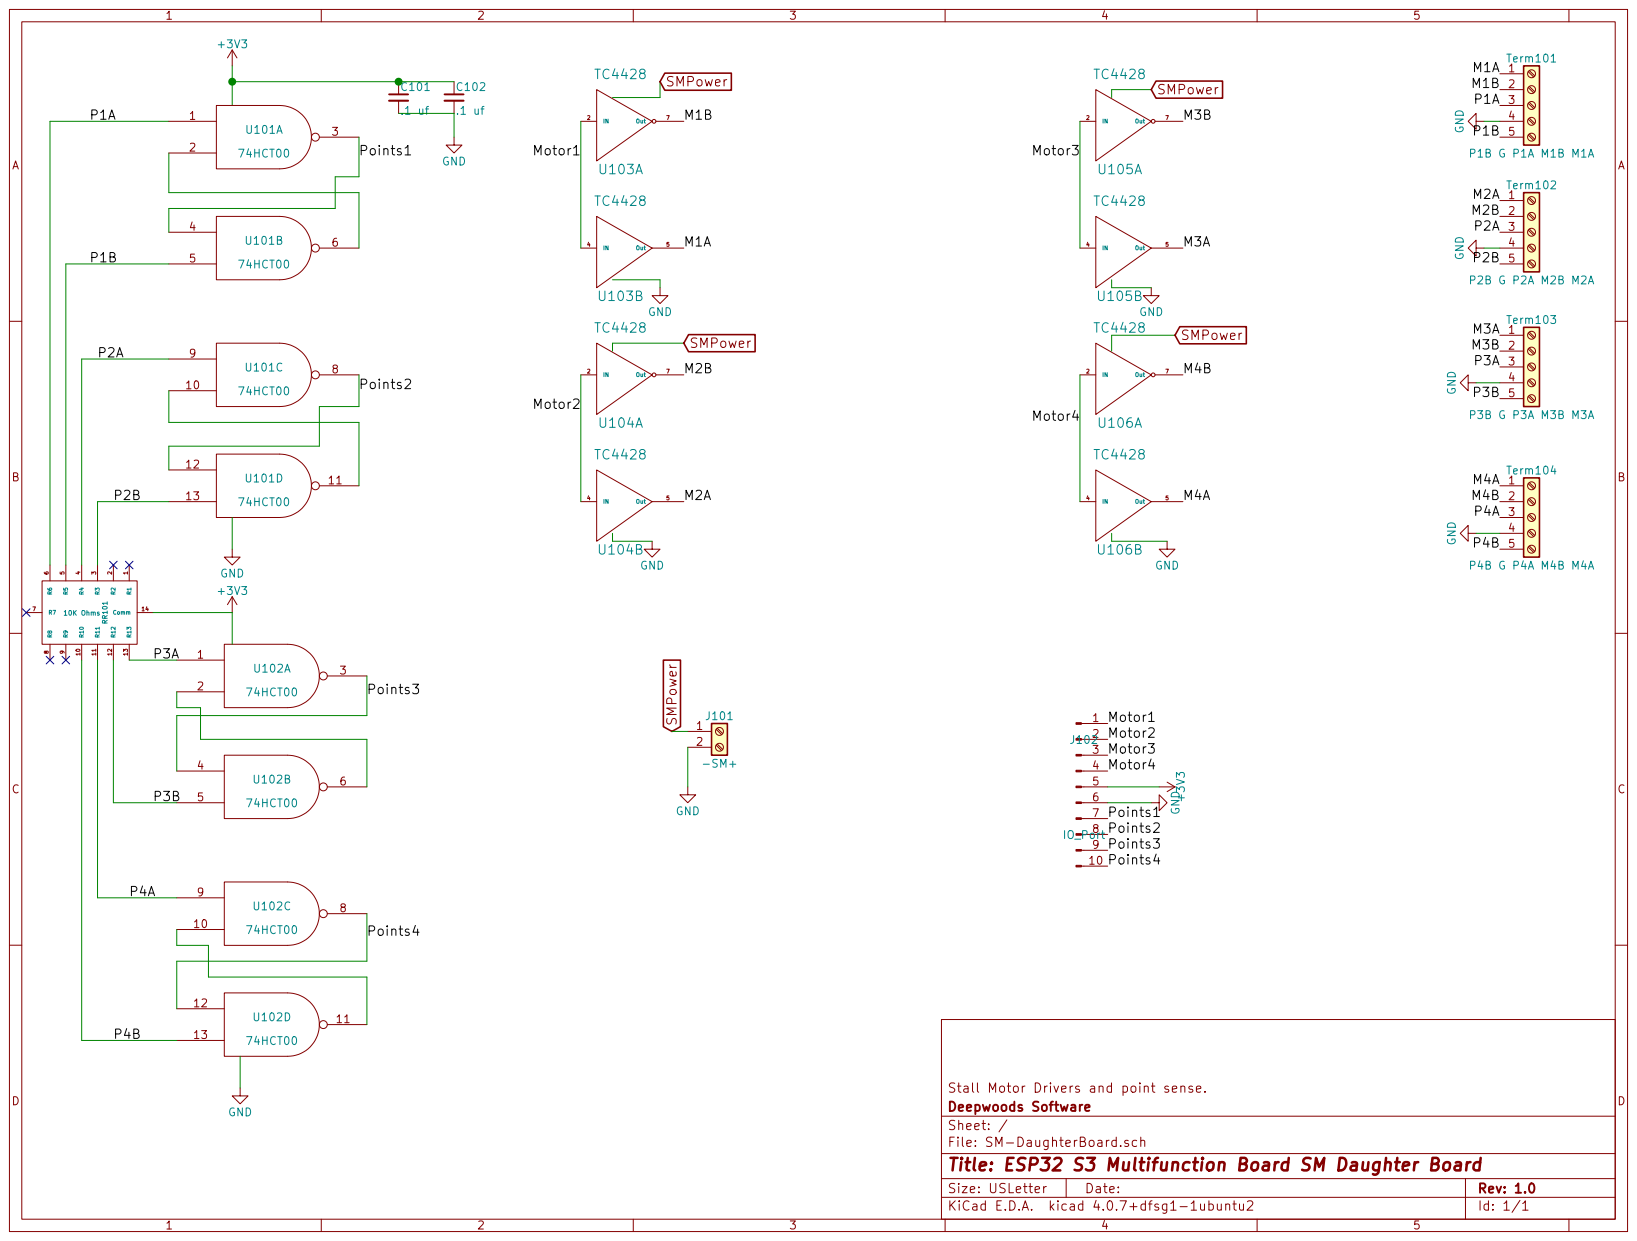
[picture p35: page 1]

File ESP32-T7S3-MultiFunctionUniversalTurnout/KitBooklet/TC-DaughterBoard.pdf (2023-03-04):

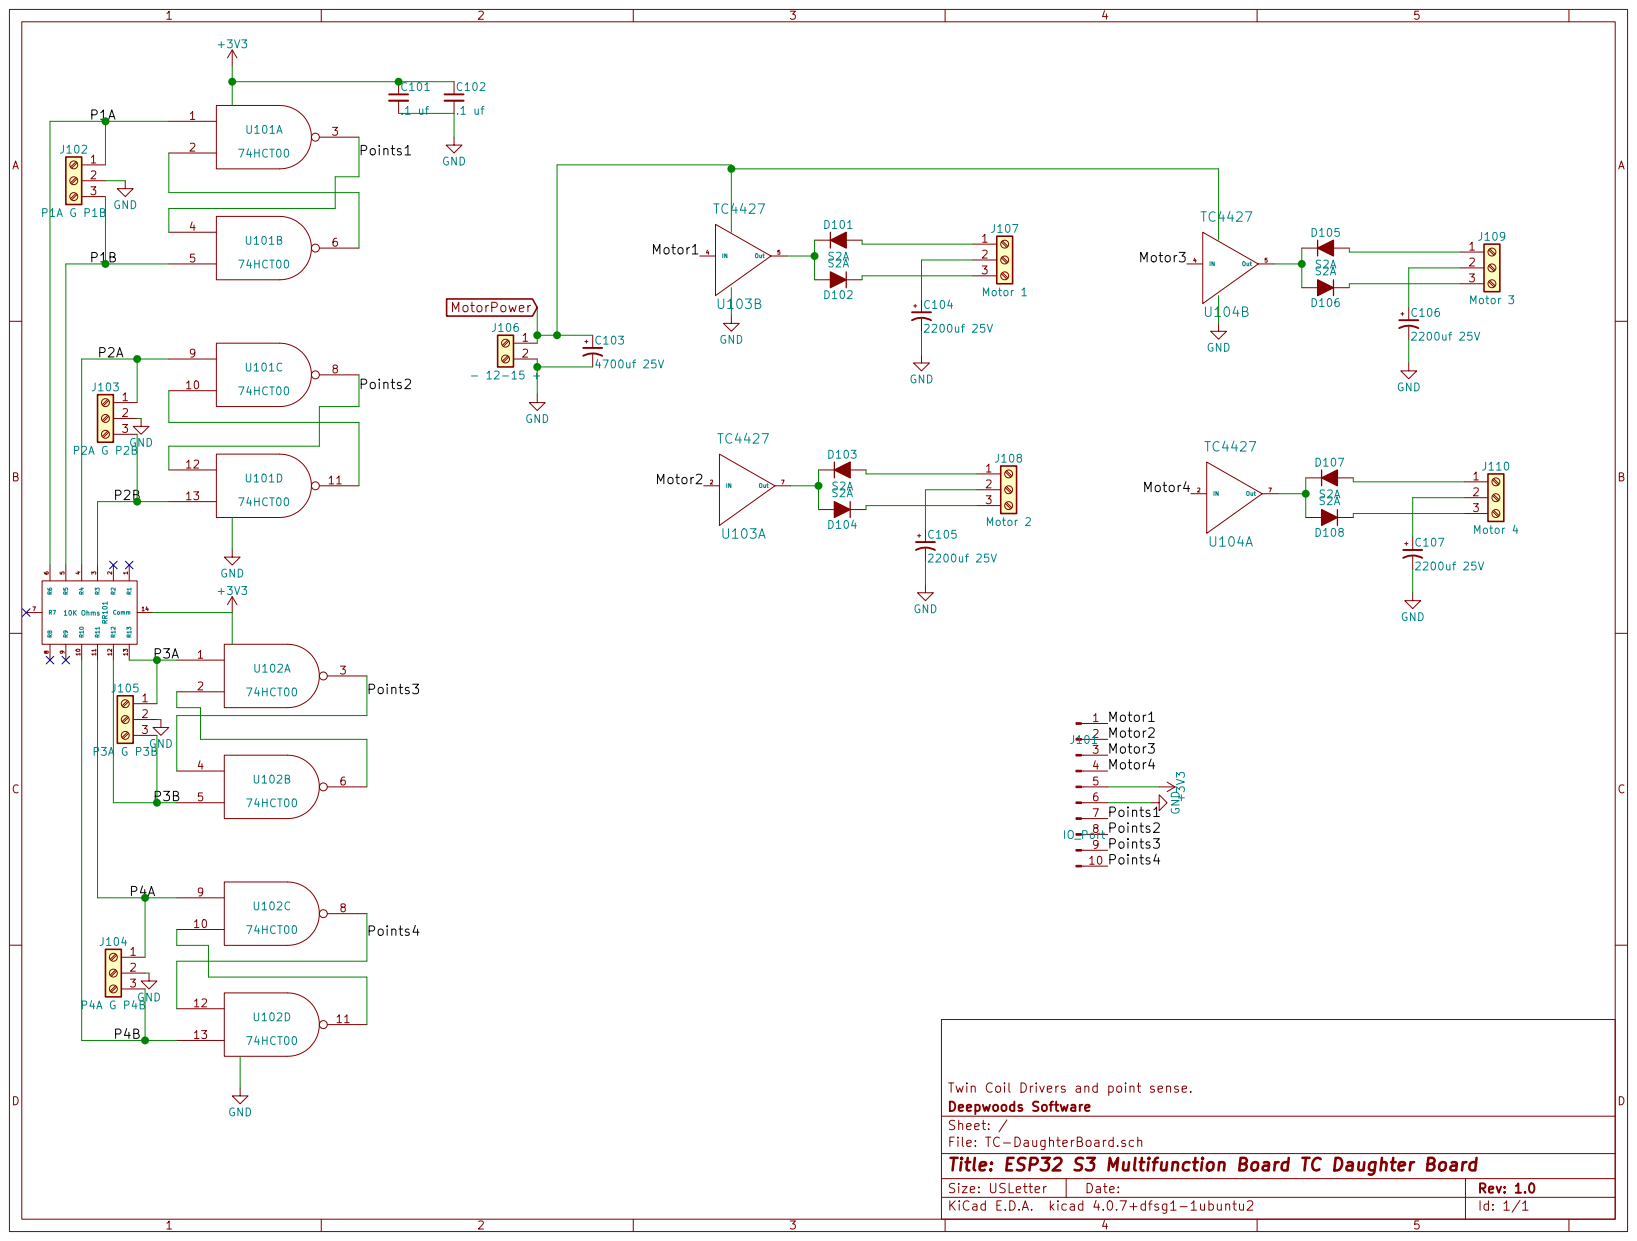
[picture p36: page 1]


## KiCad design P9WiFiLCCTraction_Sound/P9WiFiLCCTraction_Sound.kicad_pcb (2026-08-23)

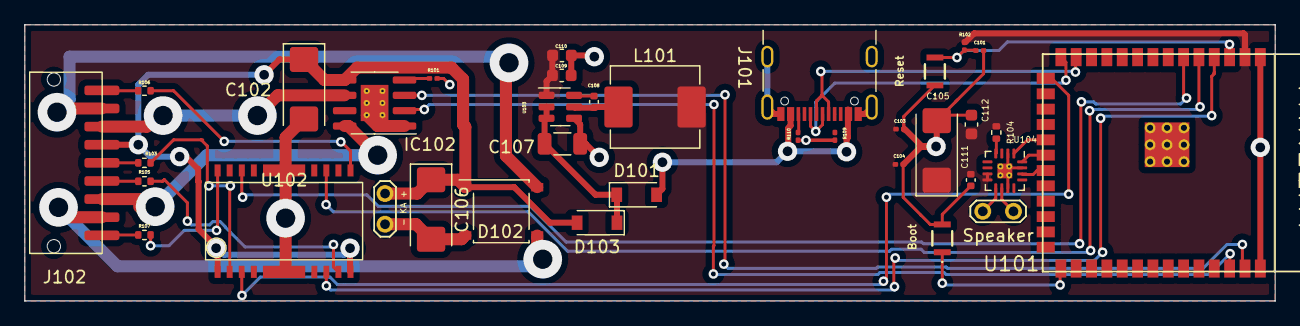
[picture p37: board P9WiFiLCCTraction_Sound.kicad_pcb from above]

Board: 2 copper layers, 103.5 x 22.9 mm, 36 parts (0 on the bottom side), 38 nets.

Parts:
C101, C103, C104: 1uf; C_0201_0603Metric
C102, C105: 10uf 25V; CP_EIA-6032-28_Kemet-C
C106: 100Uf 16V; CP_EIA-6032-28_Kemet-C
C107: 10uf 25V; C_1206_3216Metric
C108: 100nf; C_0402_1005Metric
C109, C110: 22uf 6.3V; C_0603_1608Metric
C111: .1uf; C_0402_1005Metric
C112: 10uf 6.3V; C_0603_1608Metric
D101, D103: SBR545SAFQ-13; D_SOD-123
D102: ABS15M; Diode_Bridge_Diotec_ABS
IC102: MP6614GN-Z; SOIC-8-1EP_3.9x4.9mm_P1.27mm_EP2.29x3mm_ThermalVias
J101: USB_C_Receptacle; USB_C_Receptacle_GCT_USB4105-xx-A_16P_TopMnt_Horizontal
J102: DCC 9-pin; JST_ZH_S9B-ZR-SM4A-TF_1x09-1MP_P1.50mm_Horizontal
L101: 3.9uH; L_Abracon_ASPI-0630LR
R101: 20K; R_0201_0603Metric
R102, R109, R110: 5.1K; R_0201_0603Metric
R103, R105, R106, R107: 1K; R_0402_1005Metric
R104: 0; R_0402_1005Metric
SW101: Reset; NanoT160AS
SW102: Boot; NanoT160AS
TP101: Speaker; TestPoint_2Pads_Pitch2.54mm_Drill0.8mm
TP104: - KA +; TestPoint_2Pads_Pitch2.54mm_Drill0.8mm
U101: ESP32_S3_WROOM; ESP32_S3_WROOM-1
U102: TBD62064AFG_1; HSOP16-P-300-1.00
U103: AP63203WU; TSOT-23-6
U104: MAX98357AETE+T; TQFN-16-1EP_3x3mm_P0.5mm_EP1.23x1.23mm_ThermalVias

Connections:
+3V3: C103.1, C104.1, C105.1, C109.1, C110.1, C111.1, C112.1, L101.2, R102.1, R104.1, U101.2 (3v3), U103.1 (FB), U104.7 (VDD_1), U104.8 (VDD_2)
/Boot0: SW102.1, U101.27 (IO0)
/D+: J101.A6 (D+), J101.B6 (D+), U101.14 (IO20)
/D-: J101.A7 (D-), J101.B7 (D-), U101.13 (IO19)
/Function1: U101.15 (IO3), U102.3 (In)
/Function2: U101.4 (IO4), U102.6 (In)
/Function3: U101.5 (IO5), U102.11 (In)
/Function4: U101.6 (IO6), U102.14 (In)
/I2S_BCLK: U101.20 (IO12), U104.16 (BCLK)
/I2S_TX: U101.19 (IO11), U104.1 (DIN)
/LRCLK: U101.21 (IO13), U104.14 (LRCLK)
/Left Rail: D102.3, J102.2
/MForward: IC102.3 (IN1), U101.39 (IO1)
/MReverse: IC102.2 (IN2), U101.38 (IO2)
/Motor +: IC102.6 (OUT1), J102.7
/Motor -: IC102.8 (OUT2), J102.3
/Out 1: J102.5, R103.1
/Out 2: J102.4, R105.1
/Out 3: J102.9, R106.1
/Out 4: J102.1, R107.1
/Reset: C101.1, R102.2, SW101.2, U101.3 (EN)
/Right Rail: D102.4, J102.8
/VBus: D101.2 (A), J101.A4 (VBUS), J101.A9 (VBUS), J101.B4 (VBUS), J101.B9 (VBUS)
/Vin: C107.1, D101.1 (K), D103.1 (K), U103.2 (EN), U103.3 (IN)
GND: C101.2, C102.2, C103.2, C104.2, C105.2, C106.2, C107.2, C109.2, C110.2, C111.2, C112.2, D102.2 (-), IC102.1 (GND), IC102.9 (EP), J101.A1 (GND), J101.A12 (GND), J101.B1 (GND), J101.B12 (GND), J101.S1 (SHIELD), R101.2, R109.2, R110.2, SW101.1, SW102.2, TP104.1, U101.1 (GND), U101.40 (GND), U101.EPad (GND), U102.FIN (GND), U103.4 (GND), U104.2 (GAIN_SLOT), U104.3 (GND_1), U104.11 (GND_2), U104.15 (GND_3), U104.17 (THERMAL_PAD)
unnamed: C108.1, L101.1, U103.5 (SW)
unnamed: C108.2, U103.6 (BST)
unnamed: IC102.4 (ISET), R101.1
unnamed: J101.A5 (CC1), R109.1
unnamed: J101.B5 (CC2), R110.1
unnamed: R103.2, U102.2 (Out)
unnamed: R104.2, U104.4 (~SD_MODE)
unnamed: R105.2, U102.7 (Out)
unnamed: R106.2, U102.9 (Out)
unnamed: R107.2, U102.16 (Out)
unnamed: TP101.1, U104.9 (OUTP)
unnamed: TP101.2, U104.10 (OUTN)
OC: C102.1, C106.1, D102.1 (+), D103.2 (A), IC102.5 (VIN), J102.6, TP104.2, U102.1 (OC), U102.8 (OC)

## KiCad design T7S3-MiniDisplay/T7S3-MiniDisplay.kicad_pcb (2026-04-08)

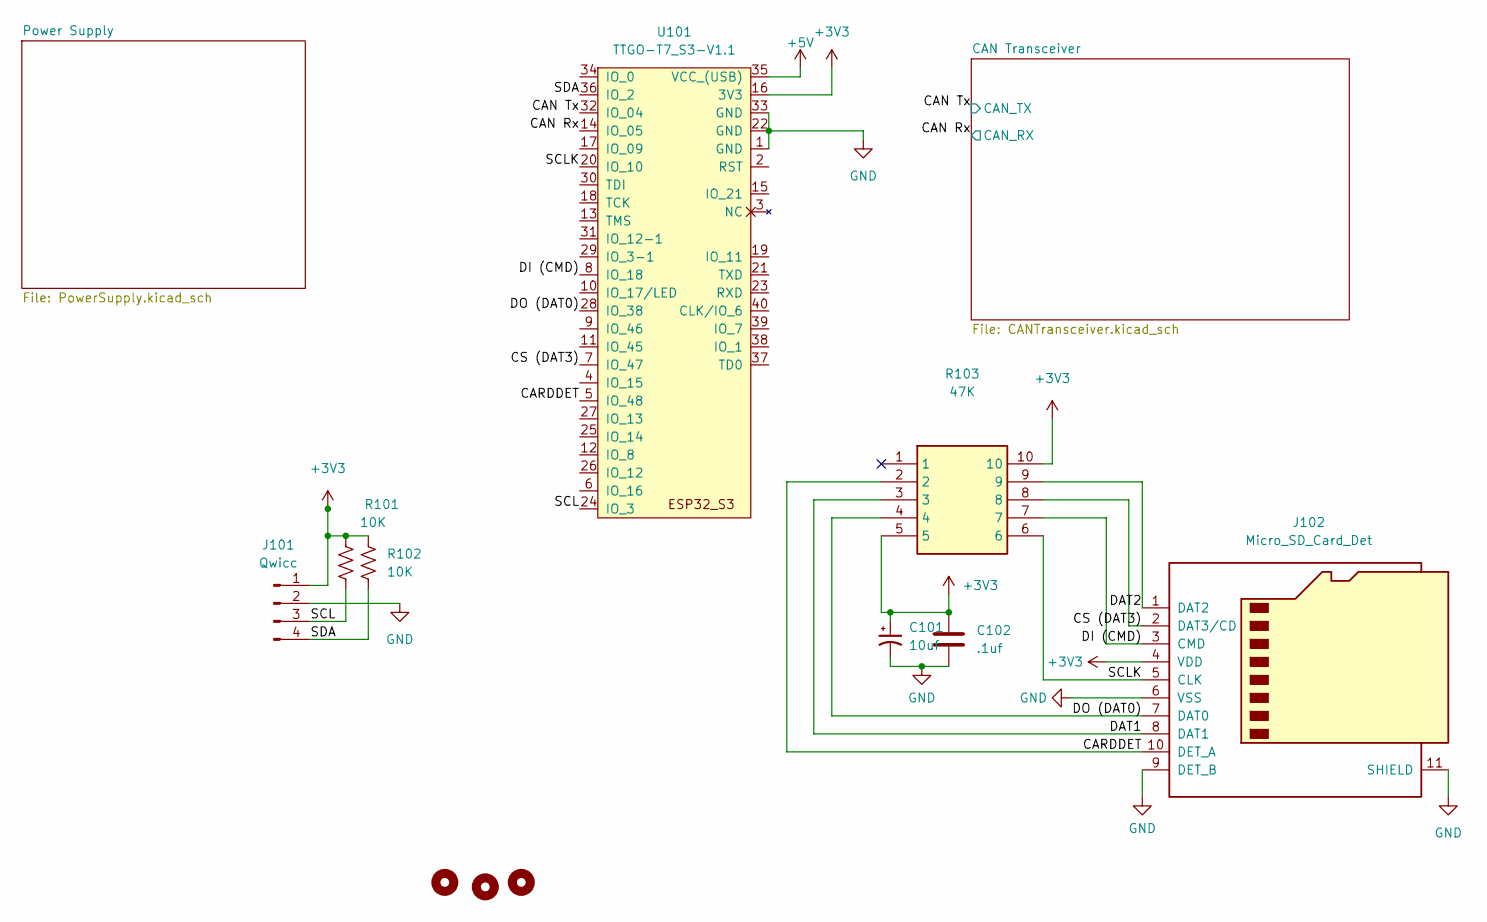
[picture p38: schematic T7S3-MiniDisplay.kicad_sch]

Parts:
C101: 10uf; CP_Elec_4x5.7; Mouser Part Number 667-EEE-HB1C100R
C102: .1uf; C_0603_1608Metric; Mouser Part Number 80-C0603C104K5R7411
H101, H102, H103: MountingHole; MountingHole_2.5mm
J101: Qwicc; JST_PH_S4B-PH-SM4-TB_1x04-1MP_P2.00mm_Horizontal; MPN S4B-PH-SM4-TB(LF)(SN); Mouser Part Number 306-S4BPHSM4TBLFSN
J102: Micro_SD_Card_Det; microSD_HC_Hirose_DM3D-SF; Mouser Part Number 798-DM3D-SF
R101, R102: 10K; R_0201_0603Metric; Mouser Part Number 603-RE0603DRE0710KL
R103: 47K; YC158TJR074K7L; Mouser Part Number 603-YC158TJR-0747KL
U101: TTGO-T7_S3-V1.1; ESP32_mini

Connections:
+3V3: C101.1, C102.1, J101.1, J102.4 (VDD), R101.1, R102.1, R103.5, R103.10, U101.16 (3V3); also elsewhere on the board
+5V: U101.35 (VCC_(USB)); also elsewhere on the board
/CAN Rx: U101.14 (IO_05); also elsewhere on the board
/CAN Tx: U101.32 (IO_04); also elsewhere on the board
/CARDDET: J102.10 (DET_A), R103.2, U101.5 (IO_48)
/CS (DAT3): J102.2 (DAT3/CD), R103.8, U101.7 (IO_47)
/DAT1: J102.8 (DAT1), R103.3
/DAT2: J102.1 (DAT2), R103.9
/DI (CMD): J102.3 (CMD), R103.7, U101.8 (IO_18)
/DO (DAT0): J102.7 (DAT0), R103.4, U101.28 (IO_38)
/SCL: J101.3, R101.2, U101.24 (IO_3)
/SCLK: J102.5 (CLK), R103.6, U101.20 (IO_10)
/SDA: J101.4, R102.2, U101.36 (IO_2)
GND: C101.2, C102.2, J101.2, J102.6 (VSS), J102.9 (DET_B), J102.11 (SHIELD), U101.1 (GND), U101.22 (GND), U101.33 (GND); also elsewhere on the board

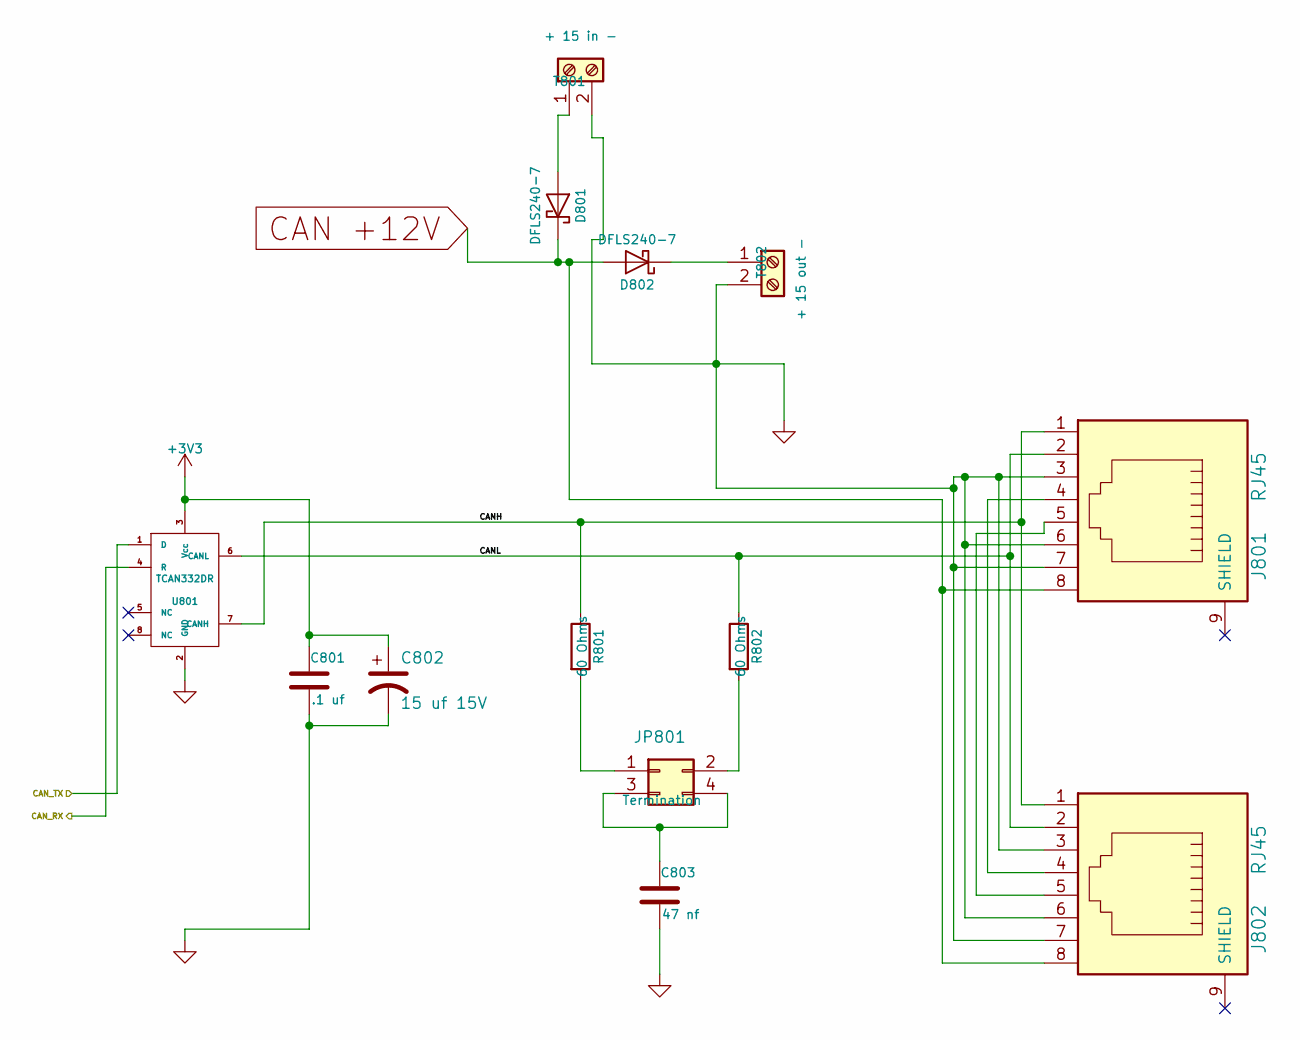
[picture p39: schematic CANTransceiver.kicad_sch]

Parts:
C801: .1 uf; C_0603_1608Metric; Mouser Part Number 80-C0603C104K5R7411
C802: 15 uf 15V; CP_Elec_4x5.7; Mouser Part Number 710-865080340002
C803: 47 nf; C_0603_1608Metric; Mouser Part Number 710-885012206093
D801, D802: DFLS240-7; D_PowerDI-123; Mouser Part Number 621-DFLS240-7
J801, J802: RJ45; RJ45_8N-S; Mouser Part Number 710-615008144221
JP801: Termination; PinHeader_2x02_P2.54mm_Vertical; Mouser Part Number 649-67997-404HLF
R801, R802: 60 Ohms; R_1206_3216Metric; Mouser Part Number 71-CRCW120660R0KNAIF
T801: + 15 in -; TerminalBlock_TE_282834-2_1x02_P2.54mm_Horizontal; Mouser Part Number 651-1725656
T802: + 15 out -; TerminalBlock_TE_282834-2_1x02_P2.54mm_Horizontal; Mouser Part Number 651-1725656
U801: TCAN332DR; SOIC-8_3.9x4.9mm_P1.27mm; Mouser Part Number 595-TCAN332DR

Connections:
+3V3: C801.1, C802.1, U801.3 (Vcc); also elsewhere on the board
/CAN Rx: U801.4 (R); also elsewhere on the board
/CAN Transceiver/CANH: J801.1, J802.1, R801.1, U801.7 (CANH)
/CAN Transceiver/CANL: J801.2, J802.2, R802.1, U801.6 (CANL)
/CAN Tx: U801.1 (D); also elsewhere on the board
CAN +12V: D801.1 (K), D802.2 (A), J801.8, J802.8; also elsewhere on the board
GND: C801.2, C802.2, C803.2, J801.3, J801.6, J801.7, J802.3, J802.6, J802.7, T801.2, T802.2, U801.2 (GND); also elsewhere on the board
unnamed: C803.1, JP801.3, JP801.4
unnamed: D801.2 (A), T801.1
unnamed: D802.1 (K), T802.1
unnamed: J801.4, J802.4
unnamed: J801.5, J802.5
unnamed: JP801.1, R801.2
unnamed: JP801.2, R802.2

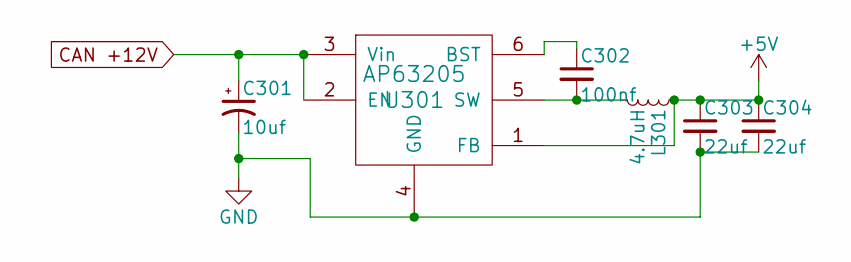
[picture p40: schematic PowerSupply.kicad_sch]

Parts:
C301: 10uf; CP_Elec_5x5.3; Mouser Part Number 667-EEE-HB1C100R
C302: 100nf; C_0603_1608Metric; Mouser Part Number 710-885012206020
C303, C304: 22uf; C_0603_1608Metric; Mouser Part Number 603-CC0603MRX6S5B226
L301: 4.7uH; L_7.3x7.3_H4.5; Mouser Part Number 81-B1047AS-4R7N=P3
U301: AP63205; TSOT-23-6; Mouser Part Number 621-AP63205WU-7

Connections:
+5V: C303.1, C304.1, L301.1, U301.1 (FB); also elsewhere on the board
CAN +12V: C301.1, U301.2 (EN), U301.3 (Vin); also elsewhere on the board
GND: C301.2, C303.2, C304.2, U301.4 (GND); also elsewhere on the board
unnamed: C302.1, U301.6 (BST)
unnamed: C302.2, L301.2, U301.5 (SW)

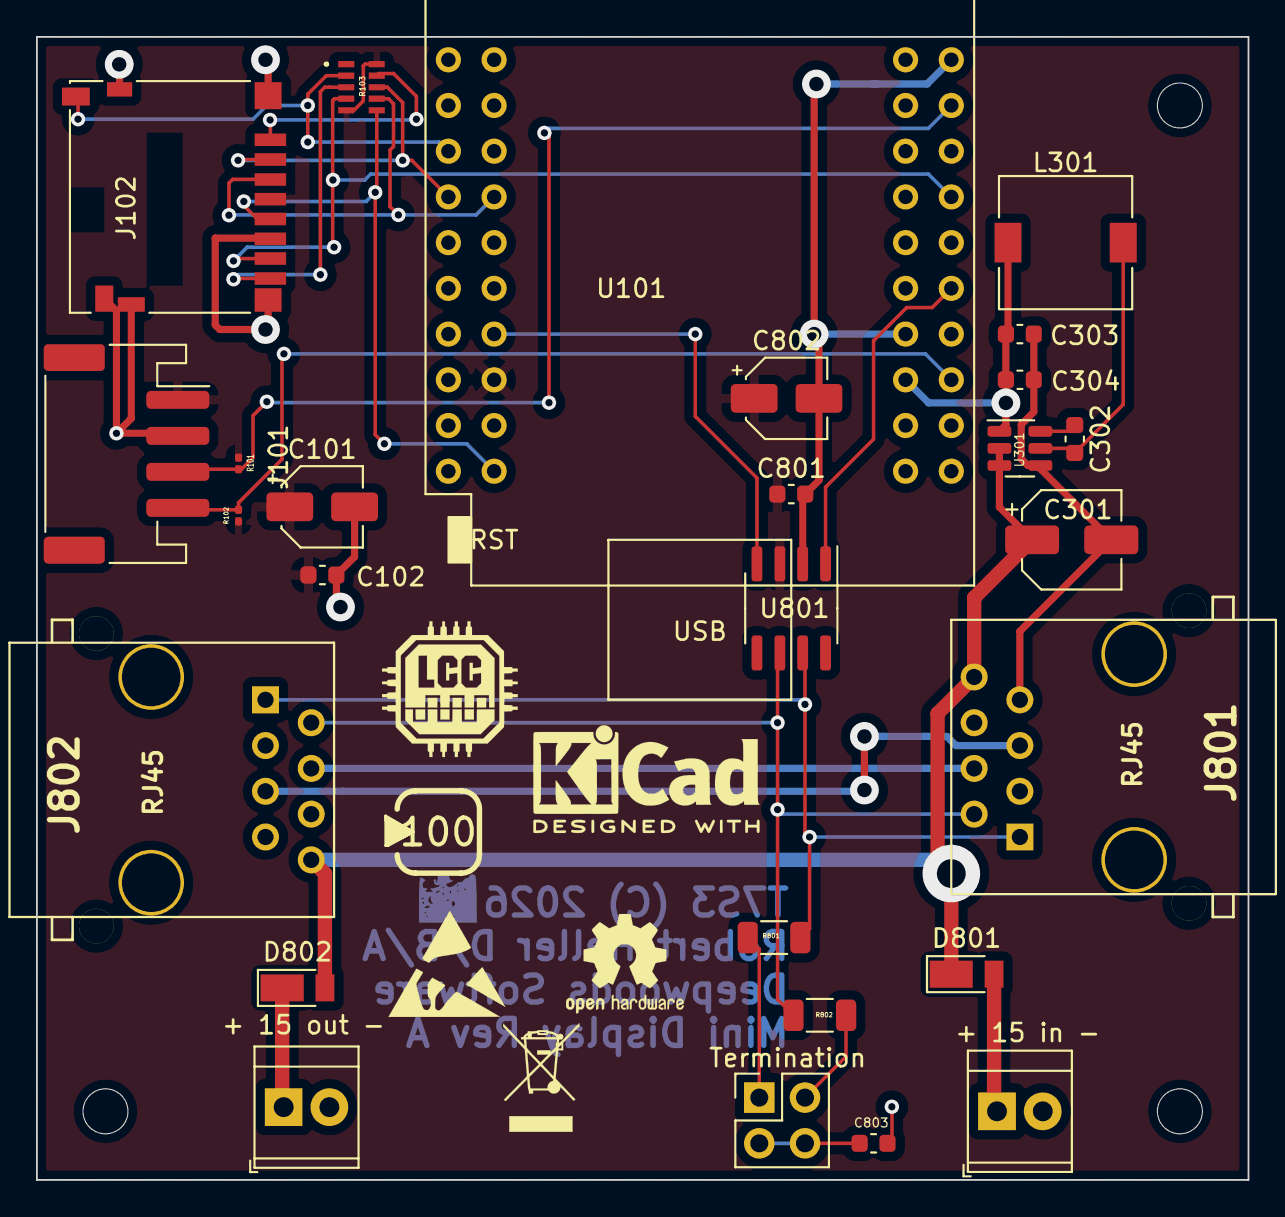
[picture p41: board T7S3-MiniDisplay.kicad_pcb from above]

Board: 2 copper layers, 67.3 x 63.5 mm, 30 parts (0 on the bottom side), 26 nets.

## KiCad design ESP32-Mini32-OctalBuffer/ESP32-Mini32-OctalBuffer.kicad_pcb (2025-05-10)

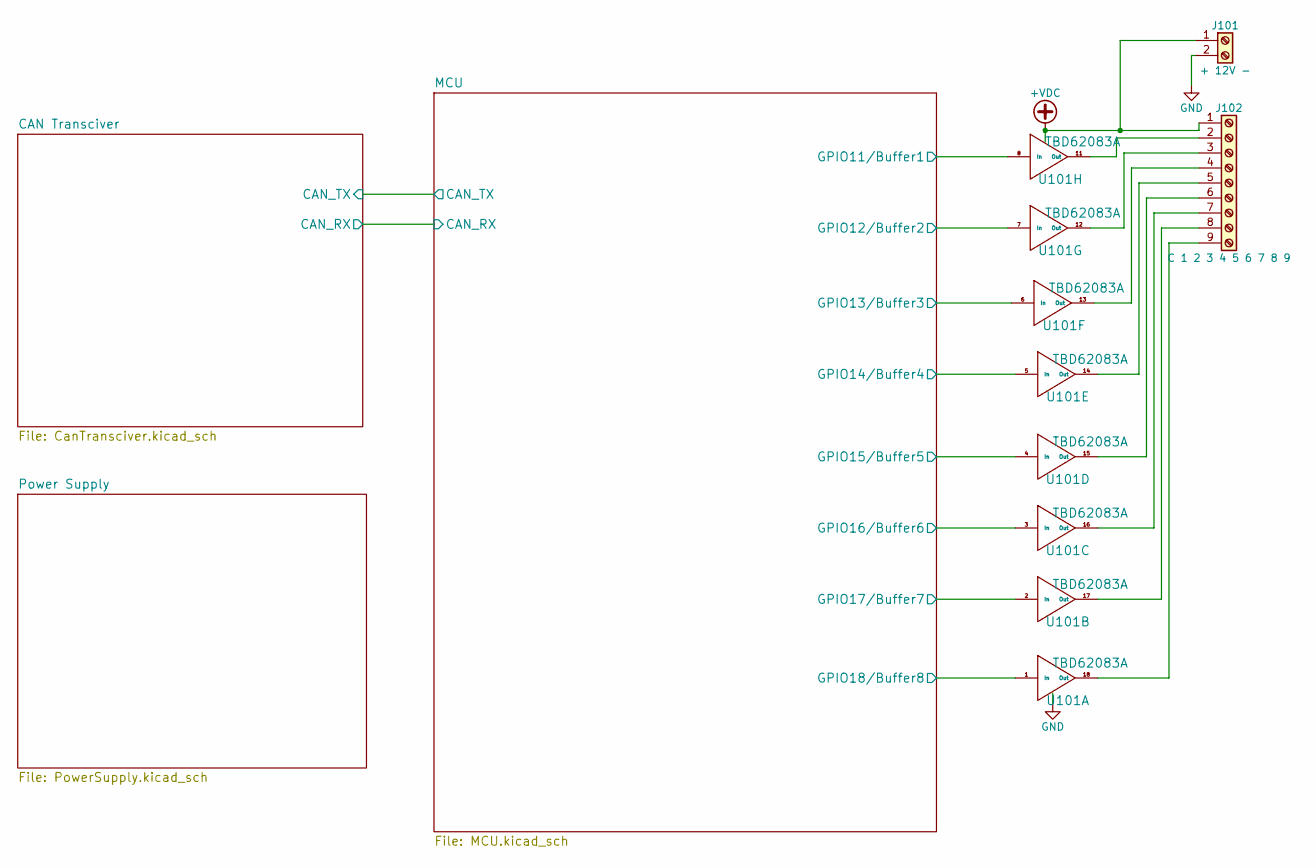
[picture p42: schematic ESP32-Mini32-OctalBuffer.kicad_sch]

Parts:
J101: + 12V -; TerminalBlock_Pheonix_PT-3.5mm_2pol
J102: C 1 2 3 4 5 6 7 8 9; TerminalBlock_Pheonix_PT-3.5mm_9pol
U101: TBD62083A; SOIC-18W_7.5x11.6mm_Pitch1.27mm; Mouser Part Number 757-TBD62083AFGEL

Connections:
+VDC: J101.1, J102.1, U101.10 (OC)
/MCU/GPIO11/Buffer1: U101.8 (In); also elsewhere on the board
/MCU/GPIO12/Buffer2: U101.7 (In); also elsewhere on the board
/MCU/GPIO13/Buffer3: U101.6 (In); also elsewhere on the board
/MCU/GPIO14/Buffer4: U101.5 (In); also elsewhere on the board
/MCU/GPIO15/Buffer5: U101.4 (In); also elsewhere on the board
/MCU/GPIO16/Buffer6: U101.3 (In); also elsewhere on the board
/MCU/GPIO17/Buffer7: U101.2 (In); also elsewhere on the board
/MCU/GPIO18/Buffer8: U101.1 (In); also elsewhere on the board
GND: J101.2, U101.9 (IC); also elsewhere on the board
unnamed: J102.2, U101.11 (Out)
unnamed: J102.3, U101.12 (Out)
unnamed: J102.4, U101.13 (Out)
unnamed: J102.5, U101.14 (Out)
unnamed: J102.6, U101.15 (Out)
unnamed: J102.7, U101.16 (Out)
unnamed: J102.8, U101.17 (Out)
unnamed: J102.9, U101.18 (Out)

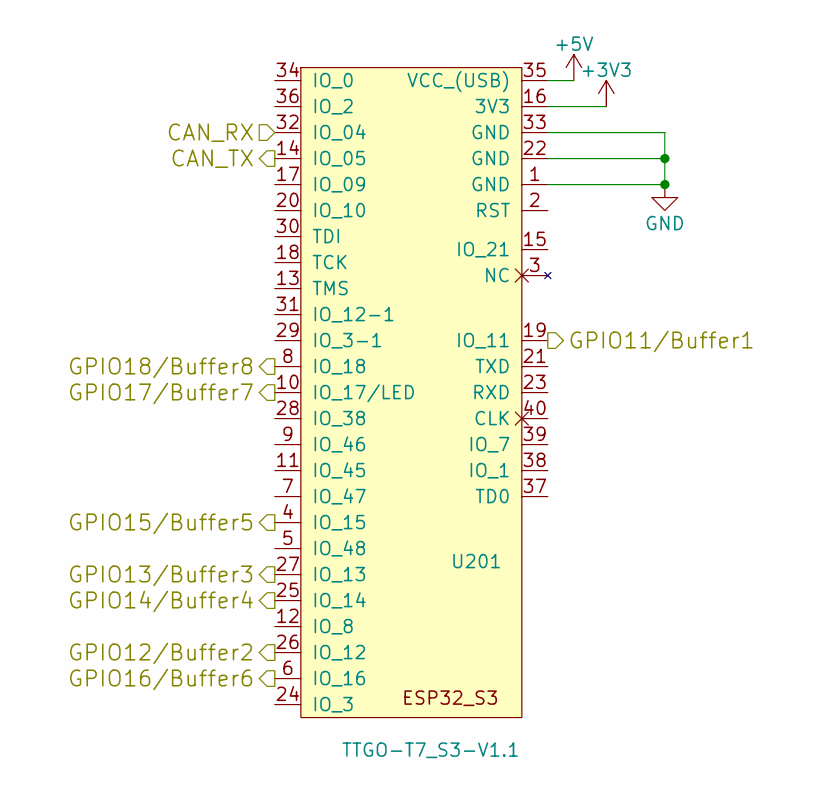
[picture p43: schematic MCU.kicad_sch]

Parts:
U201: TTGO-T7_S3-V1.1; ESP32_mini

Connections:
+3V3: U201.16 (3V3); also elsewhere on the board
+5V: U201.35 (VCC_(USB)); also elsewhere on the board
/CAN Transciver/CAN_RX: U201.32 (IO_04); also elsewhere on the board
/CAN Transciver/CAN_TX: U201.14 (IO_05); also elsewhere on the board
/MCU/GPIO11/Buffer1: U201.19 (IO_11); also elsewhere on the board
/MCU/GPIO12/Buffer2: U201.26 (IO_12); also elsewhere on the board
/MCU/GPIO13/Buffer3: U201.27 (IO_13); also elsewhere on the board
/MCU/GPIO14/Buffer4: U201.25 (IO_14); also elsewhere on the board
/MCU/GPIO15/Buffer5: U201.4 (IO_15); also elsewhere on the board
/MCU/GPIO16/Buffer6: U201.6 (IO_16); also elsewhere on the board
/MCU/GPIO17/Buffer7: U201.10 (IO_17/LED); also elsewhere on the board
/MCU/GPIO18/Buffer8: U201.8 (IO_18); also elsewhere on the board
GND: U201.1 (GND), U201.22 (GND), U201.33 (GND); also elsewhere on the board

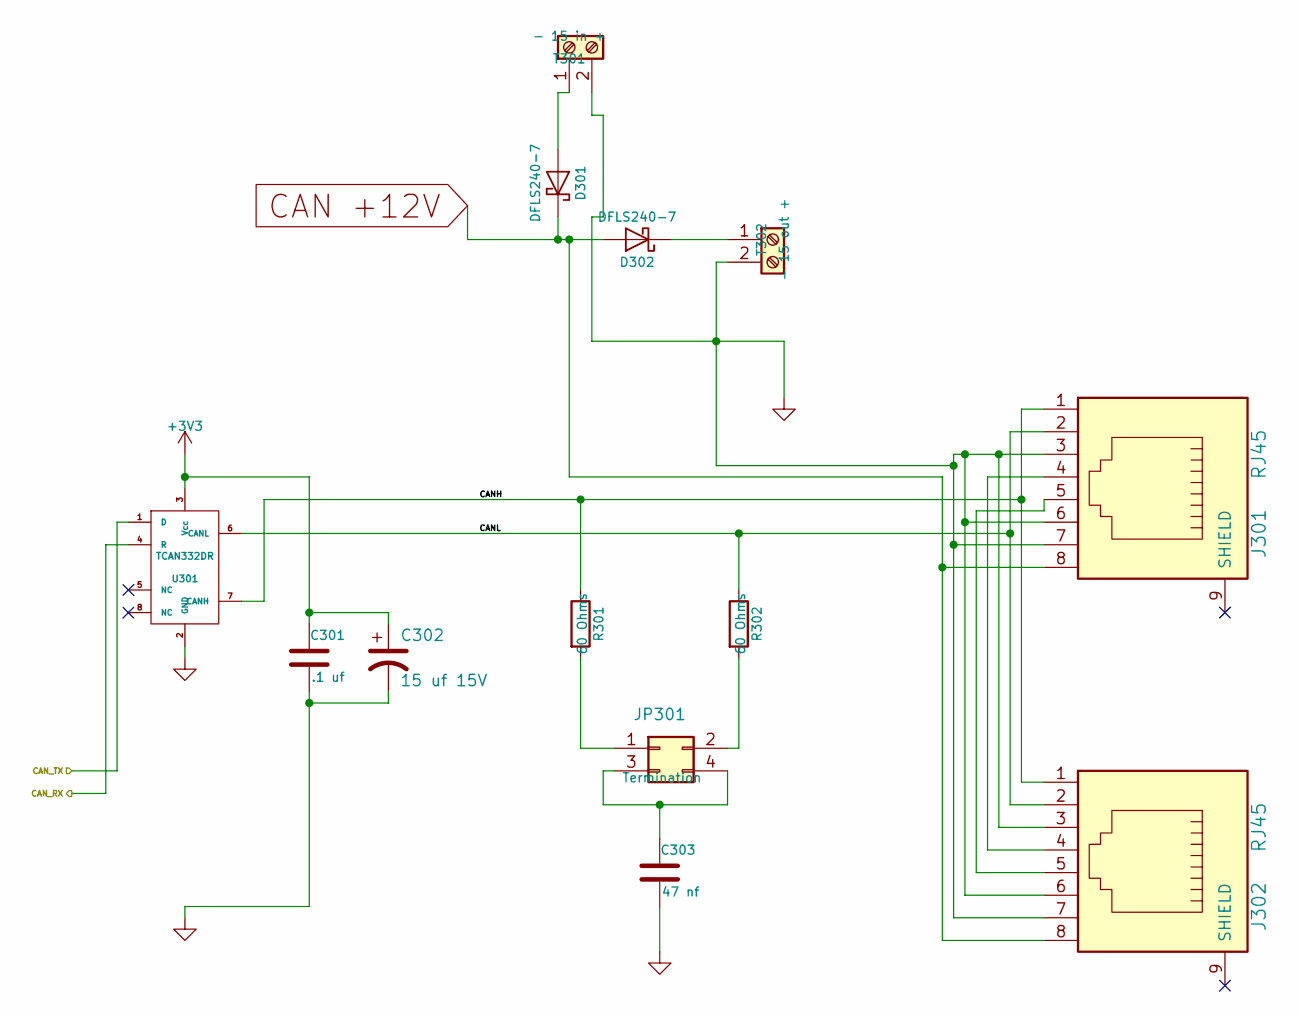
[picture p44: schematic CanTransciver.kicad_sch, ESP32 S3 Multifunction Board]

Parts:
C301: .1 uf; C_0603; Mouser Part Number 710-885012206095
C302: 15 uf 15V; CP_Elec_4x5.7; Mouser Part Number 647-UUD1C150MCL
C303: 47 nf; C_0603; Mouser Part Number 710-885012206093
D301, D302: DFLS240-7; D_PowerDI-123; Mouser Part Number 621-DFLS240-7
J301, J302: RJ45; RJ45_8N-S; Mouser Part Number 710-615008144221
JP301: Termination; Pin_Header_Straight_2x02_Pitch2.54mm; Mouser Part Number 649-67997-404HLF
R301, R302: 60 Ohms; R_0603_1608Metric_Pad0.98x0.95mm_HandSolder; Mouser Part Number 72-P0603C60R0BNTA
T301: - 15 in +; TerminalBlock_Pheonix_MPT-2.54mm_2pol; Mouser Part Number 651-1725656
T302: - 15 out +; TerminalBlock_Pheonix_MPT-2.54mm_2pol; Mouser Part Number 651-1725656
U301: TCAN332DR; SOIC-8_3.9x4.9mm_Pitch1.27mm; Mouser Part Number 595-TCAN332DR

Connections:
+3V3: C301.1, C302.1, U301.3 (Vcc); also elsewhere on the board
/CAN Transciver/CANH: J301.1, J302.1, R301.1, U301.7 (CANH)
/CAN Transciver/CANL: J301.2, J302.2, R302.1, U301.6 (CANL)
/CAN Transciver/CAN_RX: U301.4 (R); also elsewhere on the board
/CAN Transciver/CAN_TX: U301.1 (D); also elsewhere on the board
CAN +12V: D301.1 (K), D302.2 (A), J301.8, J302.8; also elsewhere on the board
GND: C301.2, C302.2, C303.2, J301.3, J301.6, J301.7, J302.3, J302.6, J302.7, T301.2, T302.2, U301.2 (GND); also elsewhere on the board
unnamed: C303.1, JP301.3, JP301.4
unnamed: D301.2 (A), T301.1
unnamed: D302.1 (K), T302.1
unnamed: J301.4, J302.4
unnamed: J301.5, J302.5
unnamed: JP301.1, R301.2
unnamed: JP301.2, R302.2

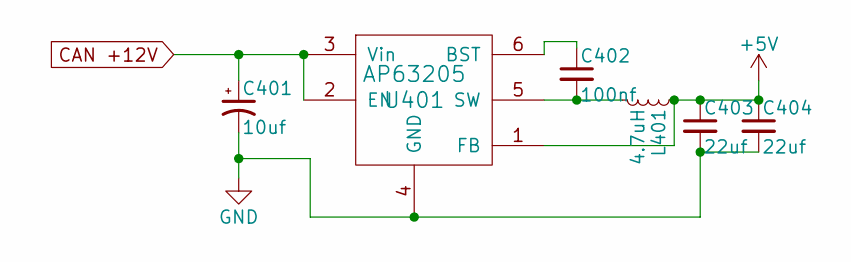
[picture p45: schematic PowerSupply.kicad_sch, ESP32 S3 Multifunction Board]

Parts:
C401: 10uf; CP_Elec_5x5.3; Mouser Part Number 710-865230542002
C402: 100nf; C_0603; Mouser Part Number 710-885012206020
C403, C404: 22uf; C_0603; Mouser Part Number 603-CC0603MRX6S5B226
L401: 4.7uH; L_7.3x7.3_H4.5; Mouser Part Number 81-B1047AS-4R7NP3
U401: AP63205; TSOT-23-6_MK06A; Mouser Part Number 621-AP63205WU-7

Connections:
+5V: C403.1, C404.1, L401.1, U401.1 (FB); also elsewhere on the board
CAN +12V: C401.1, U401.2 (EN), U401.3 (Vin); also elsewhere on the board
GND: C401.2, C403.2, C404.2, U401.4 (GND); also elsewhere on the board
unnamed: C402.1, U401.6 (BST)
unnamed: C402.2, L401.2, U401.5 (SW)

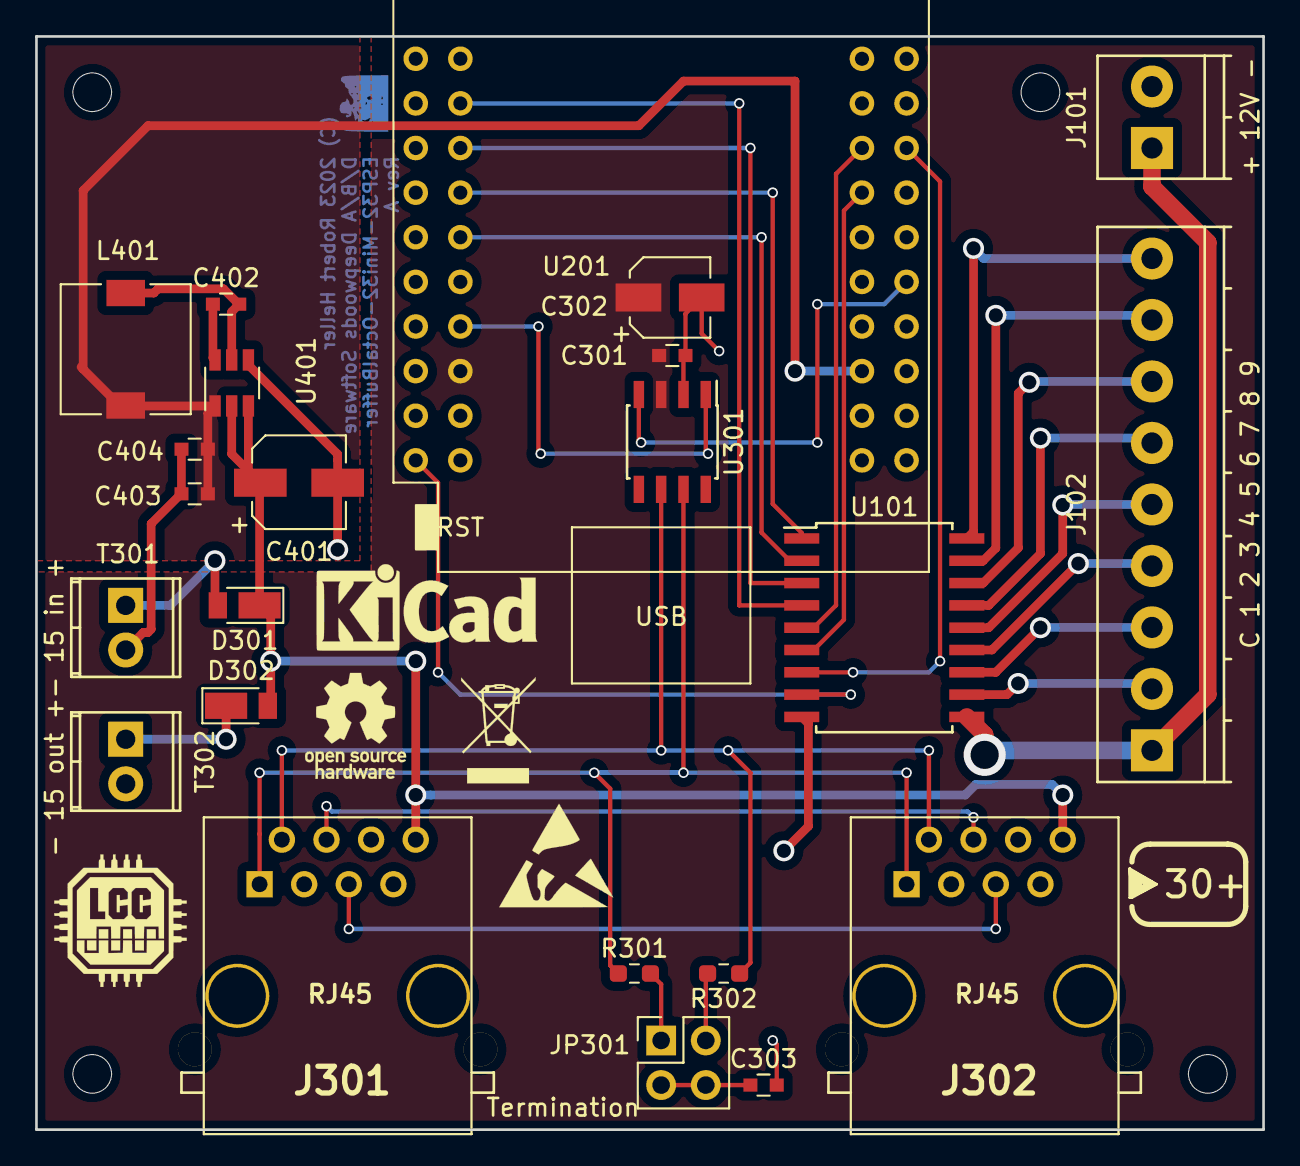
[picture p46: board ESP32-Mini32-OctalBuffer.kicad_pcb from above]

Board: 2 copper layers, 69.9 x 62.2 mm, 23 parts (0 on the bottom side), 34 nets.

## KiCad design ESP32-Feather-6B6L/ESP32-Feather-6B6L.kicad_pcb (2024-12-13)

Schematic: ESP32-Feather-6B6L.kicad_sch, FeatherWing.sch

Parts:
MS1: FEATHERWING

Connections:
+3V3: MS1.2 (3V); also elsewhere on the board
/AREF: MS1.3 (AREF)
/CAN_RX: MS1.9 (GPIOA4); also elsewhere on the board
/CAN_TX: MS1.10 (GPIOA5); also elsewhere on the board
/N$1: MS1.27 (EN)
/N$2: MS1.16 (NC)
/N$3: MS1.25 (GPIO13); also elsewhere on the board
/N$4: MS1.15 (GPIOTX)
/N$5: MS1.24 (GPIO12); also elsewhere on the board
/N$6: MS1.14 (GPIORX)
/N$7: MS1.13 (GPIOMISO); also elsewhere on the board
/N$8: MS1.12 (GPIOMOSI); also elsewhere on the board
/N$9: MS1.11 (GPIOSCK); also elsewhere on the board
/N$12: MS1.8 (GPIOA3); also elsewhere on the board
/N$13: MS1.7 (GPIOA2); also elsewhere on the board
/N$14: MS1.6 (GPIOA1); also elsewhere on the board
/N$15: MS1.5 (GPIOA0); also elsewhere on the board
/N$18: MS1.1 (~RESET)
/N$19: MS1.23 (GPIO11); also elsewhere on the board
/N$20: MS1.22 (GPIO10); also elsewhere on the board
/N$21: MS1.21 (GPIO9); also elsewhere on the board
/N$22: MS1.20 (GPIO6); also elsewhere on the board
/N$23: MS1.19 (GPIO5); also elsewhere on the board
/N$24: MS1.18 (GPIOSCL)
/N$25: MS1.17 (GPIOSDA)
/VBAT: MS1.28 (VBAT)

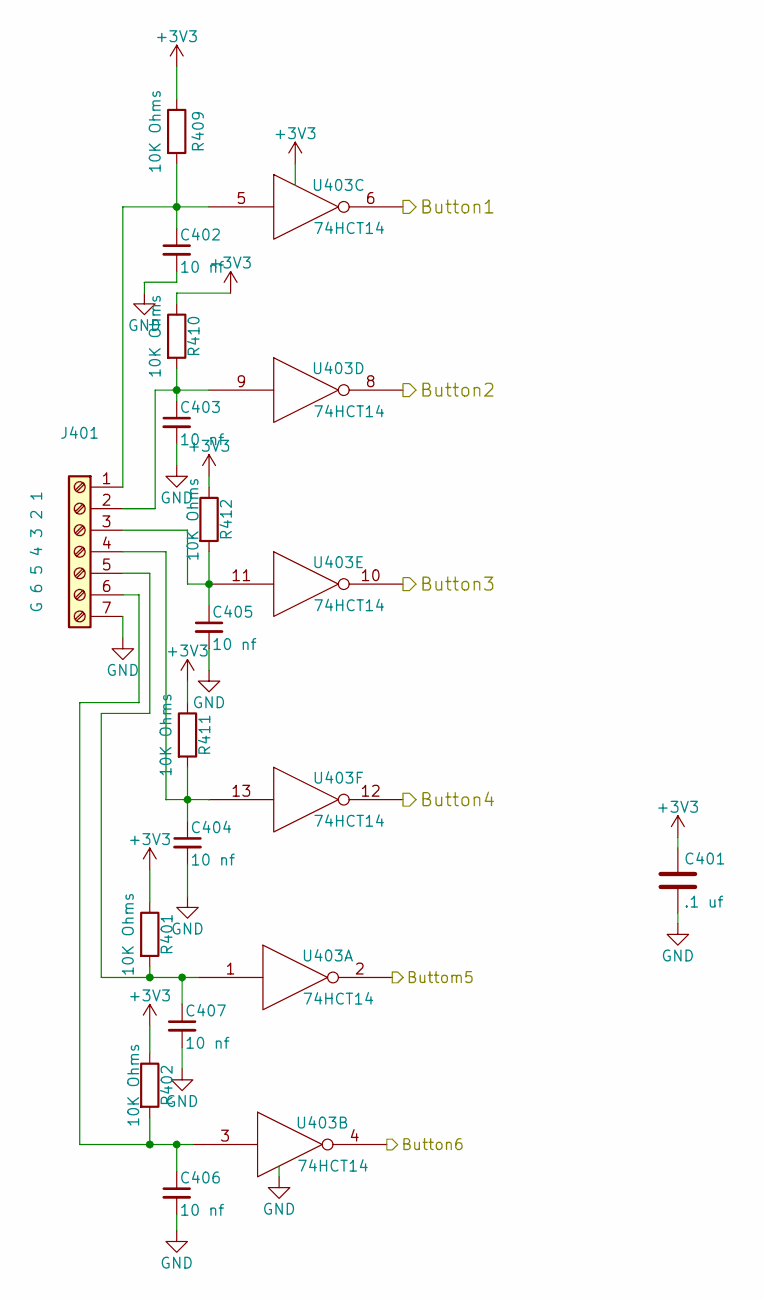
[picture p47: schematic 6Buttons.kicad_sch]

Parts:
C401: .1 uf; C_0603_1608Metric; Mouser Part Number 710-885012206095
C402, C403, C404, C405, C406, C407: 10 nf; C_0603_1608Metric; Mouser Part Number 710-885382206002
J401: G 6 5 4 3 2 1; TerminalBlock_TE_282834-7_1x07_P2.54mm_Horizontal; Mouser Part Number 571-282834-7
R401, R402, R409, R410, R411, R412: 10K Ohms; R_0603_1608Metric; Mouser Part Number 71-CRCW060310K0JNEBC
U403: 74HCT14; SO-14_3.9x8.65mm_P1.27mm; Mouser Part Number 595-CD74HC14M

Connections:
+3V3: C401.1, R401.1, R402.1, R409.1, R410.1, R411.1, R412.1, U403.14 (VCC); also elsewhere on the board
/N$8: U403.4; also elsewhere on the board
/N$9: U403.2; also elsewhere on the board
/N$12: U403.12; also elsewhere on the board
/N$13: U403.10; also elsewhere on the board
/N$14: U403.8; also elsewhere on the board
/N$15: U403.6; also elsewhere on the board
unnamed: C402.1, J401.1, R409.2, U403.5
unnamed: C403.1, J401.2, R410.2, U403.9
unnamed: C404.1, J401.4, R411.2, U403.13
unnamed: C405.1, J401.3, R412.2, U403.11
unnamed: C406.1, J401.6, R402.2, U403.3
unnamed: C407.1, J401.5, R401.2, U403.1

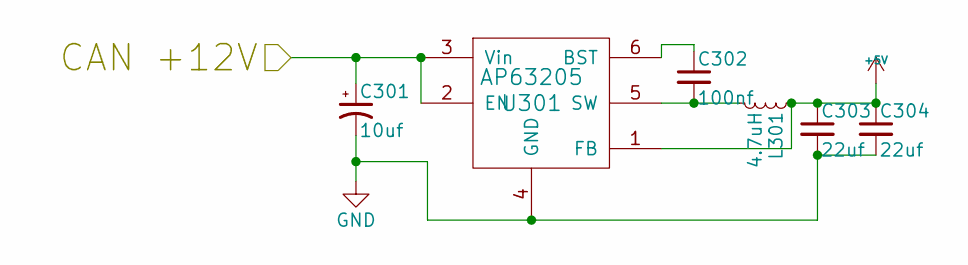
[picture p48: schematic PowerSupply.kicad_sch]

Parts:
C301: 10uf; CP_Elec_5x5.3; Mouser Part Number 710-865230542002
C302: 100nf; C_0603_1608Metric; Mouser Part Number 710-885012206020
C303, C304: 22uf; C_0603_1608Metric; Mouser Part Number 603-CC0603MRX6S5B226
L301: 4.7uH; L_7.3x7.3_H4.5; Mouser Part Number 81-B1047AS-4R7N=P3
U301: AP63205; TSOT-23-6; Mouser Part Number 621-AP63205WU-7


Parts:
J501: + 1 2 3 4 5 6 7 8 -; TerminalBlock_Phoenix_MPT-0,5-10-2.54_1x10_P2.54mm_Horizont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
R501, R502, R503, R504, R505, R506, R507, R508: 1.5K Ohms; R_Axial_DIN0204_L3.6mm_D1.6mm_P7.62mm_Horizontal; Mouser Part Number 603-CFR-25JR-52-1K5
U501: TBD62084A; SOIC-18W_7.5x11.6mm_P1.27mm; Mouser Part Number 757-TBD62084AFWGEL

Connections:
/Eight LEDs/LEDPower: J501.10, U501.10 (OC)
/N$3: U501.1 (In); also elsewhere on the board
/N$5: U501.2 (In); also elsewhere on the board
/N$7: U501.8 (In); also elsewhere on the board
/N$19: U501.3 (In); also elsewhere on the board
/N$20: U501.4 (In); also elsewhere on the board
/N$21: U501.5 (In); also elsewhere on the board
/N$22: U501.6 (In); also elsewhere on the board
/N$23: U501.7 (In); also elsewhere on the board
unnamed: J501.2, R507.1
unnamed: J501.3, R508.1
unnamed: J501.4, R506.1
unnamed: J501.5, R505.1
unnamed: J501.6, R504.1
unnamed: J501.7, R503.1
unnamed: J501.8, R502.1
unnamed: J501.9, R501.1
unnamed: R501.2, U501.18 (Out)
unnamed: R502.2, U501.17 (Out)
unnamed: R503.2, U501.16 (Out)
unnamed: R504.2, U501.15 (Out)
unnamed: R505.2, U501.14 (Out)
unnamed: R506.2, U501.13 (Out)
unnamed: R507.2, U501.11 (Out)
unnamed: R508.2, U501.12 (Out)

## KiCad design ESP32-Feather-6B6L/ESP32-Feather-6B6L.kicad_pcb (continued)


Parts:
C201: .1 uf; C_0603_1608Metric; Mouser Part Number 710-885012206095
C202: 15 uf 15V; CP_Elec_4x5.7; Mouser Part Number 710-865080340002
J201, J202: RJ45; RJ45_8N-S; Mouser Part Number 710-615008144221
U201: TCAN332DR; SOIC-8_3.9x4.9mm_P1.27mm; Mouser Part Number 595-TCAN332DR

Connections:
+3V3: C201.1, C202.1, U201.3 (Vcc); also elsewhere on the board
/CAN Transceiver/CANH: J201.1, J202.1, U201.7 (CANH)
/CAN Transceiver/CANL: J201.2, J202.2, U201.6 (CANL)
/CAN_RX: U201.4 (R); also elsewhere on the board
/CAN_TX: U201.1 (D); also elsewhere on the board
unnamed: J201.4, J202.4
unnamed: J201.5, J202.5

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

Board: 2 copper layers, 86.4 x 78.7 mm, 36 parts (0 on the bottom side), 48 nets.

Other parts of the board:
D301: SB160-E3/54; D_DO-41_SOD81_P7.62mm_Horizontal

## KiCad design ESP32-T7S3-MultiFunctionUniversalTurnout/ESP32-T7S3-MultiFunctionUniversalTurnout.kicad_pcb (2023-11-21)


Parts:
FD101, FD102, FD103: FidMark; Fiducial_classic_Small_SilkscreenTop_Type1
J101: Turnout Daughterboard; Socket_Strip_Straight_1x10_Pitch2.54mm
MK101, MK102, MK103: Mounting_Hole; MountingHole_3.7mm
MK104: Mounting_Hole_PAD; MountingHole_3.7mm_Pad

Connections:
/Motor1: J101.1; also elsewhere on the board
/Motor2: J101.2; also elsewhere on the board
/Motor3: J101.3; also elsewhere on the board
/Motor4: J101.4; also elsewhere on the board
/Points1: J101.7; also elsewhere on the board
/Points2: J101.8; also elsewhere on the board
/Points3: J101.9; also elsewhere on the board
/Points4: J101.10; also elsewhere on the board
GND: J101.6, MK104.1; also elsewhere on the board


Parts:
D2: ACT1; LED_0402; Mouser Part Number 710-150040GS73220
D4: ACT2; LED_0402; Mouser Part Number 710-150040SS73220
R2, R3: 270; R_0402; Mouser Part Number 754-RR0510P-271D
R203, R206: 2.4K; R_0402; Mouser Part Number 603-RC0402FR-072K4L
U201: TTGO-T7_S3-V1.1; ESP32_mini

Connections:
+5V: U201.35 (VCC_(USB)); also elsewhere on the board
/Buttons and LEDs/Button1: U201.28 (IO_38); also elsewhere on the board
/Buttons and LEDs/Button2: U201.40 (CLK/IO_6); also elsewhere on the board
/Buttons and LEDs/Button3: U201.9 (IO_46); also elsewhere on the board
/Buttons and LEDs/Button4: U201.6 (IO_16); also elsewhere on the board
/Buttons and LEDs/LED1: U201.10 (IO_17/LED); also elsewhere on the board
/Buttons and LEDs/LED2: U201.8 (IO_18); also elsewhere on the board
/Buttons and LEDs/LED3: U201.15 (IO_21); also elsewhere on the board
/Buttons and LEDs/LED4: U201.38 (IO_1); also elsewhere on the board
/CAN Tranceiver/CAN_RX: U201.32 (IO_04); also elsewhere on the board
/CAN Tranceiver/CAN_TX: U201.14 (IO_05); also elsewhere on the board
/ESP32 MCU/GPIO0(Act2): D4.1 (K), U201.34 (IO_0)
/ESP32 MCU/GPIO3/SCL: R206.1, U201.24 (IO_3); also elsewhere on the board
/ESP32 MCU/GPIO7(OD4): U201.39 (IO_7); also elsewhere on the board
/ESP32 MCU/GPIO15(Act1): D2.1 (K), U201.4 (IO_15)
/ESP32 MCU/GPIO39/TCK(OD1): U201.18 (TCK); also elsewhere on the board
/ESP32 MCU/GPIO40/SDA: R203.2, U201.37 (TD0); also elsewhere on the board
/ESP32 MCU/GPIO45(OD3): U201.11 (IO_45); also elsewhere on the board
/ESP32 MCU/GPIO48(OD2): U201.5 (IO_48); also elsewhere on the board
/Motor1: U201.17 (IO_09); also elsewhere on the board
/Motor2: U201.19 (IO_11); also elsewhere on the board
/Motor3: U201.12 (IO_8); also elsewhere on the board
/Motor4: U201.13 (TMS); also elsewhere on the board
/Points1: U201.26 (IO_12); also elsewhere on the board
/Points2: U201.27 (IO_13); also elsewhere on the board
/Points3: U201.25 (IO_14); also elsewhere on the board
/Points4: U201.20 (IO_10); also elsewhere on the board
GND: U201.1 (GND), U201.22 (GND), U201.33 (GND); also elsewhere on the board
unnamed: D2.2 (A), R2.2
unnamed: D4.2 (A), R3.2


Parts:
C301: 10uf; CP_Elec_5x5.3; Mouser Part Number 710-865230542002
C302: 100nf; C_0603; Mouser Part Number 710-885012206020
C303, C304: 22uf; C_0603; Mouser Part Number 603-CC0603MRX6S5B226
L301: 4.7uH; L_7.3x7.3_H4.5; Mouser Part Number 81-B1047AS-4R7N=P3
U301: AP63205; TSOT-23-6_MK06A; Mouser Part Number 621-AP63205WU-7

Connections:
+5V: C303.1, C304.1, L301.1, U301.1 (FB); also elsewhere on the board
CAN +12V: C301.1, U301.2 (EN), U301.3 (Vin); also elsewhere on the board
GND: C301.2, C303.2, C304.2, U301.4 (GND); also elsewhere on the board
unnamed: C302.1, U301.6 (BST)
unnamed: C302.2, L301.2, U301.5 (SW)


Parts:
C401: .1 uf; C_0603; Mouser Part Number 710-885012206095
C402, C403, C404, C405: 10 nf; C_0603; Mouser Part Number 710-885382206002
R401, R403, R405, R407: R; R_Axial_DIN0207_L6.3mm_D2.5mm_P7.62mm_Horizontal
R402, R404, R406, R408: 1.5K Ohms; R_0603; Mouser Part Number 71-CRCW06031K50JNEAC
R409, R410, R411, R412: 10K Ohms; R_0603; Mouser Part Number 71-CRCW060310K0JNEBC
Term401: +V 1 2 3 4 GND; TerminalBlock_Pheonix_MPT-2.54mm_6pol; Mouser Part Number 651-1725698
Term402: 1 2 3 4 GND; TerminalBlock_Pheonix_MPT-2.54mm_5pol; Mouser Part Number 651-1725685
U401, U402: TC4426; SOIC-8_3.9x4.9mm_Pitch1.27mm; Mouser Part Number 579-TC1426COA713
U403: 74HCT14; SOIC-14_3.9x8.7mm_Pitch1.27mm; Mouser Part Number 595-CD74HC14M

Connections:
/Buttons and LEDs/Button1: U403.6; also elsewhere on the board
/Buttons and LEDs/Button2: U403.8; also elsewhere on the board
/Buttons and LEDs/Button3: U403.10; also elsewhere on the board
/Buttons and LEDs/Button4: U403.12; also elsewhere on the board
/Buttons and LEDs/LED1: U401.2 (IN); also elsewhere on the board
/Buttons and LEDs/LED2: U401.4 (IN); also elsewhere on the board
/Buttons and LEDs/LED3: U402.2 (IN); also elsewhere on the board
/Buttons and LEDs/LED4: U402.4 (IN); also elsewhere on the board
GND: C401.2, C402.2, C403.2, C404.2, C405.2, Term401.6, Term402.5, U401.3 (GND), U402.3 (GND), U403.1, U403.3, U403.7 (GND); also elsewhere on the board
unnamed: C402.1, R409.2, Term402.1, U403.5
unnamed: C403.1, R410.2, Term402.2, U403.9
unnamed: C404.1, R411.2, Term402.4, U403.13
unnamed: C405.1, R412.2, Term402.3, U403.11
unnamed: R401.1, R402.1, Term401.2
unnamed: R403.1, R404.1, Term401.3
unnamed: R405.1, R406.1, Term401.4
unnamed: R407.1, R408.1, Term401.5
VPower: Term401.1, U401.6 (VPower), U402.6 (VPower)


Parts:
C601, C602, C603, C604: 2.2uf 35V; CP_Elec_4x5.7; Mouser Part Number 667-EEE-1VA2R2NR
D601, D602, D603, D604, D605, D606, D607, D608: 1N4148; D_SOD-323; Mouser Part Number 750-1N4148WS-HF
D609, D610, D611, D612: LED; LED_0603; Mouser Part Number 710-150060SS55040
R601, R602, R603, R604: 22K Ohms; R_0603; Mouser Part Number 71-RCG060322K0JNEA
R605, R606, R607, R608: 1M Ohms; R_0603; Mouser Part Number 71-CRCW06031M00JNEAC
R609, R610, R611, R612: 2.7K Ohms; R_0603; Mouser Part Number 71-CRCW06032K70JNEAC
RV601, RV602, RV603, RV604: 25K Ohms; Potentiometer_Trimmer_Bourns_3214J; Mouser Part Number 652-3314J-1-253E
Term601: 4B 4A 3B 3A 2B 2A 1B 1A; TerminalBlock_Pheonix_MPT-2.54mm_8pol; Mouser Part Number 651-1725711
U601, U602: LM339; SOIC-14_3.9x8.7mm_Pitch1.27mm; Mouser Part Number 595-LM339DR

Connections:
/ESP32 MCU/GPIO7(OD4): D612.1 (K), U602.14; also elsewhere on the board
/ESP32 MCU/GPIO39/TCK(OD1): D609.1 (K), U602.2; also elsewhere on the board
/ESP32 MCU/GPIO45(OD3): D611.1 (K), U602.13; also elsewhere on the board
/ESP32 MCU/GPIO48(OD2): D610.1 (K), U602.1; also elsewhere on the board
GND: C601.2, C602.2, C603.2, C604.2, RV601.1, RV602.1, RV603.1, RV604.1, U601.12 (V-), U602.12 (V-); also elsewhere on the board
unnamed: C601.1, R605.2, U601.2, U602.5 (+)
unnamed: C602.1, R606.2, U601.1, U602.7 (+)
unnamed: C603.1, R607.2, U601.13, U602.11 (+)
unnamed: C604.1, R608.2, U601.14, U602.9 (+)
unnamed: D601.1 (K), D605.2 (A), Term601.1, U601.4 (-)
unnamed: D601.2 (A), D605.1 (K), RV601.2, Term601.2
unnamed: D602.1 (K), D606.2 (A), Term601.3, U601.6 (-)
unnamed: D602.2 (A), D606.1 (K), RV602.2, Term601.4
unnamed: D603.1 (K), D607.2 (A), Term601.5, U601.10 (-)
unnamed: D603.2 (A), D607.1 (K), RV603.2, Term601.6
unnamed: D604.1 (K), D608.2 (A), Term601.7, U601.8 (-)
unnamed: D604.2 (A), D608.1 (K), RV604.2, Term601.8
unnamed: D609.2 (A), R609.2
unnamed: D610.2 (A), R610.2
unnamed: D611.2 (A), R611.2
unnamed: D612.2 (A), R612.2
unnamed: R601.2, RV601.3, U601.5 (+), U602.4 (-)
unnamed: R602.2, RV602.3, U601.7 (+), U602.6 (-)
unnamed: R603.2, RV603.3, U601.11 (+), U602.10 (-)
unnamed: R604.2, RV604.3, U601.9 (+), U602.8 (-)


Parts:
C701: .1 uf; C_0603; Mouser Part Number 710-885012206095
D701: DFLS240-7; D_PowerDI-123; Mouser Part Number 621-DFLS240-7
JP701, JP702, JP703, JP704, JP705, JP706, JP707, JP708: 0; R_1206; Mouser Part Number 71-CRCW12060000Z0EBC
P701: A7 A6 A5 A4 A3 A2 A1 A0 C; TerminalBlock_Pheonix_MPT-2.54mm_9pol; Mouser Part Number 651-1725724
P702: B7 B6 B5 B4 B3 B2 B1 B0 C; TerminalBlock_Pheonix_MPT-2.54mm_9pol; Mouser Part Number 651-1725724
RP701, RP702: 1.5K Ohms; 4816P; Mouser Part Number 652-4816P-T1LF-152LF
T701: + 12V -; TerminalBlock_Pheonix_MPT-2.54mm_2pol; Mouser Part Number 651-1725656
U701: PCA9685; TSSOP-28_4.4x9.7mm_Pitch0.65mm; Mouser Part Number 771-PCA9685PW,118
U702, U703: TBD62X83A; SOIC-18W_7.5x11.6mm_Pitch1.27mm; Mouser Part Number 757-TBD62083AFG or 757-TBD62783AFG

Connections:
+12V: D701.1 (K), JP701.2, JP704.1, JP705.2, JP708.1, T701.1
/ESP32 MCU/GPIO3/SCL: U701.26 (SCL); also elsewhere on the board
/ESP32 MCU/GPIO40/SDA: U701.27 (SDA); also elsewhere on the board
CAN +12V: D701.2 (A); also elsewhere on the board
GND: C701.2, JP702.2, JP703.1, JP706.2, JP707.1, T701.2, U701.1 (A0), U701.2 (A1), U701.3 (A2), U701.4 (A3), U701.5 (A4), U701.14 (Vss), U701.23 (OE), U701.24 (A5), U701.25 (ExtCLK); also elsewhere on the board
unnamed: JP701.1, JP703.2, P701.9, U702.10 (OC)
unnamed: JP702.1, JP704.2, U702.9 (IC)
unnamed: JP705.1, JP707.2, P702.9, U703.10 (OC)
unnamed: JP706.1, JP708.2, U703.9 (IC)
unnamed: P701.1, RP701.16 (R1.2)
unnamed: P701.2, RP701.15 (R2.2)
unnamed: P701.3, RP701.14 (R3.2)
unnamed: P701.4, RP701.13 (R4.2)
unnamed: P701.5, RP701.12 (R5.2)
unnamed: P701.6, RP701.11 (R6.2)
unnamed: P701.7, RP701.10 (R7.2)
unnamed: P701.8, RP701.9 (R8.2)
unnamed: P702.1, RP702.16 (R1.2)
unnamed: P702.2, RP702.15 (R2.2)
unnamed: P702.3, RP702.14 (R3.2)
unnamed: P702.4, RP702.13 (R4.2)
unnamed: P702.5, RP702.12 (R5.2)
unnamed: P702.6, RP702.11 (R6.2)
unnamed: P702.7, RP702.10 (R7.2)
unnamed: P702.8, RP702.9 (R8.2)
unnamed: RP701.1 (R1.1), U702.18 (Out)
unnamed: RP701.2 (R2.1), U702.17 (Out)
unnamed: RP701.3 (R3.1), U702.16 (Out)
unnamed: RP701.4 (R4.1), U702.15 (Out)
unnamed: RP701.5 (R5.1), U702.14 (Out)
unnamed: RP701.6 (R6.1), U702.13 (Out)
unnamed: RP701.7 (R7.1), U702.12 (Out)
unnamed: RP701.8 (R8.1), U702.11 (Out)
unnamed: RP702.1 (R1.1), U703.18 (Out)
unnamed: RP702.2 (R2.1), U703.17 (Out)
unnamed: RP702.3 (R3.1), U703.16 (Out)
unnamed: RP702.4 (R4.1), U703.15 (Out)
unnamed: RP702.5 (R5.1), U703.14 (Out)
unnamed: RP702.6 (R6.1), U703.13 (Out)
unnamed: RP702.7 (R7.1), U703.12 (Out)
unnamed: RP702.8 (R8.1), U703.11 (Out)
unnamed: U701.6 (LED0), U702.8 (In)
unnamed: U701.7 (LED1), U702.7 (In)
unnamed: U701.8 (LED2), U702.6 (In)
unnamed: U701.9 (LED3), U702.5 (In)
unnamed: U701.10 (LED4), U702.4 (In)
unnamed: U701.11 (LED5), U702.3 (In)
unnamed: U701.12 (LED6), U702.2 (In)
unnamed: U701.13 (LED7), U702.1 (In)
unnamed: U701.15 (LED8), U703.8 (In)
unnamed: U701.16 (LED9), U703.7 (In)
unnamed: U701.17 (LED10), U703.6 (In)
unnamed: U701.18 (LED11), U703.5 (In)
unnamed: U701.19 (LED12), U703.4 (In)
unnamed: U701.20 (LED13), U703.3 (In)
unnamed: U701.21 (LED14), U703.2 (In)
unnamed: U701.22 (LED15), U703.1 (In)


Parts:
C801: .1 uf; C_0603; Mouser Part Number 710-885012206095
C802: 15 uf 15V; CP_Elec_4x5.7; Mouser Part Number 710-865080340002
C803: 47 nf; C_0603; Mouser Part Number 710-885012206093
D801, D802: DFLS240-7; D_PowerDI-123; Mouser Part Number 621-DFLS240-7
J801, J802: RJ45; RJ45_8N-S; Mouser Part Number 710-615008144221
JP801: Termination; Pin_Header_Straight_2x02_Pitch2.54mm; Mouser Part Number 649-67997-404HLF
R801, R802: 60 Ohms; R_1206; Mouser Part Number 71-CRCW120660R0KNAIF
T801: - 15 in +; TerminalBlock_Pheonix_MPT-2.54mm_2pol; Mouser Part Number 651-1725656
T802: - 15 out +; TerminalBlock_Pheonix_MPT-2.54mm_2pol; Mouser Part Number 651-1725656
U801: TCAN332DR; SOIC-8_3.9x4.9mm_Pitch1.27mm; Mouser Part Number 595-TCAN332DR

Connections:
/CAN Tranceiver/CANH: J801.1, J802.1, R801.1, U801.7 (CANH)
/CAN Tranceiver/CANL: J801.2, J802.2, R802.1, U801.6 (CANL)
/CAN Tranceiver/CAN_RX: U801.4 (R); also elsewhere on the board
/CAN Tranceiver/CAN_TX: U801.1 (D); also elsewhere on the board
CAN +12V: D801.1 (K), D802.2 (A), J801.8, J802.8; also elsewhere on the board
GND: C801.2, C802.2, C803.2, J801.3, J801.6, J801.7, J802.3, J802.6, J802.7, T801.2, T802.2, U801.2 (GND); also elsewhere on the board
unnamed: C803.1, JP801.3, JP801.4
unnamed: D801.2 (A), T801.1
unnamed: D802.1 (K), T802.1
unnamed: J801.4, J802.4
unnamed: J801.5, J802.5
unnamed: JP801.1, R801.2
unnamed: JP801.2, R802.2

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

Board: 2 copper layers, 99.1 x 125.7 mm, 109 parts (0 on the bottom side), 129 nets.

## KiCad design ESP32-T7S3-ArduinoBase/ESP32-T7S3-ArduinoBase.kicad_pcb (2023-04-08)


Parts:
P1: Power; Socket_Strip_Arduino_1x08
P2: Analog; Socket_Strip_Arduino_1x06
P3: Digital; Socket_Strip_Arduino_1x10
P4: Digital; Socket_Strip_Arduino_1x08
P5, P6, P7, P8: CONN_01X01; Arduino_1pin
Q101, Q102: BSS138; SOT-23; Mouser Part Number 621-BSS138-7-F
R101, R102, R103, R104: 2.4K; R_0603
U101: TTGO-T7_S3-V1.1; ESP32_mini

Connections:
+5V: P1.5, R103.1, R104.1, U101.35 (VCC_(USB)); also elsewhere on the board
/0(Rx): P4.8, U101.23 (RXD)
/1(Tx): P4.7, U101.21 (TXD)
/2: P4.6, U101.11 (IO_45)
/3(**): P4.5, U101.9 (IO_46)
/4: P4.4, U101.8 (IO_18)
/5(**): P4.3, U101.6 (IO_16)
/6(**): P4.2, U101.4 (IO_15)
/7: P4.1, U101.25 (IO_14)
/8: P3.10, U101.27 (IO_13)
/9(**): P3.9, U101.17 (IO_09)
/10(**/SS): P3.8, U101.20 (IO_10)
/11(**/MOSI): P3.7, U101.19 (IO_11)
/12(MISO): P3.6, U101.26 (IO_12)
/13(SCK): P3.5, U101.10 (IO_17/LED)
/A0: P2.1, U101.38 (IO_1)
/A1: P2.2, U101.40 (CLK/IO_6)
/A2: P2.3, U101.39 (IO_7)
/A3: P2.4, U101.12 (IO_8)
/A4(SDA): P2.5, P3.2, Q101.3 (D), R103.2
/A5(SCL): P2.6, P3.1, Q102.3 (D), R104.2
/AREF: P3.3
/CAN Transceiver/CAN_RX: U101.32 (IO_04); also elsewhere on the board
/CAN Transceiver/CAN_TX: U101.14 (IO_05); also elsewhere on the board
/IOREF: P1.2
/Reset: P1.3
/SCL: Q102.2 (S), R102.2, U101.24 (IO_3)
/SDA: Q101.2 (S), R101.2, U101.36 (IO_2)
/Vin: P1.8
GND: P1.6, P1.7, P3.4, U101.1 (GND), U101.22 (GND), U101.33 (GND); also elsewhere on the board

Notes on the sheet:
Holes
Shield for Arduino that uses the same pin disposition like "Uno" board Rev 3.


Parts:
C201: .1 uf; C_0603; Mouser Part Number 710-885012206095
C202: 15 uf 15V; CP_Elec_4x5.7; Mouser Part Number 647-UUD1C150MCL
C203: 47 nf; C_0603; Mouser Part Number 710-885012206093
D201, D202: DFLS240-7; D_PowerDI-123; Mouser Part Number 621-DFLS240-7
J201, J202: RJ45; RJ45_8N-S; Mouser Part Number 710-615008144221
JP201: Termination; Pin_Header_Straight_2x02_Pitch2.54mm; Mouser Part Number 649-67997-404HLF
R201, R202: 60 Ohms; R_1206; Mouser Part Number 71-CRCW120660R0KNAIF
T201: - 15 in +; TerminalBlock_Pheonix_MPT-2.54mm_2pol; Mouser Part Number 651-1725656
T202: - 15 out +; TerminalBlock_Pheonix_MPT-2.54mm_2pol; Mouser Part Number 651-1725656
U201: TCAN332DR; SOIC-8_3.9x4.9mm_Pitch1.27mm; Mouser Part Number 595-TCAN332DR

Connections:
/CAN Transceiver/CANH: J201.1, J202.1, R201.1, U201.7 (CANH)
/CAN Transceiver/CANL: J201.2, J202.2, R202.1, U201.6 (CANL)
/CAN Transceiver/CAN_RX: U201.4 (R); also elsewhere on the board
/CAN Transceiver/CAN_TX: U201.1 (D); also elsewhere on the board
CAN +12V: D201.1 (K), D202.2 (A), J201.8, J202.8; also elsewhere on the board
GND: C201.2, C202.2, C203.2, J201.3, J201.6, J201.7, J202.3, J202.6, J202.7, T201.2, T202.2, U201.2 (GND); also elsewhere on the board
unnamed: C203.1, JP201.3, JP201.4
unnamed: D201.2 (A), T201.1
unnamed: D202.1 (K), T202.1
unnamed: J201.4, J202.4
unnamed: J201.5, J202.5
unnamed: JP201.1, R201.2
unnamed: JP201.2, R202.2


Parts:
C301: 10uf; CP_Elec_5x5.3; Mouser Part Number 710-865230542002
C302: 100nf; C_0603; Mouser Part Number 710-885012206020
C303, C304: 22uf; C_0603; Mouser Part Number 603-CC0603MRX6S5B226
L301: 4.7uH; L_7.3x7.3_H4.5; Mouser Part Number 81-B1047AS-4R7NP3
U301: AP63205; TSOT-23-6_MK06A; Mouser Part Number 621-AP63205WU-7

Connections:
+5V: C303.1, C304.1, L301.1, U301.1 (FB); also elsewhere on the board
CAN +12V: C301.1, U301.2 (EN), U301.3 (Vin); also elsewhere on the board
GND: C301.2, C303.2, C304.2, U301.4 (GND); also elsewhere on the board
unnamed: C302.1, U301.6 (BST)
unnamed: C302.2, L301.2, U301.5 (SW)

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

Board: 2 copper layers, 128.3 x 53.3 mm, 34 parts (0 on the bottom side), 39 nets.

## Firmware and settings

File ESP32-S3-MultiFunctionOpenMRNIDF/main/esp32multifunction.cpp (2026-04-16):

// -!- C++ -!- //////////////////////////////////////////////////////////////
//
//  System        : 
//  Module        : 
//  Object Name   : $RCSfile$
//  Revision      : $Revision$
//  Date          : $Date$
//  Author        : $Author$
//  Created By    : Robert Heller
//  Created       : Thu Jun 23 12:17:40 2022
//  Last Modified : <260416.1419>
//
//  Description	
//
//  Notes
//
//  History
//	
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
/** @mainpage Introduction
 * 
 * This is the firmware for various ESP32S3-based "MultiFunction" LCC Node 
 * boards.
 * Boards this software will work for include:
 * 
 * - ESP32-S3-MultiFunction original S3-MultiFunction board using a "bare"
 *   ESP32-S3FN8 chip.
 * - ESP32-T7S3-MultiFunction A version of the original S3-MultiFunction board
 *   using a TTGO-T7S3 module.
 * - ESP32-T7S3-MultiFunctionUniversalTurnout A version of the 
 *   T7S3-MultiFunction board using a daughter board for the turnout driver
 *   allowing four different turnout types (Stall Motor, Single Coil, 
 *   Twin Coil, and Servo).
 * - This code will also work on a breadboard version using a ESP32S3 DevKit 
 *   board.
 * 
 * There are configuration options to adjust how the code is compiled for 
 * different hardware options.
 * 
 * 
 * 
 */

static const char rcsid[] = "@(#) : $Id$";

#include "sdkconfig.h"
#include "cdi.hxx"
#if defined(CONFIG_T7S3)
#define TARGETMOD "T7S3"
#elif defined(CONFIG_DEVKIT_BREADBOARD)
#define TARGETMOD "DEVKIT_BREADBOARD"
#else
#define TARGETMOD "BARES3"
#endif
#if defined(CONFIG_SERVO_TURNOUTS)
#define TARGETDAUGHTER " SERVOS"
#else
#define TARGETDAUGHTER ""
#endif
#include "cdidata.hxx"
#include "DelayRebootHelper.hxx"
#include "FactoryResetHelper.hxx"
#include "HealthMonitor.hxx"
#include "fs.hxx"
#include "hardware.hxx"
#include "NodeRebootHelper.hxx"
#include "NvsManager.hxx"

#include <algorithm>
#include <driver/uart.h>
#include <esp_err.h>
#include <esp_log.h>
#include <esp_ota_ops.h>
#include <esp_system.h>
#include <esp_task_wdt.h>
#include <esp32s3/rom/rtc.h>
#include <freertos_includes.h>   
#include <openlcb/SimpleStack.hxx>
#include <freertos_drivers/esp32/Esp32HardwareTwai.hxx>
#include <freertos_drivers/esp32/Esp32BootloaderHal.hxx>
#include <freertos_drivers/esp32/Esp32SocInfo.hxx>
#include <openlcb/MemoryConfigClient.hxx>
#include <openlcb/RefreshLoop.hxx>
#include <openlcb/SimpleStack.hxx>
#include <utils/constants.hxx>
#include <utils/format_utils.hxx>

#include "BootPauseHelper.hxx"
#include "Lamp.hxx"
#include "Mast.hxx"
#include "Blink.hxx"
#include "TrackCircuit.hxx"
#include "Logic.hxx"
#if defined(CONFIG_SERVO_TURNOUTS)
#include <freertos_drivers/esp32/Esp32Ledc.hxx>
#include "ServoTurnoutConfig.hxx"
#include "ServoTurnout.hxx"
#else
#include "Turnout.hxx"
#endif
#include "Points.hxx"
#include "OccupancyDetector.hxx"
#include "Button.hxx"
#include "LED.hxx"
#include "hardware.hxx"
#include "WiFiManager.hxx"
#include "freertos_drivers/esp32/Esp32HardwareI2C.hxx"
#include "freertos_drivers/common/PWM.hxx"
#include "PCA9685PWM.hxx"
#include "SignalLampTester.hxx"


///////////////////////////////////////////////////////////////////////////////
// Increase the CAN RX frame buffer size to reduce overruns when there is high
// traffic load (ie: large datagram transport).
///////////////////////////////////////////////////////////////////////////////
OVERRIDE_CONST(can_rx_buffer_size, 64);
OVERRIDE_CONST(num_memory_spaces, 6);

TrackCircuit *circuits[TRACKCIRCUITCOUNT];

esp32multifunction::ConfigDef cfg(0);
Esp32HardwareTwai twai(CONFIG_TWAI_RX_PIN, CONFIG_TWAI_TX_PIN);
Esp32HardwareI2C i2c("/dev/i2c");


namespace openlcb
{
    /// Name of CDI.xml to generate dynamically.
    const char CDI_FILENAME[] = "/fs/cdi.xml";

    // Path to where OpenMRN should persist general configuration data.
    const char *const CONFIG_FILENAME = "/fs/config";

    // The size of the memory space to export over the above device.
    const size_t CONFIG_FILE_SIZE =
        cfg.seg().size() + cfg.seg().offset();

    // Default to store the dynamic SNIP data is stored in the same persistant
    // data file as general configuration data.
    const char *const SNIP_DYNAMIC_FILENAME = "/fs/config";

    /// Defines the identification information for the node. The arguments are:
    ///
    /// - 4 (version info, always 4 by the standard
    /// - Manufacturer name
    /// - Model name
    /// - Hardware version
    /// - Software version
    ///
    /// This data will be used for all purposes of the identification:
    ///
    /// - the generated cdi.xml will include this data
    /// - the Simple Node Ident Info Protocol will return this data
    /// - the ACDI memory space will contain this data.
    const SimpleNodeStaticValues SNIP_STATIC_DATA =
    {
        4,
        SNIP_PROJECT_PAGE,
        SNIP_PROJECT_NAME,
        SNIP_HW_VERSION,
        SNIP_SW_VERSION
    };

} // namespace openlcb


/// Halts execution with a specific blink pattern for the two LEDs that are on
/// the IO base board.
///
/// @param activity1 Sets the initial state of the Activity1 (Green) LED.
/// @param activity2 Sets the initial state of the Activity2 (Red)   LED.
/// @param period Sets the delay between blinking the LED(s).
/// @param toggle_both Controls if both LEDs will blink or if only the activity
/// LED will blink.
void die_with(bool activity1, bool activity2, unsigned period = 1000
            , bool toggle_both = false)
{
    LED_ACT1_Pin::set(activity1);
    LED_ACT2_Pin::set(activity2);

    while(true)
    {
        if (toggle_both)
        {
            LED_ACT1_Pin::toggle();
        }
        LED_ACT2_Pin::toggle();
        usleep(period);
    }
}

DEFINE_SINGLETON_INSTANCE(BlinkTimer);
PWM* Lamp::pinlookup_[17];
PCA9685PWM pwmchip1;
PCA9685PWMBit LampA0(&pwmchip1,0);
PCA9685PWMBit LampA1(&pwmchip1,1);
PCA9685PWMBit LampA2(&pwmchip1,2);
PCA9685PWMBit LampA3(&pwmchip1,3);
PCA9685PWMBit LampA4(&pwmchip1,4);
PCA9685PWMBit LampA5(&pwmchip1,5);
PCA9685PWMBit LampA6(&pwmchip1,6);
PCA9685PWMBit LampA7(&pwmchip1,7);

PCA9685PWMBit LampB0(&pwmchip1,8);
PCA9685PWMBit LampB1(&pwmchip1,9);
PCA9685PWMBit LampB2(&pwmchip1,10);
PCA9685PWMBit LampB3(&pwmchip1,11);
PCA9685PWMBit LampB4(&pwmchip1,12);
PCA9685PWMBit LampB5(&pwmchip1,13);
PCA9685PWMBit LampB6(&pwmchip1,14);
PCA9685PWMBit LampB7(&pwmchip1,15);


extern "C"
{

void *node_reboot(void *arg)
{
    Singleton<reboothelpers::NodeRebootHelper>::instance()->reboot();
    return nullptr;
}

void reboot()
{
    os_thread_create(nullptr, nullptr, uxTaskPriorityGet(NULL) + 1, 2048
                   , node_reboot, nullptr);
}

ssize_t os_get_free_heap()
{
    return heap_caps_get_free_size(MALLOC_CAP_8BIT);
}

/// Verifies that the bootloader has been requested.
///
/// @return true (always).
///
/// NOTE: On the ESP32 this defaults to always return true since this code will
/// not be invoked through normal node startup.
bool request_bootloader(void)
{
    LOG(VERBOSE, "[Bootloader] request_bootloader");
    // Default to allow bootloader to run since we are not entering the
    // bootloader loop unless requested by app_main.
    return true;
}



/// Updates the state of a status LED.
///
/// @param led is the LED to update.
/// @param value is the new state of the LED.
///
/// NOTE: Currently the following mapping is being used for the LEDs:
/// LED_ACTIVE -> Bootloader LED
/// LED_WRITING -> Bootloader Write LED
/// LED_REQUEST -> Used only as a hook for printing bootloader startup.
void bootloader_led(enum BootloaderLed led, bool value)
{
    LOG(VERBOSE, "[Bootloader] bootloader_led(%d, %d)", led, value);
    if (led == LED_ACTIVE)
    {
        LED_ACT1_Pin::instance()->write(value);
    }
    else if (led == LED_WRITING)
    {
        LED_ACT2_Pin::instance()->write(value);
    }
    else if (led == LED_REQUEST)
    {
        //LOG(INFO, "[Bootloader] Preparing to receive firmware");
        //LOG(INFO, "[Bootloader] Current partition: %s", current->label);
        //LOG(INFO, "[Bootloader] Target partition: %s", target->label);
    }
}

/// Initializes the node specific bootloader hardware (LEDs)
void bootloader_hw_set_to_safe(void)
{
    LOG(VERBOSE, "[Bootloader] bootloader_hw_set_to_safe");
    LED_ACT1_Pin::hw_init();
    LED_ACT2_Pin::hw_init();
}

namespace esp32multifunction {

ConfigUpdateListener::UpdateAction FactoryResetHelper::apply_configuration(
    int fd, bool initial_load, BarrierNotifiable *done)
{
    // nothing to do here as we do not load config
    AutoNotify n(done);
    LOG(VERBOSE, "[CFG] apply_configuration(%d, %d)", fd, initial_load);
    if (!initial_load &&
        Singleton<nvsmanager::NvsManager>::instance()->CheckPersist())
    {
        LOG(WARNING, "[CFG] NVS has been updated requesting a restart.");
        return ConfigUpdateListener::UpdateAction::REBOOT_NEEDED;
    }

    return ConfigUpdateListener::UpdateAction::UPDATED;
}

void FactoryResetHelper::factory_reset(int fd)
{
    LOG(VERBOSE, "[CFG] factory_reset(%d)", fd);
    // set the name of the node to the SNIP model name
    cfg.userinfo().name().write(fd, openlcb::SNIP_STATIC_DATA.model_name);
    cfg.userinfo().description().write(fd, "");
    
    for(int i = 0; i < NUM_OCS; i++)
    {
        cfg.seg().ocs().entry(i).description().write(fd, "");
        CDI_FACTORY_RESET(cfg.seg().ocs().entry(i).debounce);
    }
    for(int i = 0; i < NUM_TURNOUTS; i++)
    {
        cfg.seg().turnouts().entry(i).description().write(fd, "");
#if defined(CONFIG_SERVO_TURNOUTS)
        CDI_FACTORY_RESET(cfg.seg().turnouts().entry(i).servo_normal_percent);
        CDI_FACTORY_RESET(cfg.seg().turnouts().entry(i).servo_reversed_percent);
#endif
    }
    for(int i = 0; i < NUM_POINTSS; i++)
    {
        cfg.seg().points().entry(i).description().write(fd, "");
    }
    for(int i = 0; i < NUM_BUTTONS; i++)
    {
        cfg.seg().buttons().entry(i).description().write(fd, "");
    }
    for(int i = 0; i < NUM_LEDS; i++)
    {
        CDI_FACTORY_RESET(cfg.seg().leds().entry(i).phase);
        CDI_FACTORY_RESET(cfg.seg().leds().entry(i).pulsewidth);
    }
    
#if 1
    for(int i = 0; i < LOGICCOUNT; i++)
    {
        cfg.seg().logics().entry(i).description().write(fd, "");
        CDI_FACTORY_RESET(cfg.seg().logics().entry(i).groupFunction);
        CDI_FACTORY_RESET(cfg.seg().logics().entry(i).logic().logicFunction);
        CDI_FACTORY_RESET(cfg.seg().logics().entry(i).trueAction);
        CDI_FACTORY_RESET(cfg.seg().logics().entry(i).falseAction);
        CDI_FACTORY_RESET(cfg.seg().logics().entry(i).timing().timedelay);
        CDI_FACTORY_RESET(cfg.seg().logics().entry(i).timing().interval);
        CDI_FACTORY_RESET(cfg.seg().logics().entry(i).timing().retriggerable);
        CDI_FACTORY_RESET(cfg.seg().logics().entry(i).v1().trigger);
        CDI_FACTORY_RESET(cfg.seg().logics().entry(i).v1().source);
        CDI_FACTORY_RESET(cfg.seg().logics().entry(i).v1().trackspeed);
        CDI_FACTORY_RESET(cfg.seg().logics().entry(i).v2().trigger);
        CDI_FACTORY_RESET(cfg.seg().logics().entry(i).v2().source);
        CDI_FACTORY_RESET(cfg.seg().logics().entry(i).v2().trackspeed);
        for (int j = 0; j < 4 ; j++)
        {
            CDI_FACTORY_RESET(cfg.seg().logics().entry(i).actions().entry(j).actiontrigger);
        }
    }
    for(int i = 0; i < MASTCOUNT; i++)
    {
        CDI_FACTORY_RESET(cfg.seg().masts().entry(i).processing);
        cfg.seg().masts().entry(i).mastid().write(fd,"");
#ifdef HAVEPWM
        CDI_FACTORY_RESET(cfg.seg().masts().entry(i).fade);
#endif
        for (int j = 0; j < RULESCOUNT; j++)
        {
            CDI_FACTORY_RESET(cfg.seg().masts().entry(i).rules().entry(j).name);
            CDI_FACTORY_RESET(cfg.seg().masts().entry(i).rules().entry(j).speed);
            for (int k = 0; k < LAMPCOUNT; k++)
            {
                CDI_FACTORY_RESET(cfg.seg().masts().entry(i).rules().entry(j).lamps().entry(k).selection);
                CDI_FACTORY_RESET(cfg.seg().masts().entry(i).rules().entry(j).lamps().entry(k).phase);
                CDI_FACTORY_RESET(cfg.seg().masts().entry(i).rules().entry(j).lamps().entry(k).brightness);
                CDI_FACTORY_RESET(cfg.seg().masts().entry(i).rules().entry(j).lamps().entry(k).period);
            }
        }
    }
    for(int i = 0; i < TRACKCIRCUITCOUNT; i++)
    {
        cfg.seg().circuits().entry(i).description().write(fd,"");
    }
#endif
}

}

#if defined(CONFIG_SERVO_TURNOUTS)
openmrn_arduino::Esp32Ledc ledc(TURNOUTSERVOPINS);
#endif

void app_main()
{
    
    //bool stackrunning = false;
    // capture the reason for the CPU reset
    uint8_t reset_reason = Esp32SocInfo::print_soc_info();
    // If this is the first power up of the node we need to reset the flag
    // since it will not be initialized automatically.
    LOG(INFO, "[SNIP] version:%d, manufacturer:%s, model:%s, hw-v:%s, sw-v:%s"
      , openlcb::SNIP_STATIC_DATA.version
      , openlcb::SNIP_STATIC_DATA.manufacturer_name
      , openlcb::SNIP_STATIC_DATA.model_name
      , openlcb::SNIP_STATIC_DATA.hardware_version
      , openlcb::SNIP_STATIC_DATA.software_version);
    bool reset_events = false;
    bool run_bootloader = false;
    bool cleanup_config_tree = false;
    bool test_signal_lamps = false;
    GpioInit::hw_init();

    nvsmanager::NvsManager nvs;
    nvs.init(reset_reason);

    // Ensure the LEDs are both ON for PauseCheck
    LED_ACT1_Pin::instance()->set();
    LED_ACT2_Pin::instance()->set();
    
    LOG(INFO, "[BootPauseHelper] starting...");
    
    nvsmanager::BootPauseHelper pause;
    
    pause.CheckPause();
    LOG(INFO, "[BootPauseHelper] returned...");
    if (BOOT_Pin::instance()->is_clr())
    {
        nvs.force_factory_reset();
    }
    
    // Ensure the LEDs are both OFF when we startup.
    LED_ACT1_Pin::instance()->clr();
    LED_ACT2_Pin::instance()->clr();
    
    // Check for and reset factory reset flag.
    if (nvs.should_reset_config())
    {
        cleanup_config_tree = true;
        nvs.clear_factory_reset();
    }

    if (nvs.should_start_bootloader())
    {
        run_bootloader = true;
        // reset the flag so we start in normal operating mode next time.
        nvs.clear_bootloader();
    }
    
    if (nvs.should_reset_events())
    {
        reset_events = true;
        // reset the flag so we start in normal operating mode next time.
        nvs.clear_reset_events();
    }
    if (nvs.should_test_signal_lamps())
    {
        test_signal_lamps = true;
        nvs.clear_test_signal_lamps();
    }
    nvs.CheckPersist();

    if (run_bootloader)
    {
        LOG(VERBOSE, "[Bootloader] bootloader_hw_set_to_safe");
        LED_ACT1_Pin::hw_init();
        LED_ACT2_Pin::hw_init();
        esp32_bootloader_run(nvs.node_id(), CONFIG_TWAI_TX_PIN, CONFIG_TWAI_RX_PIN, true);
        esp_restart();
    }
    else
    {
        nvs.DisplayNvsConfiguration();
        mount_fs(cleanup_config_tree);
        LOG(INFO, "[esp32multifunction] about to start the Simple Can Stack");
        openlcb::SimpleCanStack stack(nvs.node_id());
        LOG(INFO, "[esp32multifunction] stack started");
        stack.set_tx_activity_led(LED_ACT1_Pin::instance());
        LOG(INFO, "[esp32multifunction] set activity led");
#if CONFIG_OLCB_PRINT_ALL_PACKETS
        stack.print_all_packets();
#endif
        nvs.register_virtual_memory_spaces(&stack);
        openlcb::MemoryConfigClient memory_client(stack.node(), stack.memory_config_handler());
        LOG(INFO, "[esp32multifunction] MemoryConfigClient done.");
        WiFiManager wifi_manager(nvs.station_ssid(),
                                 nvs.station_pass(),
                                 &stack,
                                 cfg.seg().uplinkParams(),
                                 nvs.hostname_prefix(),
                                 nvs.wifi_mode() != 0);
        esp32multifunction::FactoryResetHelper factory_reset_helper;
        LOG(INFO, "[esp32multifunction] FactoryResetHelper done.");
        reboothelpers::DelayRebootHelper delayed_reboot(stack.service());
        LOG(INFO, "[esp32multifunction] DelayRebootHelper done.");
        healthmonitor::HealthMonitor health_mon(stack.service());
        LOG(INFO, "[esp32multifunction] HealthMonitor done.");
        BlinkTimer blinker(stack.executor()->active_timers());
        blinker.start(500000000);
        LOG(INFO, "[esp32multifunction] BlinkTimer done.");
        
        int i = 0;
        Mast *masts[MASTCOUNT];
        Mast *prevMast = nullptr;
        for (i = 0; i < MASTCOUNT; i++) {
            masts[i] = new Mast(stack.node(),cfg.seg().masts().entry(i),prevMast);
            prevMast = masts[i];
        }
        LOG(INFO, "[esp32multifunction] Masts  done.");
        for (i = 0; i < TRACKCIRCUITCOUNT; i++) {
            circuits[i] = new TrackCircuit(stack.node(),cfg.seg().circuits().entry(i));
        }
        LOG(INFO, "[esp32multifunction] TrackCircuits  done.");
        Logic *prevLogic = nullptr;
        Logic *logics[LOGICCOUNT];
        for (i = LOGICCOUNT-1; i >= 0; i--) {
            logics[i] = new Logic(stack.node(), cfg.seg().logics().entry(i),stack.executor()->active_timers(),prevLogic);
            prevLogic = logics[i];
        }
        LOG(INFO, "[esp32multifunction] Logics done.");
#if defined(CONFIG_SERVO_TURNOUTS)
        ledc.hw_init();
        ServoTurnout turnout1(stack.node(), cfg.seg().turnouts().entry<0>(),1000,ledc.get_channel(0));
        ServoTurnout turnout2(stack.node(), cfg.seg().turnouts().entry<1>(),1000,ledc.get_channel(1));
        ServoTurnout turnout3(stack.node(), cfg.seg().turnouts().entry<2>(),1000,ledc.get_channel(2));
        ServoTurnout turnout4(stack.node(), cfg.seg().turnouts().entry<3>(),1000,ledc.get_channel(3));
#else
        Turnout turnout1(stack.node(), cfg.seg().turnouts().entry<0>(),Motor1_Pin());
        Turnout turnout2(stack.node(), cfg.seg().turnouts().entry<1>(),Motor2_Pin());
        Turnout turnout3(stack.node(), cfg.seg().turnouts().entry<2>(),Motor3_Pin());
        Turnout turnout4(stack.node(), cfg.seg().turnouts().entry<3>(),Motor4_Pin());
#endif
        LOG(INFO, "[esp32multifunction] Turnouts done.");
        Points points1(stack.node(), cfg.seg().points().entry<0>(),Points1_Pin());
        Points points2(stack.node(), cfg.seg().points().entry<1>(),Points2_Pin());
        Points points3(stack.node(), cfg.seg().points().entry<2>(),Points3_Pin());
        Points points4(stack.node(), cfg.seg().points().entry<3>(),Points4_Pin());
        LOG(INFO, "[esp32multifunction] Points done.");
        OccupancyDetector od1(stack.node(), cfg.seg().ocs().entry<0>(),OD1_Pin());
        OccupancyDetector od2(stack.node(), cfg.seg().ocs().entry<1>(),OD2_Pin());
        OccupancyDetector od3(stack.node(), cfg.seg().ocs().entry<2>(),OD3_Pin());
        OccupancyDetector od4(stack.node(), cfg.seg().ocs().entry<3>(),OD4_Pin());
        LOG(INFO, "[esp32multifunction] OccupancyDetector done."); 
        Button button1(stack.node(), cfg.seg().buttons().entry<0>(),Button1_Pin());
        Button button2(stack.node(), cfg.seg().buttons().entry<1>(),Button2_Pin());
        Button button3(stack.node(), cfg.seg().buttons().entry<2>(),Button3_Pin());
        Button button4(stack.node(), cfg.seg().buttons().entry<3>(),Button4_Pin());
        LOG(INFO, "[esp32multifunction] Buttons done.");
        LED Led1(stack.node(), cfg.seg().leds().entry<0>(),LED1_Pin());
        LED Led2(stack.node(), cfg.seg().leds().entry<1>(),LED2_Pin());
        LED Led3(stack.node(), cfg.seg().leds().entry<2>(),LED3_Pin());
        LED Led4(stack.node(), cfg.seg().leds().entry<3>(),LED4_Pin());
        LOG(INFO, "[esp32multifunction] LEDs done.");
        openlcb::RefreshLoop points_refresh_loop(stack.node(),{
                                                 points1.polling()
                                                 , points2.polling()
                                                 , points3.polling()
                                                 , points4.polling()
                                                 , od1.polling()
                                                 , od2.polling()
                                                 , od3.polling()
                                                 , od4.polling()
                                                 , button1.polling()
                                                 , button2.polling()
                                                 , button3.polling()
                                                 , button4.polling()
                                             });
        LOG(INFO, "[esp32multifunction] RefreshLoop done.");
        i2c.hw_init(CONFIG_SDA_PIN,CONFIG_SCL_PIN,400000,I2C_NUM_0);
        i2c.scan(I2C_NUM_0);
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

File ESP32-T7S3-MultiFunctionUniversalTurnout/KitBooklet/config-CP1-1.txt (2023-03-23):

User Info.User Name=CP1
User Info.User Description=Control Point 1
Board Configuration.Internal data.Version=0
Board Configuration.Internal data.Next event ID=0
Board Configuration.OccupancyDetectors(0).Description=
Board Configuration.OccupancyDetectors(0).Debounce parameter=3
Board Configuration.OccupancyDetectors(0).Block Occupied=05.01.01.01.22.80.00.00
Board Configuration.OccupancyDetectors(0).Block Clear=05.01.01.01.22.80.00.01
Board Configuration.OccupancyDetectors(1).Description=
Board Configuration.OccupancyDetectors(1).Debounce parameter=3
Board Configuration.OccupancyDetectors(1).Block Occupied=05.01.01.01.22.80.00.02
Board Configuration.OccupancyDetectors(1).Block Clear=05.01.01.01.22.80.00.03
Board Configuration.OccupancyDetectors(2).Description=
Board Configuration.OccupancyDetectors(2).Debounce parameter=3
Board Configuration.OccupancyDetectors(2).Block Occupied=05.01.01.01.22.80.00.04
Board Configuration.OccupancyDetectors(2).Block Clear=05.01.01.01.22.80.00.05
Board Configuration.OccupancyDetectors(3).Description=
Board Configuration.OccupancyDetectors(3).Debounce parameter=3
Board Configuration.OccupancyDetectors(3).Block Occupied=05.01.01.01.22.80.00.06
Board Configuration.OccupancyDetectors(3).Block Clear=05.01.01.01.22.80.00.07
Board Configuration.Turnouts(0).Description=
Board Configuration.Turnouts(0).Normal=05.01.01.01.22.80.00.08
Board Configuration.Turnouts(0).Reversed=05.01.01.01.22.80.00.09
Board Configuration.Turnouts(0).Veto On=05.01.01.01.22.80.00.0A
Board Configuration.Turnouts(0).Veto Off=05.01.01.01.22.80.00.0B
Board Configuration.Turnouts(1).Description=
Board Configuration.Turnouts(1).Normal=05.01.01.01.22.80.00.0C
Board Configuration.Turnouts(1).Reversed=05.01.01.01.22.80.00.0D
Board Configuration.Turnouts(1).Veto On=05.01.01.01.22.80.00.0E
Board Configuration.Turnouts(1).Veto Off=05.01.01.01.22.80.00.0F
Board Configuration.Turnouts(2).Description=
Board Configuration.Turnouts(2).Normal=05.01.01.01.22.80.00.10
Board Configuration.Turnouts(2).Reversed=05.01.01.01.22.80.00.11
Board Configuration.Turnouts(2).Veto On=05.01.01.01.22.80.00.12
Board Configuration.Turnouts(2).Veto Off=05.01.01.01.22.80.00.13
Board Configuration.Turnouts(3).Description=
Board Configuration.Turnouts(3).Normal=05.01.01.01.22.80.00.14
Board Configuration.Turnouts(3).Reversed=05.01.01.01.22.80.00.15
Board Configuration.Turnouts(3).Veto On=05.01.01.01.22.80.00.16
Board Configuration.Turnouts(3).Veto Off=05.01.01.01.22.80.00.17
Board Configuration.Points(0).Description=
Board Configuration.Points(0).Normal=05.01.01.01.22.80.00.18
Board Configuration.Points(0).Reversed=05.01.01.01.22.80.00.19
Board Configuration.Points(1).Description=
Board Configuration.Points(1).Normal=05.01.01.01.22.80.00.1A
Board Configuration.Points(1).Reversed=05.01.01.01.22.80.00.1B
Board Configuration.Points(2).Description=
Board Configuration.Points(2).Normal=05.01.01.01.22.80.00.1C
Board Configuration.Points(2).Reversed=05.01.01.01.22.80.00.1D
Board Configuration.Points(3).Description=
Board Configuration.Points(3).Normal=05.01.01.01.22.80.00.1E
Board Configuration.Points(3).Reversed=05.01.01.01.22.80.00.1F
Board Configuration.Buttons(0).Description=
Board Configuration.Buttons(0).Button Released=05.01.01.01.22.80.00.20
Board Configuration.Buttons(0).Button Pushed=05.01.01.01.22.80.00.21
Board Configuration.Buttons(1).Description=
Board Configuration.Buttons(1).Button Released=05.01.01.01.22.80.00.22
Board Configuration.Buttons(1).Button Pushed=05.01.01.01.22.80.00.23
Board Configuration.Buttons(2).Description=
Board Configuration.Buttons(2).Button Released=05.01.01.01.22.80.00.24
Board Configuration.Buttons(2).Button Pushed=05.01.01.01.22.80.00.25
Board Configuration.Buttons(3).Description=
Board Configuration.Buttons(3).Button Released=05.01.01.01.22.80.00.26
Board Configuration.Buttons(3).Button Pushed=05.01.01.01.22.80.00.27
Board Configuration.LEDS(0).LED Steady, Pulse, or Blink Phase (A-B)=0
Board Configuration.LEDS(0).Pulse width in seconds, 1 to 127=1
Board Configuration.LEDS(0).LED on=05.01.01.01.22.80.00.28
Board Configuration.LEDS(0).LED off=05.01.01.01.22.80.00.29
Board Configuration.LEDS(1).LED Steady, Pulse, or Blink Phase (A-B)=0
Board Configuration.LEDS(1).Pulse width in seconds, 1 to 127=1
Board Configuration.LEDS(1).LED on=05.01.01.01.22.80.00.2A
Board Configuration.LEDS(1).LED off=05.01.01.01.22.80.00.2B
Board Configuration.LEDS(2).LED Steady, Pulse, or Blink Phase (A-B)=0
Board Configuration.LEDS(2).Pulse width in seconds, 1 to 127=1
Board Configuration.LEDS(2).LED on=05.01.01.01.22.80.00.2C
Board Configuration.LEDS(2).LED off=05.01.01.01.22.80.00.2D
Board Configuration.LEDS(3).LED Steady, Pulse, or Blink Phase (A-B)=0
Board Configuration.LEDS(3).Pulse width in seconds, 1 to 127=1
Board Configuration.LEDS(3).LED on=05.01.01.01.22.80.00.2E
Board Configuration.LEDS(3).LED off=05.01.01.01.22.80.00.2F
Board Configuration.LOGIC(0).Logic description=
Board Configuration.LOGIC(0).Group Function=0
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

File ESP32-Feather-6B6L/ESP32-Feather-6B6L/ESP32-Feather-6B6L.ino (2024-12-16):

// -!- C++ -!- //////////////////////////////////////////////////////////////
//
//  System        : 
//  Module        : 
//  Object Name   : $RCSfile$
//  Revision      : $Revision$
//  Date          : $Date$
//  Author        : $Author$
//  Created By    : Robert Heller
//  Created       : Thu Dec 12 21:04:57 2024
//  Last Modified : <241216.1026>
//
//  Description	
//
//  Notes
//
//  History
//	
/////////////////////////////////////////////////////////////////////////////
//
//    Copyright (C) 2024  Robert Heller D/B/A Deepwoods Software
//			51 Locke Hill Road
//			Wendell, MA 01379-9728
//
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
// 
//
//////////////////////////////////////////////////////////////////////////////

static const char rcsid[] = "@(#) : $Id$";

#include <Arduino.h>
#include <SPIFFS.h>
#include <USB.h>
#include <USBCDC.h>

#include <OpenMRNLite.h>
#include "freertos_drivers/arduino/CpuLoad.hxx"
#include "openlcb/TcpDefs.hxx"
#include "utils/GpioInitializer.hxx"

#include "ButtonConfig.h"
#include "Button.h"
#include "LEDConfig.h"
#include "LED.h"
#include "Blink.h"

// Pick an operating mode below, if you select USE_WIFI it will expose this
// node on WIFI. If USE_CAN / USE_TWAI / USE_TWAI_ASYNC are enabled the node
// will be available on CAN.
//
// Enabling both options will allow the ESP32 to be accessible from
// both WiFi and CAN interfaces.
//
// NOTE: USE_TWAI and USE_TWAI_ASYNC are similar to USE_CAN but utilize the
// new TWAI driver which offers both select() (default) or fnctl() (async)
// access.

#define USE_WIFI
//#define USE_TWAI
//#define USE_TWAI_ASYNC

// Uncomment the line below to have all packets printed to the Serial
// output. This is not recommended for production deployment.
//#define PRINT_PACKETS

// uncomment the line below to specify a GPIO pin that should be used to force
// a factory reset when the node starts and the GPIO pin reads LOW.
// NOTE: GPIO 15 is also used for IO16, care must be taken to ensure that this
// GPIO pin is not used both for FACTORY_RESET and an OUTPUT pin.
//#define FACTORY_RESET_GPIO_PIN 15

// Uncomment the line below to configure the native USB CDC for all output from
// OpenMRNLite. When not defined the default UART0 will be used instead.
//
// NOTE: USB CDC is connected to GPIO 19 (D-) and 20 (D+) and can not be
// changed to any other pins.
//#define USE_USB_CDC_OUTPUT

// Uncomment FIRMWARE_UPDATE_BOOTLOADER to enable the bootloader feature when
// using the TWAI device.
//
// NOTE: in order for this to work you *MUST* use a partition schema that has
// two app partitions, typically labeled with "OTA" in the partition name in
// the Arduino IDE.
//#define FIRMWARE_UPDATE_BOOTLOADER

// Configuration option validation

#if defined(USE_TWAI_ASYNC) && defined(USE_TWAI)
#error USE_TWAI_ASYNC and USE_TWAI are mutually exclusive!
#endif

#if defined(USE_TWAI_ASYNC) && !defined(USE_TWAI)
#define USE_TWAI
#endif // USE_TWAI_ASYNC && !USE_TWAI

#if defined(FIRMWARE_UPDATE_BOOTLOADER) && !defined(USE_TWAI)
#error Firmware update is only supported via TWAI, enable USE_TWAI to use this.
#endif

#if ARDUINO_USB_CDC_ON_BOOT && defined(USE_USB_CDC_OUTPUT)
// When ARDUINO_USB_CDC_ON_BOOT = 1 "Serial" will map to USB-CDC automatically
// and will be enabled on startup. We do not need to wrap or otherwise treat it
// any differently.
#undef USE_USB_CDC_OUTPUT
#warning Disabling USE_USB_CDC_OUTPUT since USB-CDC is enabled in Arduino IDE
#endif

#include "config.h"

/// This is the node id to assign to this device, this must be unique
/// on the CAN bus.
static constexpr uint64_t NODE_ID = UINT64_C(0x050101012200); // 05 01 01 01 22 00

#if defined(USE_WIFI)
// Configuring WiFi accesspoint name and password
// ^^^^^^^^^^^^^^^^^^^^^^^^^^^^^^^^^^^^^^^^^^^^^^
// There are two options:
// 1) edit the sketch to set this information just below. Use quotes:
//     const char* ssid     = "linksys";
//     const char* password = "superSecret";
// 2) add a new file to the sketch folder called something.cpp with the
// following contents:
//     #include <OpenMRNLite.h>
//
//     char WIFI_SSID[] = "linksys";
//     char WIFI_PASS[] = "theTRUEsupers3cr3t";

/// This is the name of the WiFi network (access point) to connect to.
const char *ssid = WIFI_SSID;

/// Password of the wifi network.
const char *password = WIFI_PASS;

/// This is the hostname which the ESP32 will advertise via mDNS, it should be
/// unique.
const char *hostname = "esp32mrn";

OVERRIDE_CONST(gridconnect_buffer_size, 3512);
//OVERRIDE_CONST(gridconnect_buffer_delay_usec, 200000);
OVERRIDE_CONST(gridconnect_buffer_delay_usec, 2000);
OVERRIDE_CONST(gc_generate_newlines, CONSTANT_TRUE);
OVERRIDE_CONST(executor_select_prescaler, 60);
OVERRIDE_CONST(gridconnect_bridge_max_outgoing_packets, 2);

#endif // USE_WIFI

#if defined(USE_TWAI)
/// This is the ESP32-S3 pin connected to the CAN Transceiver Rx
/// Assumes Adafruit ESP32-S3 Feather: GPIOA4 == GPIO14
constexpr gpio_num_t CAN_RX_PIN = GPIO_NUM_14;

/// This is the ESP32 pin connected to the  CAN Transceiver Tx
/// Assumes Adafruit ESP32-S3 Feather: GPIOA5 == GPIO8
constexpr gpio_num_t CAN_TX_PIN = GPIO_NUM_8; 

#endif // USE_CAN or USE_TWAI

#if defined(FACTORY_RESET_GPIO_PIN)
static constexpr uint8_t FACTORY_RESET_COUNTDOWN_SECS = 10;
#endif // FACTORY_RESET_GPIO_PIN

/// This is the primary entrypoint for the OpenMRN/LCC stack.
OpenMRN openmrn(NODE_ID);

/// ConfigDef comes from config.h and is specific to this particular device and
/// target. It defines the layout of the configuration memory space and is also
/// used to generate the cdi.xml file. Here we instantiate the configuration
/// layout. The argument of offset zero is ignored and will be removed later.
static constexpr openlcb::ConfigDef cfg(0);

#if defined(FIRMWARE_UPDATE_BOOTLOADER)
// Include the Bootloader HAL implementation for the ESP32. This should only
// be included in one ino/cpp file.
#include "freertos_drivers/esp32/Esp32BootloaderHal.hxx"
#endif // FIRMWARE_UPDATE_BOOTLOADER

#if defined(USE_WIFI)
Esp32WiFiManager wifi_mgr(ssid, password, openmrn.stack(), cfg.seg().wifi());
#endif // USE_WIFI

#if defined(USE_TWAI)
Esp32HardwareTwai twai(CAN_RX_PIN, CAN_TX_PIN);
#endif // USE_TWAI
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

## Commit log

2022-09-22 Add Common MCU LCC board.
    [BBBHalfSiding-temp.sch, BBBHalfSiding.kicad_pcb, BBBHalfSiding.sch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]
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2022-09-23 Almost done with the schematic.
    [Buttons.sch, CanTransciver.sch, LEDDrivers.sch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]
2022-09-25 Nearing completion of LPC176x_MultiFunction.
    [Buttons.sch, CanTransciver.sch, LEDDrivers.sch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]
2022-09-25 Completed LPC176x_MultiFunction: TODO: cleanup Silk and Fab, add copyright, labels, etc.
    [LPC176x_MultiFunction.kicad_pcb]
2022-09-25 Completed LPC176x MultiFunction board.
    [LPC176x_MultiFunction.kicad_pcb]
2022-09-25 Start on ESP32-C3-Booster firmware.
    [$PocketBeagleCommandStation.sch, BBBCommandStation.kicad_pcb, BBBCommandStation.sch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]
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2022-10-07 Start on ESP32-S3/LCC SMINI replacement.
    [CanTransciver.sch, ESP32-S3-MultiIO.kicad_pcb, ESP32-S3-MultiIO.sch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]
2022-10-08 Completed ESP32-S3-MultiIO (LCC SMINI replacement).
    [CanTransciver.sch, Card0.sch, Card1.sch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]
2022-10-08 Completed (untested) firmware for ESP32-S3-MultiIO.
    [esp32multiio-partitions.csv]
2022-10-09 Created mimimual node to test I2C driver.
    [$PocketBeagleMultifuntion.sch, 16LedDriver.sch, Buttons.sch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]
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2022-10-09 Added ESP32-S3 Mega MultiFunction.
    [Buttons.sch, CanTransciver.sch, ESP32-S3-MegaMultiFunction.kicad_pcb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]
2022-10-10 First four motors done.
    [ESP32-S3-MegaMultiFunction.kicad_pcb]
2022-10-10 Completed Stall Motors.
    [ESP32-S3-MegaMultiFunction.kicad_pcb]
2022-10-11 Completed OD batch 1.
    [ESP32-S3-MegaMultiFunction.kicad_pcb, OccupancyDetectors.sch]
2022-10-11 Completed ODs and LED/Drivers.
    [ESP32-S3-MegaMultiFunction.kicad_pcb, LEDDrivers.sch]
2022-10-11 Moved LCC/CAN transceiver circuit.
    [ESP32-S3-MegaMultiFunction.kicad_pcb]
2022-10-11 ESP32-S3-MegaMultiFunction is basically complete. TODO: clean up silk and fab.
    [ESP32-S3-MegaMultiFunction.kicad_pcb]
2022-10-12 Start on firmware for ESP32-S3-MegaMultiFunction board.
    [esp32megamultifunction-partitions.csv]
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2022-10-14 Working on BOM, corrected some transistor footprints, etc.
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2022-10-24 Fix footprint for OC Diodes.
    [ESP32-S3-MultiFunction.kicad_pcb, OccDetect4.sch]
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2022-11-15 Updating documentation (Yard Ladder).
    [ESP32S3-YardLadderRouteSelector.fzz]
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2022-11-16 Add missing resistors on the bases of Q3 and Q4.
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2022-12-04 Change USB-MicroB to USB-C.
    [Buttons4LEDs4.sch, CAN_Transceiver.sch, ESP32-MCU.sch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]
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2022-12-12 Update to new PBs.
    [ESP32-MCU.sch, ESP32-S3-MultiFunction.kicad_pcb]
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2022-12-25 Add test signal lamp boot flag, fix PCA9685PWM bug (incorrecort constructor for lamp control struct).
    [BootPauseHelper.cpp, esp32pwmhalfsiding.cpp]
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2022-12-29 Revert to chip version, USB-C, replace reset and boot buttons.
    [Buttons4LEDs4.sch, CAN_Transceiver.sch, ESP32-MCU.sch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]
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2023-01-03 Update Boot and reset switches.
    [ESP32-MCU.sch, ESP32-S3-MultiFunction.kicad_pcb]
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2023-01-15 Created firmware for esp32octalservo.
    [esp32octalservo-partitions.csv]
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2023-01-16 Fix Fritzing: map the server number headers to the corrent GPIOs.
    [ESP32-OctalServo.fzz]
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2023-01-17 Fix direction of CAN RX
    [ESP32-OctalServo.sch, MCU.sch]
2023-01-17 Start on S3 DevKit version of OctalServo.
    [CanTransciver.sch, ESP32-S3DK-OctalServo.kicad_pcb, ESP32-S3DK-OctalServo.sch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]
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2023-01-17 Complete alternitive ESP32 Octal Server boards.
    [CanTransciver.sch, ESP32-S3WROOM-OctalServo.kicad_pcb, ESP32-S3WROOM-OctalServo.sch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]
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2023-01-20 Adjust memory allocations to avoid crashes.
    [esp32pwmhalfsiding.cpp]
2023-01-30 Start on Single Coil (eg Kato) switch machine driver board.
    [8SingleCoilSM.sch, CanTransciver.sch, ESP32-S3DK-OctalSingleCoil.kicad_pcb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]
2023-01-30 Almost done with ESP32-S3DK-OctalSingleCoil.
    [8SingleCoilSM.sch, CanTransciver.sch, ESP32-S3DK-OctalSingleCoil.kicad_pcb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]
2023-01-31 Starting on ESP32 S3 Twin Coil Switch Machine node.
    [8TwinCoilSM.sch, CAN_Transciver.sch, ESP32-S3DK-OctalTwinCoil.kicad_pcb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]
2023-01-31 Complete ESP32 S3 Twin Coil Switch Machine node.
    [ESP32-S3DK-OctalTwinCoil.kicad_pcb]
2023-01-31 Add 3V3=>5V level shifters (74LS125s) to servo control lines.
    [CanTransciver.sch, ESP32-S3DK-OctalServo.kicad_pcb, ESP32-S3DK-OctalServo.sch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]
2023-01-31 Firmware for coil SM boards.
    [esp32octalcoilsm-partitions.csv]
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2023-02-05 Add T7_S3 OctalBuffer board.
    [CanTransciver.sch, ESP32-Mini32-OctalBuffer.kicad_pcb, ESP32-Mini32-OctalBuffer.sch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]
2023-02-05 Start on the firmware for the buffer board.
    [esp32octalbuffer-partitions.csv]
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2023-02-10 Start on T7S3 version of MultiFunction.
    [Buttons4LEDs4.sch, CAN_Transceiver.sch, ESP32-MCU.sch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]
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2023-02-12 Starting on Turnout Daughter boards.
    [Buttons4LEDs4.sch, CAN_Transceiver.sch, ESP32-MCU.sch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]
2023-02-12 Completed single coil Turnout Daughter board.
    [SC-DaughterBoard.kicad_pcb, SC-DaughterBoard.sch, TC-DaughterBoard.kicad_pcb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]
2023-02-12 Started Twin Coil and Servo Turnout Daughter boards.
    [TC-DaughterBoard.sch, TS-DaughterBoard.sch]
2023-02-13 Completed Twin Coil daughter board.
    [TC-DaughterBoard.kicad_pcb, TC-DaughterBoard.sch]
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2023-02-21 Add support standoffs for turnout daughter boards.
    [ESP32-T7S3-MultiFunctionUniversalTurnout.kicad_pcb, SC-DaughterBoard.kicad_pcb, SM-DaughterBoard.kicad_pcb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]
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2023-02-23 Minor updates to ESP32-T7S3-MultiFunctionUniversalTurnout.
    [Buttons4LEDs4.sch, CAN_Transceiver.sch, ESP32-MCU.sch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]
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2023-03-05 Fix error on SC-DaughterBoard.
    [SC-DaughterBoard.kicad_pcb]
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2023-03-24 Add missing part number.
    [TS-DaughterBoard.sch]
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2023-04-08 Add the rest of the Arduino GPIO pins.
    [ESP32-T7S3-ArduinoBase.kicad_pcb, ESP32-T7S3-ArduinoBase.sch]
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2023-06-02 Upgrade KiCAD files, fix board issues with ESP32-T7S3-MultiFunctionUniversalTurnout.
    [ESP32-T7S3-MultiFunctionUniversalTurnout.kicad_pcb]
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2023-08-05 Add BOOT button (force factory reset).
    [esp32multifunction.cpp]
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2023-11-06 Fix component part number.
    [ESP32-MCU.sch]
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2024-12-15 Minor compile errors fixed.
    [ESP32-Feather-6B6L.ino]
2024-12-16 Add Factory Reset lines.
    [ESP32-Feather-6B6L.ino]
2025-01-10 Fix boot pause code.
    [BootPauseHelper.cpp]
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2025-05-10 Add MPN Part numbers from LCSC part numbers.
    [CanTransciver.kicad_sch, ESP32-Mini32-OctalBuffer.kicad_sch, PowerSupply.kicad_sch]
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2025-11-28 Atlas Light Board WiFi LCC Traction schem. complete.
    [AtlasLightBoardWiFiLCCTraction.kicad_pcb, AtlasLightBoardWiFiLCCTraction.kicad_sch]
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2025-12-01 Adjust things to increase heatsinking for 3.3 regulator.
    [AtlasLightBoardWiFiLCCTraction.kicad_pcb, AtlasLightBoardWiFiLCCTraction.kicad_sch]
2025-12-02 Replace LDO with switching PS.
    [ASPI-0628-3R9M-T1.stp, AtlasLightBoardWiFiLCCTraction.kicad_pcb, AtlasLightBoardWiFiLCCTraction.kicad_sch]
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2025-12-09 Fine tune mounting hole positions (from accurate measurements).
    [AtlasLightBoardWiFiLCCTraction.kicad_pcb, AtlasLightBoardWiFiLCCTraction.kicad_sch]
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2025-12-11 Minor fixes to function code.
    [ESP32S3Train.cpp]
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2026-04-26 Fix issues with motor PWM freq/period setting.
    [ESP32S3Train.cpp]
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2026-07-08 Fix minor part property problem.
    [AtlasLightBoardWiFiLCCTraction.kicad_pcb, AtlasLightBoardWiFiLCCTraction.kicad_sch]
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

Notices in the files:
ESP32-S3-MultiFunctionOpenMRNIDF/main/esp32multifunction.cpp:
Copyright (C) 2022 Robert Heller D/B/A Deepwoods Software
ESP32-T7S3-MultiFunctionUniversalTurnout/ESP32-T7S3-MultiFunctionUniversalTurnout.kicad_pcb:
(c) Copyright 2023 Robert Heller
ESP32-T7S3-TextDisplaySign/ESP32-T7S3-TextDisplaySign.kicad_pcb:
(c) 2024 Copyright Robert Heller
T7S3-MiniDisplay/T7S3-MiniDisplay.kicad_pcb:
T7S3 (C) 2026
